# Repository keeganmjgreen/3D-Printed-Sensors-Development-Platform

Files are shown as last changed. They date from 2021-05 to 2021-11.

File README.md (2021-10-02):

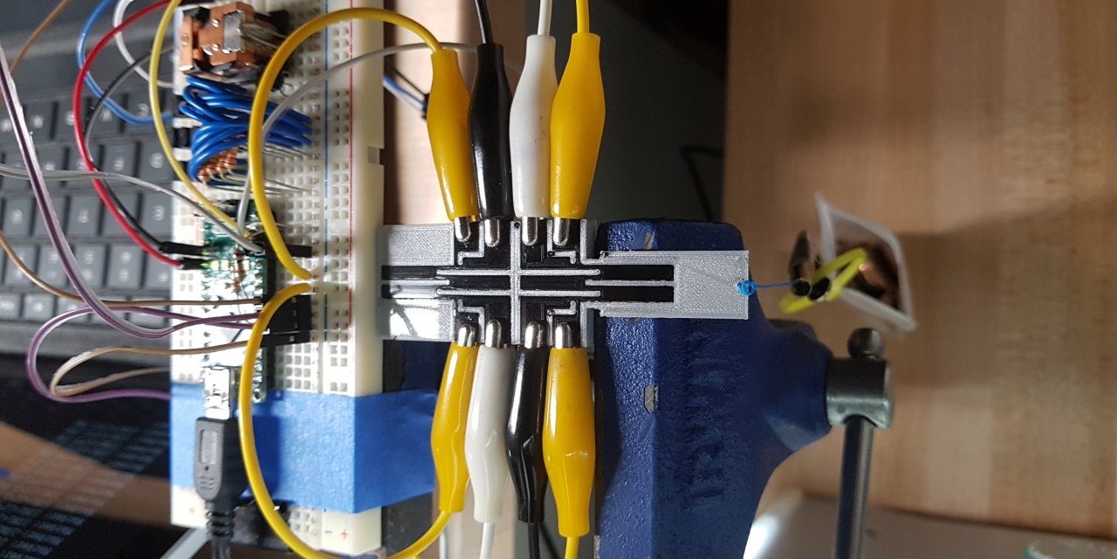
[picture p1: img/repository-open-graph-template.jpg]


----

# 3D Printed Sensors Development Platform

[Read the Docs project](https://3d-printed-sensors-development-platform.readthedocs.io/en/latest/index.html)



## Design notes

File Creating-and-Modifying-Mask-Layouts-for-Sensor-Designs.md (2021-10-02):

[Download as PDF](https://raw.githubusercontent.com/keeganmjgreen/3D-Printed-Sensors-Development-Platform/main/pdf/Creating-and-Modifying-Mask-Layouts-for-Sensor-Designs.pdf)

----

# Creating and Modifying 'Mask Layouts' for Sensor Designs

Please refer to the 'mask layouts' of our sensor designs as a starting point. They have been provided as image templates.

 1. Decide on the largest and/or most common/prevalent *resolution* $\lambda_{\,\textsf{macro}\,}$ expected for the mask layout. For example, 1 mm for most design features. \

 2. Estimate the bounding size of the mask layout. For example, layout height $H_{\,\textsf{layout}}$ = sensor width = 25 mm, layout width $W_{\,\textsf{layout}}$ = sensor length = 45 mm. \

 3. Using image editing software, create an image of height $H_{\,\textsf{layout}}\,/\,\lambda_{\,\textsf{macro}\,}$ pixels and width $W_{\,\textsf{layout}}\,/\,\lambda_{\,\textsf{macro}\,}$ pixels. Set its *image resolution* to $1\,/\,\lambda_{\,\textsf{macro}\,}$ pixels, for reference. Keep in mind the software units. For example:
    
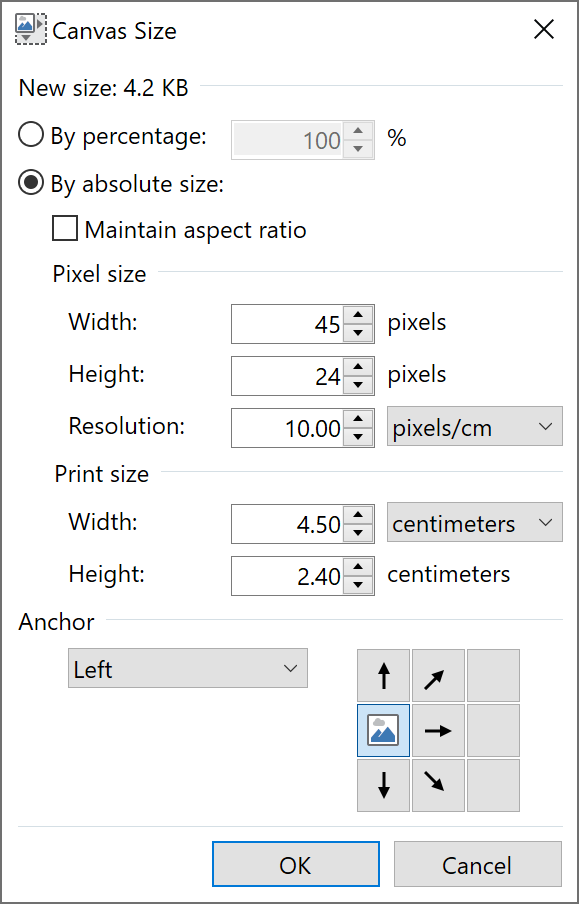
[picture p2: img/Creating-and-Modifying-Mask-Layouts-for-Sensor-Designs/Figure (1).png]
     \

 4. Enable the pixel grid and rulers, if available. Using the grid will make the mask layout easier to draw.
    
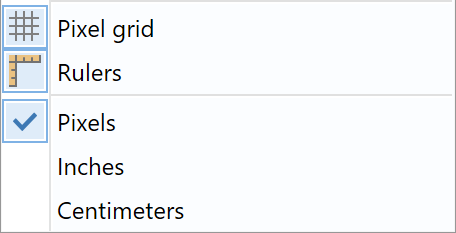
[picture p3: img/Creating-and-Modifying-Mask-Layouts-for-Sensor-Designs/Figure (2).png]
     \

 5. On a pixel scale, create the largest design features (of resolution $\lambda_{\,\textsf{macro}\,}$, that is) first. For example:
    
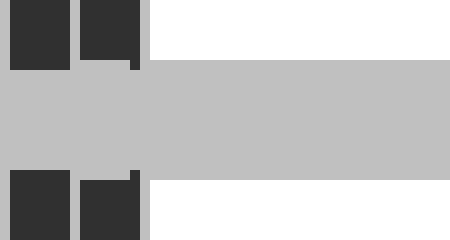
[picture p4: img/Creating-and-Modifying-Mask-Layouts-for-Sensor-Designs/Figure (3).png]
     \

 6. Resize the image to be of height $H_{\,\textsf{layout}}\,/\,\lambda_{\,\textsf{micro}\,}$ pixels and width $W_{\,\textsf{layout}}\,/\,\lambda_{\,\textsf{micro}\,}$ pixels, where $\lambda_{\,\textsf{micro}\,}$ is the smallest underlying resolution. Update its *image resolution* to $1\,/\,\lambda_{\,\textsf{micro}\,}$ pixels, for reference, again. Keep in mind the software units. Use the *nearest neighbor* resampling method and maintain the *aspect ratio*. For example:
    
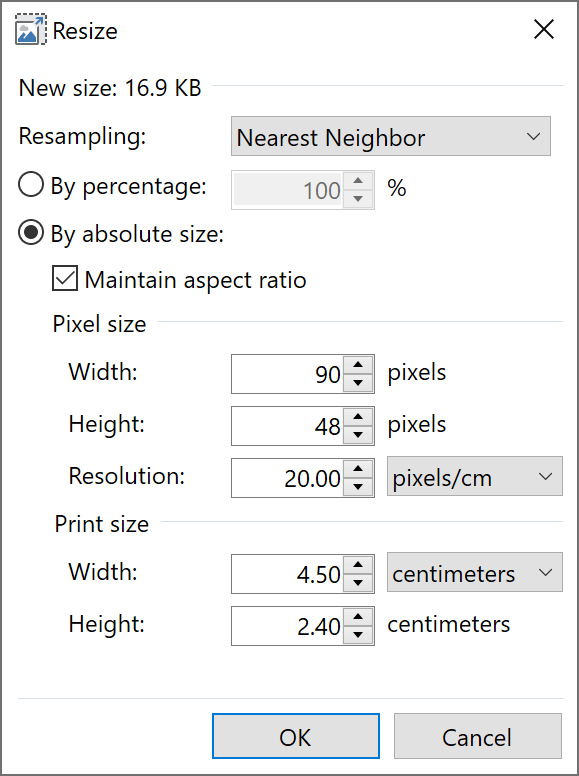
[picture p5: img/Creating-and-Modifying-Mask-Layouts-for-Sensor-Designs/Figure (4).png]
     \

 7. On the new pixel scale, create the smallest design features (of resolution $\lambda_{\,\textsf{micro}\,}$, that is). For example:
    
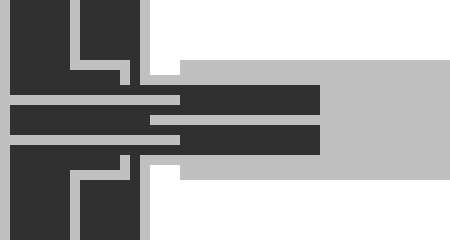
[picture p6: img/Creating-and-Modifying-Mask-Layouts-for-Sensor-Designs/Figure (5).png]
     \

Tip: Use named image layers (as analogous to *SolidWorks* features). For example:

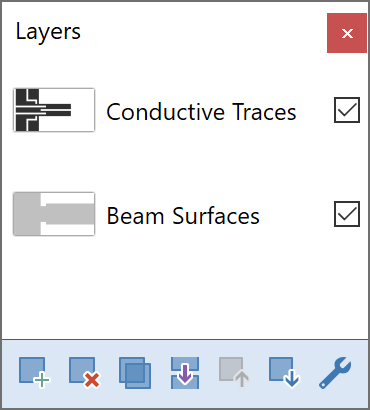
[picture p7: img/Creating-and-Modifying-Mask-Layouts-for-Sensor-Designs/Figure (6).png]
 \

----

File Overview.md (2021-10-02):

[Download as PDF](https://raw.githubusercontent.com/keeganmjgreen/3D-Printed-Sensors-Development-Platform/main/pdf/Overview.pdf)

----

# About This Manual #

This manual describes every aspect of the Pithon platform including how to customize, print, calibrate and use Pithon sensors. The manual starts with an overview of Pithon sensors. Next, the process of 3D printing sensors will be described, emphasizing strategies for improving reliability and consistency of printed sensors. Tools and resources for customizing sensors to your unique application will then be presented. Finally, calibration methods are provided to ensure that printed sensors are delivering reliable results. 

# Overview #

Pithon is a set of designs, tools, documentation, and software to allow anyone to customize and 3D print their own sensors. Monti 3D Printing Solutions currently offers support for temperature sensors, force sensors, and accelerometers. We are currently developing designs for a humidity sensor, environmental sensor which can measure temperature and humidity simultaneously, and a magnetic field sensor. These sensors should be released by the end of August 2021. Pithon is a fully modular embedded sensor platform wherein users can select which sensors and functionality they require, modify sensor designs to their unique application, and easily embed their sensors into any structure. The image below displays example Pithon sensors. 

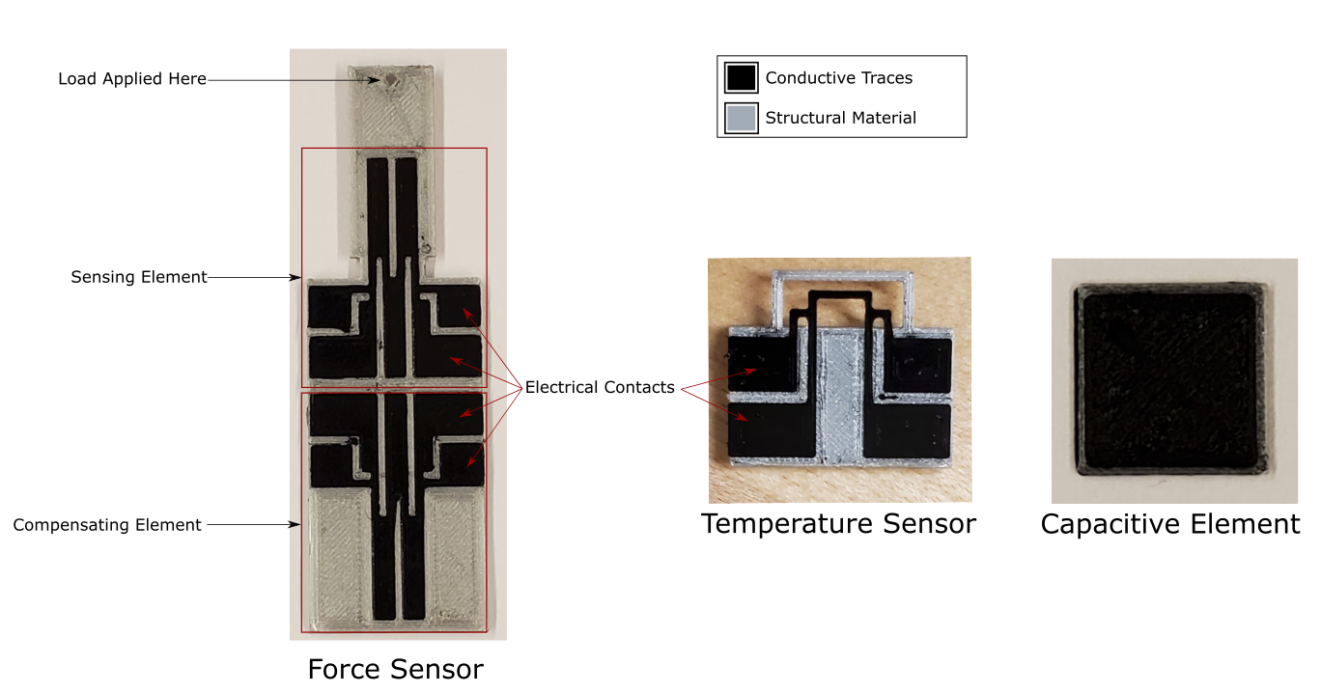
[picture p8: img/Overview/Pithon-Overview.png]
Pithon Overview


Using only 2 materials, a conductive and a structural 3D printing filament, Pithon sensors can be 3D printed in a single-step manufacturing process. After the sensors are produced, users can choose whether to perform additional steps to improve sensor performance, such as adding a metal proof mass to improve an accelerometer's sensitivity. Complete sensors can be printed for about $1 CAD in an hour. 

## Temperature Sensor ##

Pithon's temperature sensor features a small, but robust design. A protective covering, or shroud, protects the sensor in case an impact occurs. The sensor's small design allows for a rapid response to variations in temperature, making it ideal for applications that involve rapid heating and cooling cycles. This sensor is very sensitive to variations in temperature, its resistance increases ~1.5 times when the sensor is heated to 50 °C.

## Force Sensor ##

Our force sensor is a comprehensive design, automatically correcting force measurements for variations in environmental conditions, such as temperature. The force sensor consists of conductive traces along a cantilever beam. When a mass, or force, is applied to the free end of the beam, the beam will bend causing the conductive traces to either expand or compress, thereby changing their resistance. An optional Compensating Element is included that provides automatic compensation for variations in environmental conditions.

## Accelerometer ##

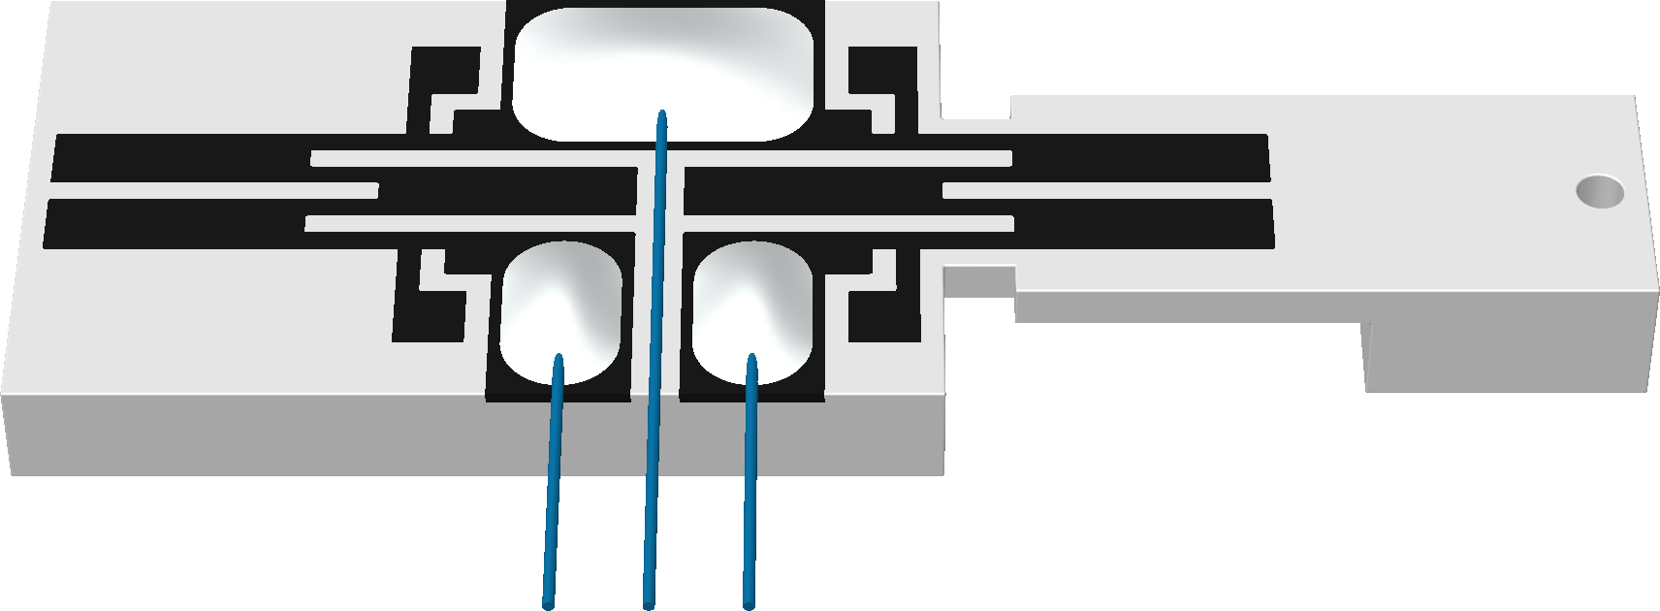
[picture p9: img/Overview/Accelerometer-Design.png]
Accelerometer Design


Pithon's accelerometer is similar in design to our force sensor. Users have the option of installing a metal ball in the accelerometer to improve its sensitivity. The ball is installed in a single-step process by pressing the ball into its corresponding hole. Monti 3D Printing Solutions is actively characterizing the performance of our accelerometers and will update this description with performance characteristics shortly.   

----

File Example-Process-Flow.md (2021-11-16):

[Download as PDF](https://raw.githubusercontent.com/keeganmjgreen/3D-Printed-Sensors-Development-Platform/main/pdf/Example-Process-Flow.pdf)

----

<iframe width="420" height="315" src="https://www.youtube.com/embed/nedxR-Wya6k" title="YouTube video player" frameborder="0" allow="accelerometer; autoplay; clipboard-write; encrypted-media; gyroscope; picture-in-picture" allowfullscreen></iframe>

# Example Process Flow

This section further explores the Pithon platform for 3D printed sensors. \
 \
How do implementations of the Pithon platform get made? How will you produce 3D printed sensors for yourself? What does the process look like? To answer these questions, we will walk through an example process flow. \

The process begins with continuous fabrication, building your design from the ground up using conductive and structural plastics. \

First, electrically conductive traces are deposited onto the 3D printing surface. These will make up the electrical terminals and sensing elements of your accelerometer and temperature sensor:

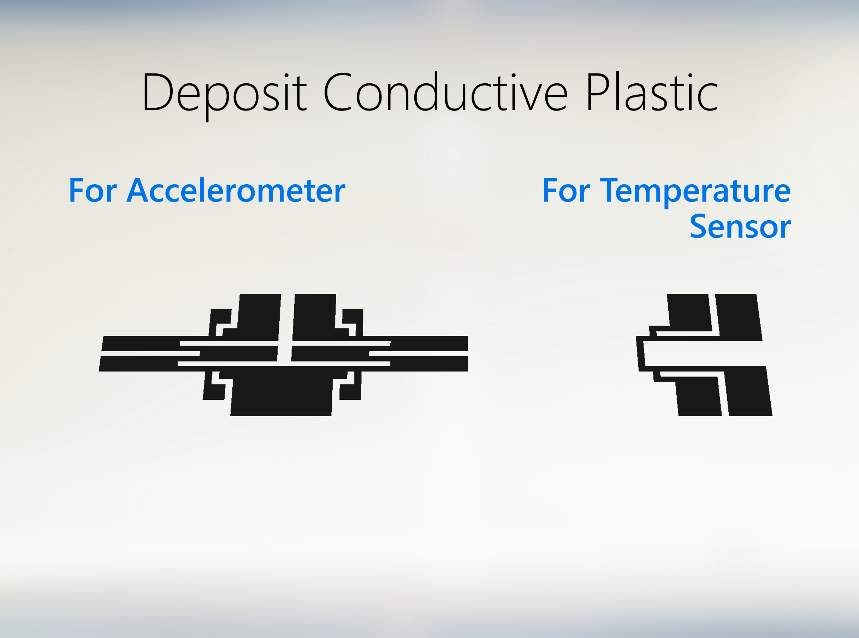
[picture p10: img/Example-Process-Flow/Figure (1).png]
Deposit Conductive Plastic
 \

The conductive traces are surrounded with with what will become your enclosing structure of arbitrary size and shape:

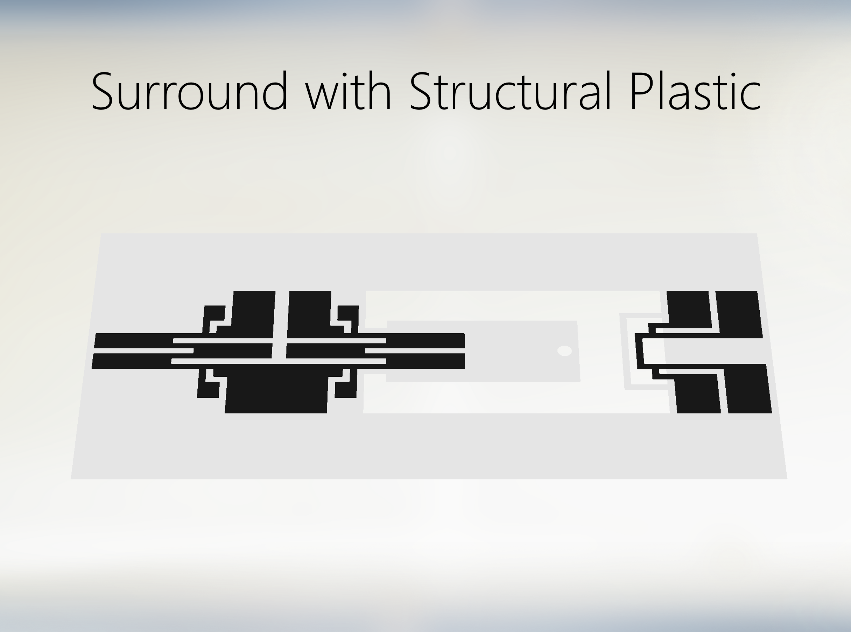
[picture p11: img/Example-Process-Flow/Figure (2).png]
Surround with Structural Plastic
 \

The conductive traces are covered as required with more of their enclosing structure:

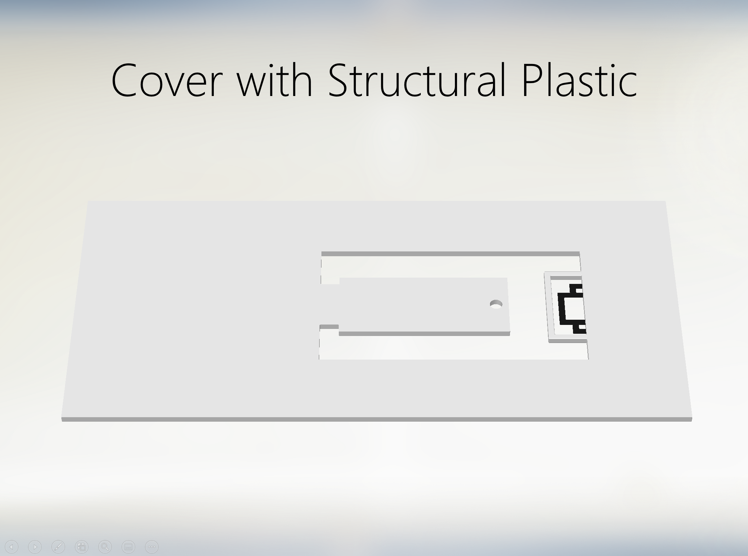
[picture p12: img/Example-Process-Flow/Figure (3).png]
Cover with Structural Plastic
 \

A cantilever beam for your accelerometer has been printed:

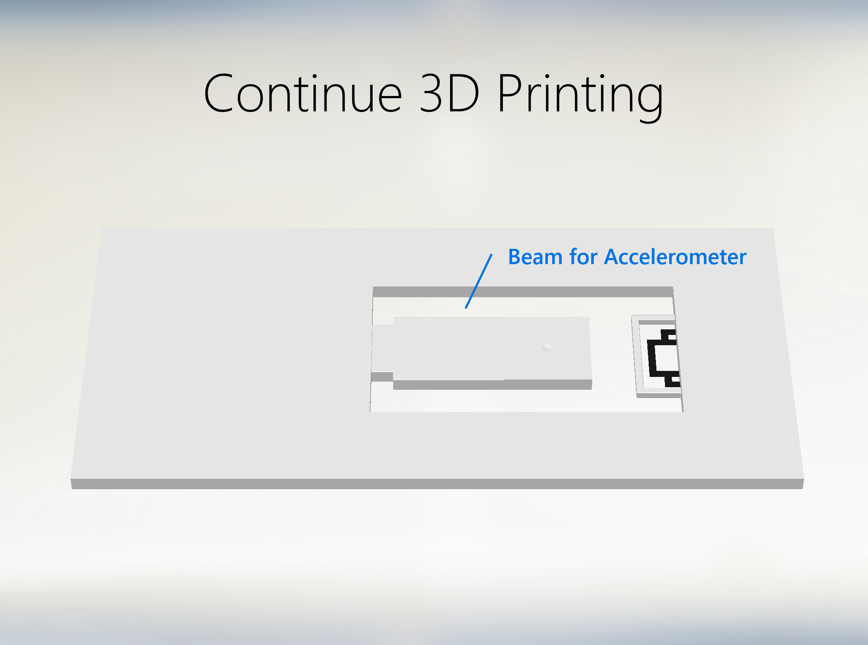
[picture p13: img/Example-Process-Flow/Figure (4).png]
Continue 3D Printing
 \

Now, the 3D printing process continues -- layer by layer -- leaving more space for a cavity:

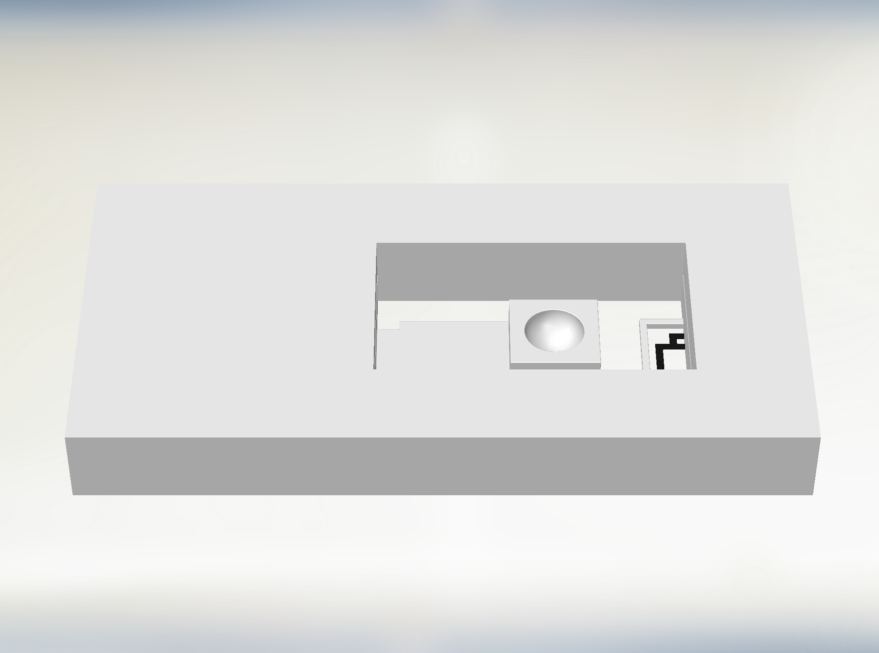
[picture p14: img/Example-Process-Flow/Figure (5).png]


By this point, the conductive 3D printing filament would have been swapped out for dissolvable filament for use as a temporary filler material to support upcoming layers. Alternatively, the cavity walls would slope both upward and *inward* to support subsequent layers, meaning that you wouldn't have to use a temporary support structure. \

You press-fit a steel ball into the space provided at the end of your accelerometer's cantilever beam:

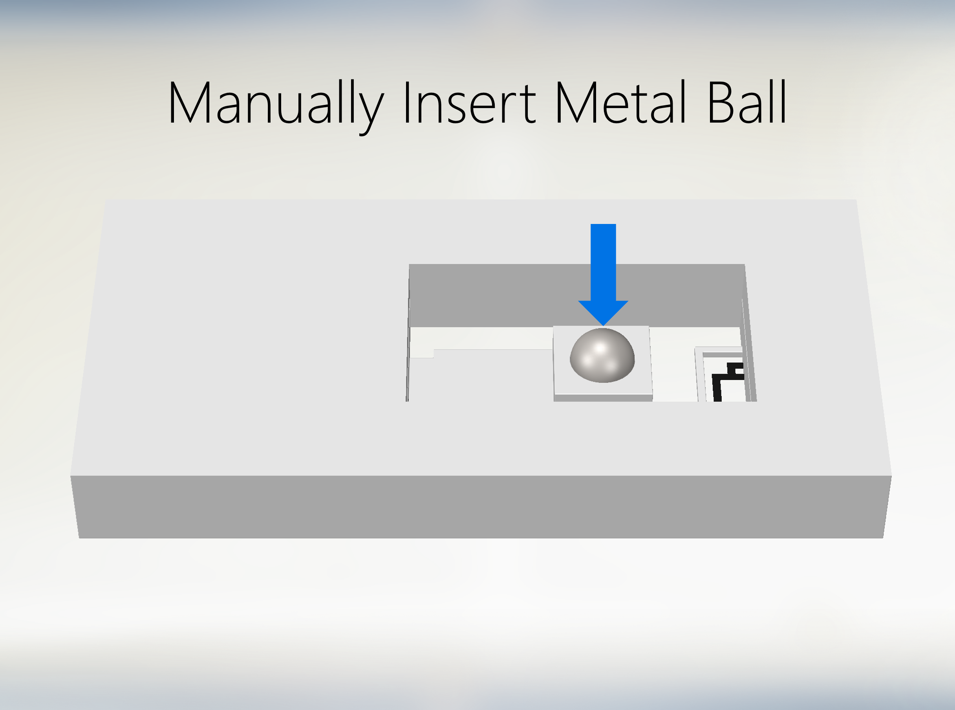
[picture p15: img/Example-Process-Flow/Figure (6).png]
Manually Insert Metal Ball


This will make it especially sensitive to acceleration. This weight is a *proof mass*. Because it is metallic, your accelerometer can also be used as a magnetic field sensor. \

The cavity is covered with the rest of your arbitrarily shaped enclosing structure:

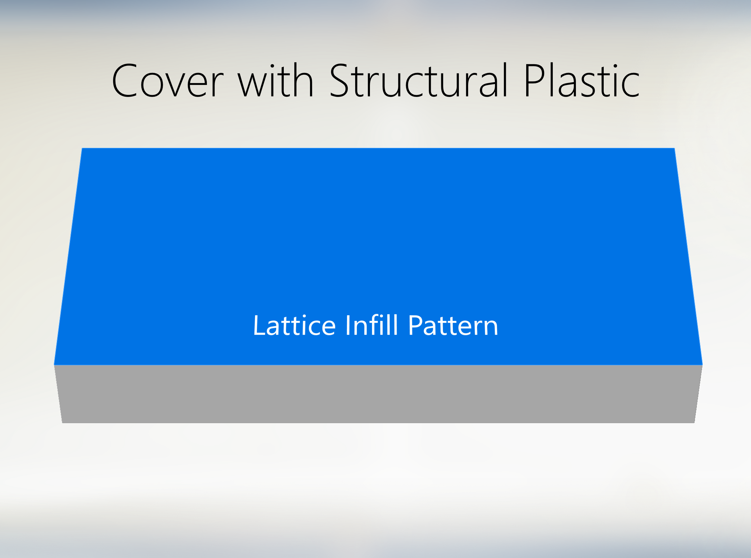
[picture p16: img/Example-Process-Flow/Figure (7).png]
Cover With Structural Plastic


Note that especially by this point, the 3D printed part would be partially made up of a lattice -- this is the *infill pattern*. \

The 3D printing process of our part is soon complete. \

You remove your part from the surface of your 3D printer. It was printed upside-down. This served four purposes:

 1. Made it so that any problems with the conductive printing filament were detected early.
 2. Made the conductive plastic adhere to the surface of your 3D printer better.
 3. Improved the surface finish of your embedded sensors.
 4. Allowed your sensing elements to be as thin as 60 microns, such as for your temperature sensor. \

A Pithon accelerometer and Pithon temperature sensor have been embedded into your arbitrary part. This design, for example, can be readily used for evaluation purposes as part of the Pithon platform:

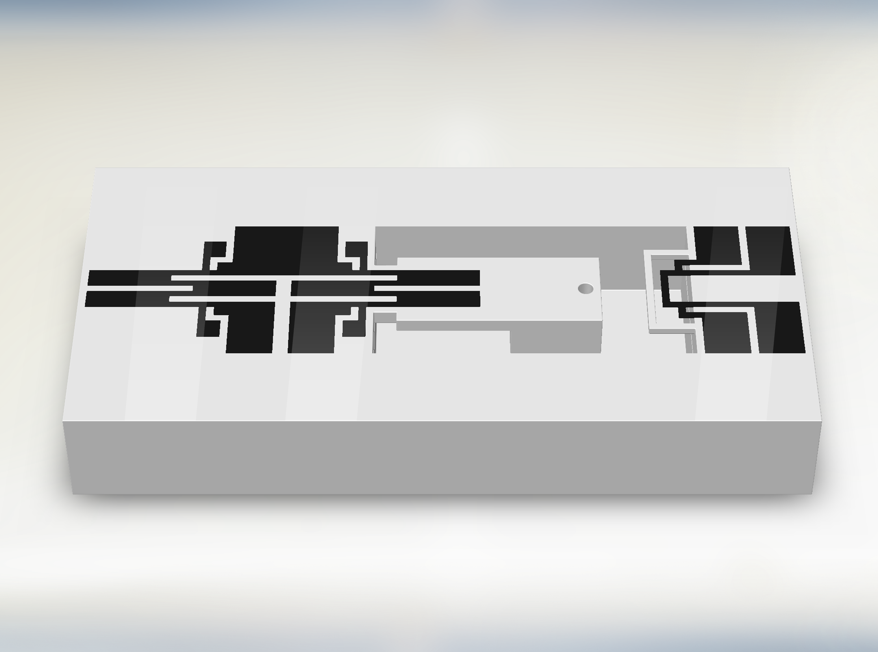
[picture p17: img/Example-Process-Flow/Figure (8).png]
 \

This is your embedded accelerometer:

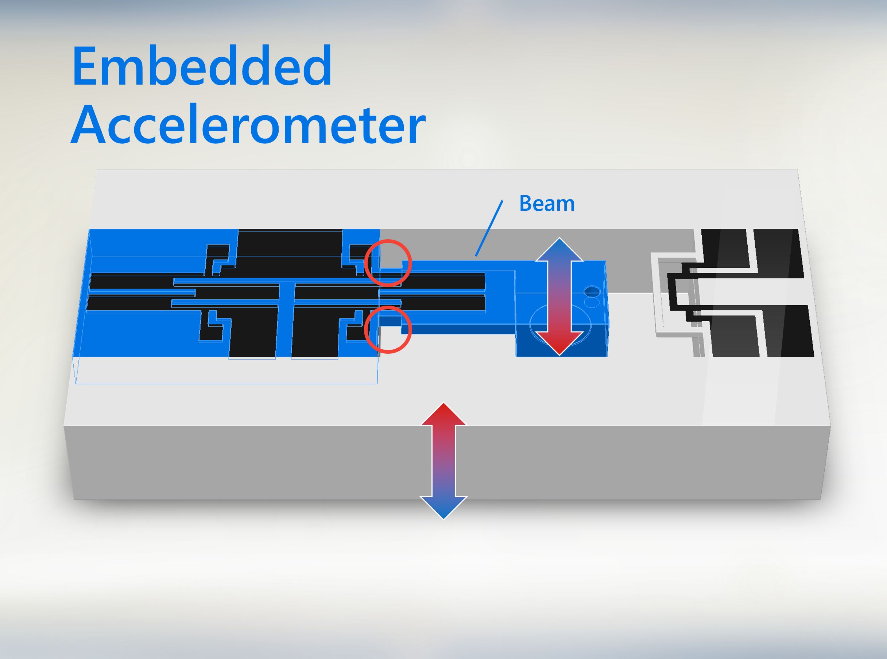
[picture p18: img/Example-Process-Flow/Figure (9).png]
Embedded Accelerometer


When the whole part speeds up or slows down, its cantilever beam bends up or down depending on the direction and amount of the acceleration it experiences. The material making up the top half of the beam gets compressed or stretched, especially at its base and on its surface. This is why two strategically sized notches are placed in the base as shown. They 'concentrate' its mechanical stress toward its sensing element, which is at the beam surface. This makes it more sensitive to acceleration.

The accelerometer may also be calibrated as a force sensor or magnetic field sensor under certain conditions (see end of section [**Pithon Accelerometer**](https://3d-printed-sensors-development-platform.readthedocs.io/en/latest/Pithon-Accelerometer.html)). \

This is your accelerometer's primary set of conductive traces:

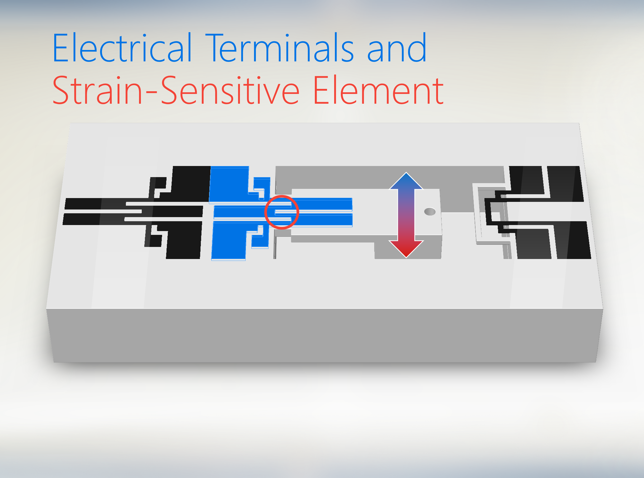
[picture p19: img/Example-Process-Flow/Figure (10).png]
Electrical Terminals and Strain-Sensitive Element


The zig-zag pattern in the middle is what forms its sensing element, a *strain gauge*, whose electrical resistance readily changes with mechanical strain. But the conductive traces' resistance also changes with temperature and humidity. \

This is where your accelerometer's secondary set of conductive traces comes into play:

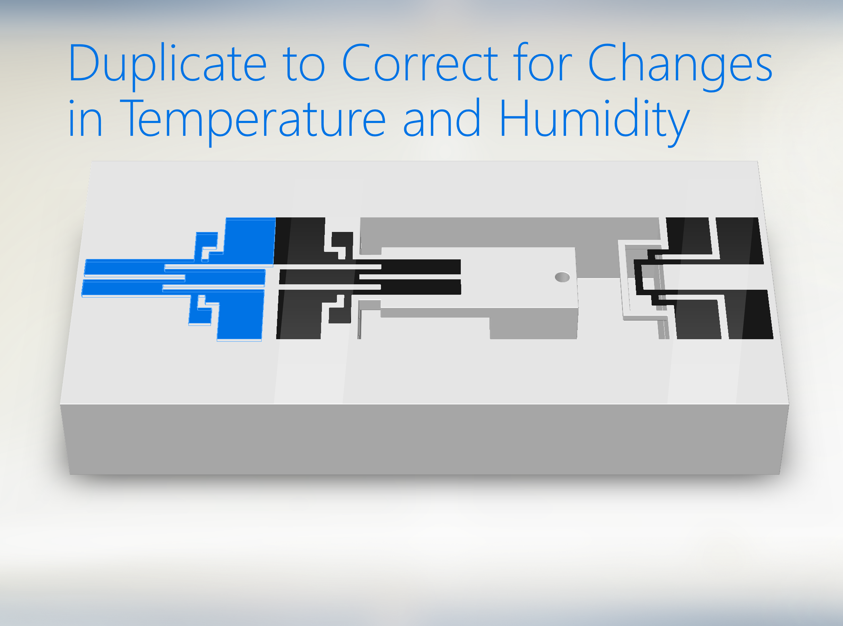
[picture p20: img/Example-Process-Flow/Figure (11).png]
Duplicate to Correct for Changes in Temperature and Humidity


The secondary set can share an electrical terminal with the primary set and is its mirror image. But unlike the primary set, it isn't on a flexible beam. Because of this, it isn't sensitive to absent mechanical strain -- just temperature and humidity. These two "environmental conditions" are shared by both sets of conductive traces. Since the primary set responds to acceleration and environmental conditions similarly, and this secondary set responds only to the same environmental conditions, the acceleration by itself becomes known. \

This is your embedded temperature sensor:

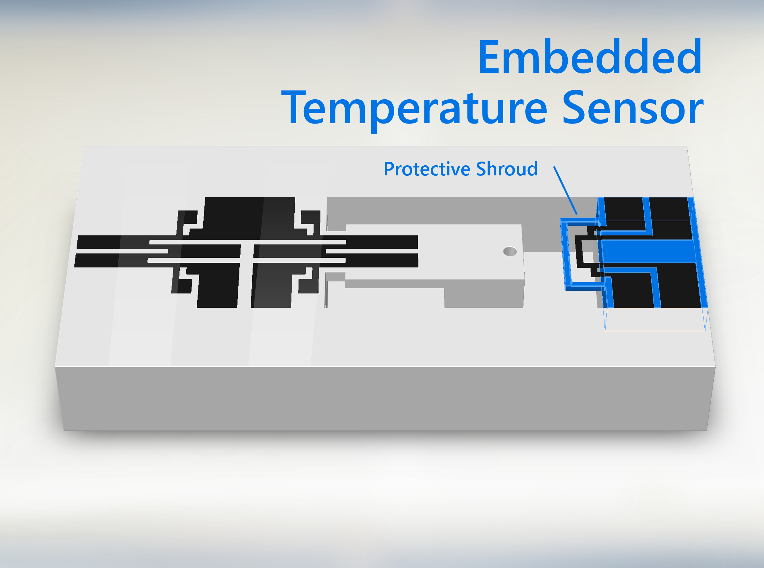
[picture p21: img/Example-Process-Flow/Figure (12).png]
Embedded Temperature Sensor


It measures the temperature of the surrounding air. Its sensing element is so small that it can point out of your arbitrarily-shaped structure too -- without getting in the way of anything. A kind of "guard rail" stops it from being damaged. Here, the sensing element is suspended midair in a cavity. Either case provides airflow. \

This is your temperature sensors' set of conductive traces:

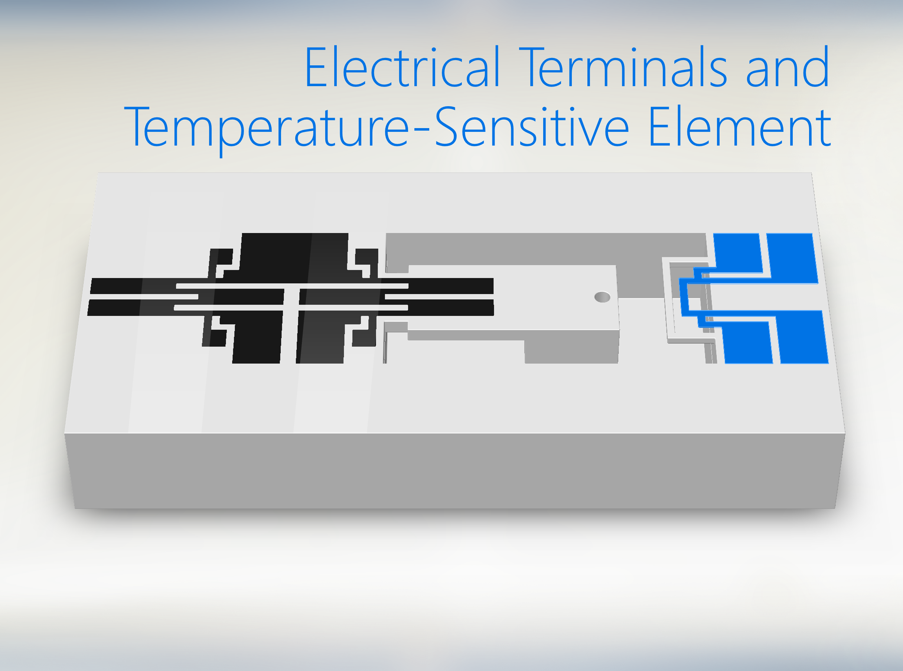
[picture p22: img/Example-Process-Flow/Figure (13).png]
Electrical Terminals and Temperature-Sensitive Element


The sensing element's electrical resistance changes with temperature. A method called *four-terminal sensing* or *Kelvin sensing* is used to factor out temperature-dependent *contact resistances*. \

Now, you put liquid conductive paint (or conductive epoxy) on the large contact pads formed by the conductive traces:

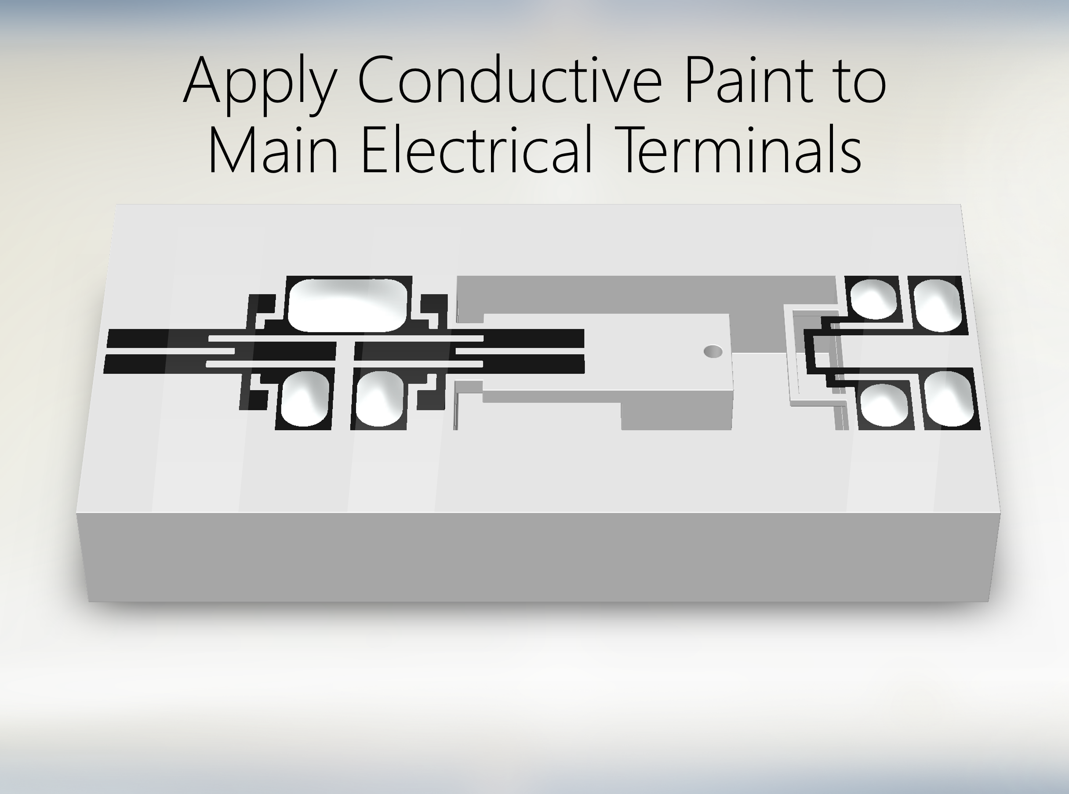
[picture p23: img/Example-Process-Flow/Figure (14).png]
Apply Conductive Paint to Main Electrical Terminals
 \

Before the conductive paint hardens, you bond wires to these contact pads:

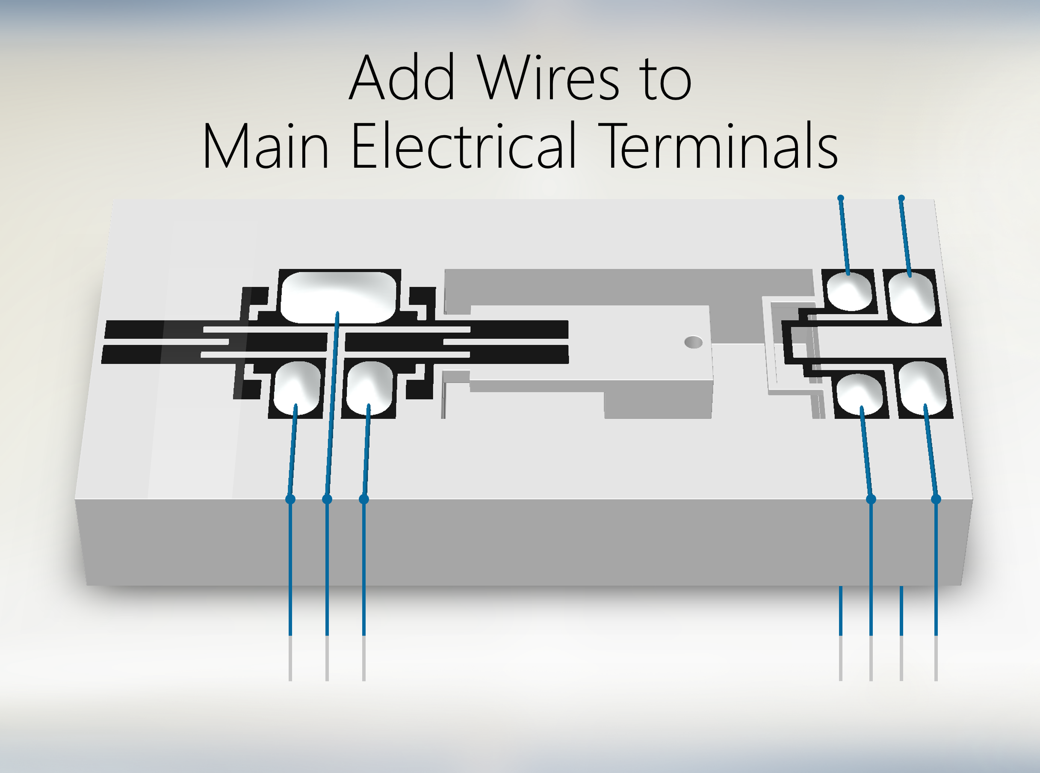
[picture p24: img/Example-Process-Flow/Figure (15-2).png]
Add Wires to Main Electrical Terminals
 \

Finally, you connect your physical implementation of the Pithon platform to your microcontroller as illustrated and, optionally, a different power source, such as a coin cell embedded in your 3D printed part.

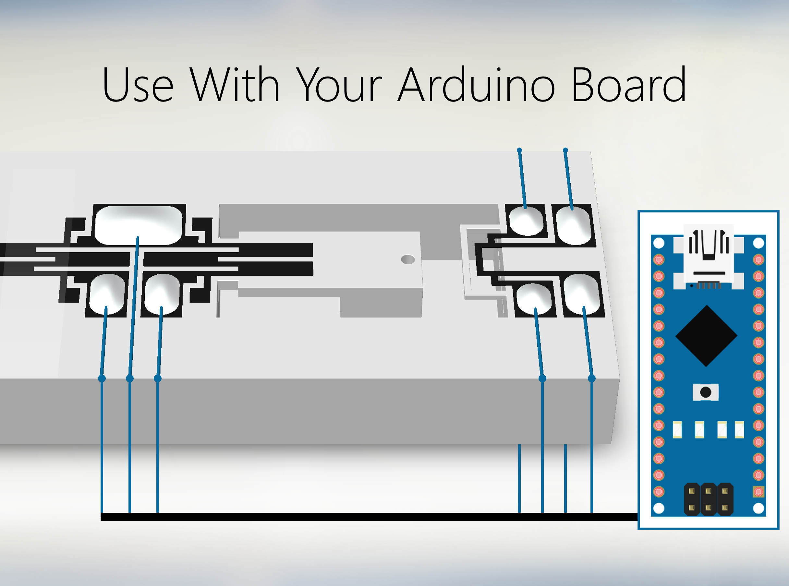
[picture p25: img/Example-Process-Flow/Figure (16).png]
Use With Your Microcontroller
 \
Not shown: Minimal interface electronics.

The microcontroller takes care of signal processing and digitally transmits the calibrated acceleration and temperature to where the data is needed. \

## Using Filler Material

The following is a modified version of the Pithon implementation in the example process flow. It uses 3D printed filler material -- dissolvable PVA filament -- as a support structure (highlighted blue) for what becomes the base of the cavity.



## Using Tapered Cavity Walls

The following is a modified version of the Pithon implementation in the example process flow. Its cavity has tapered walls to support subsequent layers, leaving potential for printing without a support structure. The top face of the enclosing structure is hidden to better show the cavity walls.



----

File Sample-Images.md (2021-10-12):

# Sample Images

A 1 cm² capacitance-based sensing component, printed right-side-up (unlike most other Pithon devices) as a parallel plate capacitor:

 \

A resistance test structure: <!--TODO-->

 \

A Pithon strain gauge / force sensor with large electrical contact pads for four-terminal sensing:



 \

Another Pithon strain gauge / force sensor, here with a secondary/reference set of conductive traces to account for different environmental conditions:

 \

An earlier iteration with smaller electrical contact pads and just two lengths of conductive traces as its sensing element:

 \

A variation of the device being resistance-tested under a probe station:

 \

The Pithon strain gauge / force sensor with wires bonded to its contact pads using conductive paint:



----

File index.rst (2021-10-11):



----

3D Printed Sensors Development Platform
=======================================

`GitHub repository <https://github.com/keeganmjgreen/3D-Printed-Sensors-Development-Platform>`_

----

.. toctree::
   :caption: Contents

   Glossary-of-Terms.md
   Introduction.md
   Overview.md
   Sample-Images.md
   Equipment-and-Materials.md
   Example-Process-Flow.md
   Development-Kit.md
   Creating-and-Modifying-Mask-Layouts-for-Sensor-Designs.md
   Tips-for-Optionally-Using-SolidWorks-to-Build-Upon-Sensor-Designs.md
   Using-SolidWorks-to-Customize-Your-Force-Sensor.md
   Pithon-Accelerometer.md
   Using-Conductive-Paint.md
   Preparing-Electrical-Contacts.md
   2-Terminal-Sensing-for-Real-Time-Data-Logging-Using-a-Microcontroller.md
   4-Terminal-Sensing-for-Real-Time-Data-Logging-Using-a-Microcontroller.md
   Calibrating-Your-Force-Sensor.md
   Pithon-Software.md
   Microcontroller-Based-Analog-Data-Logger-Interface.md
   calibrating_accelerometer.md
   printing_tumble_test.md
   Preparing-Thermal-Sensor-In-Cura.md
   Test-and-Calibrate-Thermal-Sensor.md
   Preparing-Capacitor-In-Cura.md
   Test-and-Calibrate-Capacitor.md
   Troubleshooting-Guide.md
   Frequently-Asked-Questions.md

----

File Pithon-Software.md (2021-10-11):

# Pithon Software

The software that has been developed as part of the Pithon platform as well as how you may use it will both be discussed. This is important because providing a breakdown of Pithon software by functionality is integral to realizing all of the testing, calibration, evaluation, and end use of Pithon sensors. All of the following C++/Arduino language and Python software were in the development of the Pithon platform for 3D printed sensors.

## C++/Arduino Language

A set of C++/Arduino programming language codes has been assembled. They span the tasks of isolating sensor resistance from its basic interface circuit, to relaying this data to your computer (over serial communication) for real-time monitoring, real-time plotting, and sensor calibration. After the interactive calibration process, automatically generated calibration code -- which defines a model of your sensor behavior -- converts the sensor response to the measurand. Signal processing and/or filtering is further implemented. The Arduino codes may also be used to:

 1. Implement an AC voltage source through onboard pulse-width modulation to run a Pithon environmental sensor,
    
    and

 2. Isolate its responses to environmental conditions while reading from a commercial environmental sensor in order to calibrate your own one.

Some of our microcontroller codes can be found [here](https://3d-printed-sensors-development-platform.readthedocs.io/en/latest/4-Terminal-Sensing-for-Real-Time-Data-Logging-Using-a-Microcontroller.html).

## Python

An open-source collection of simple-yet-effective and customizable software tools have been custom-made in the easy-to-use Python programming language. Choosing Python was a conscious decision for speed, accessibility, straightforward data manipulation and aggregation, and to suit the sensible needs of the open-source community.

**Microcontroller-Based Analog Data Logger Interface**

A Windows 10 interface for a microcontroller-based analog data logger with a wired conection to a computer has been developed to help you get up and running with your microcontroller and save/visualize its transmitted data. This timeseries data may be a sensor resistance measured by their microcontroller, or a calibrated measurement determined therefrom. The interface prompts you to connect your microcontroller (via USB) if it has not already been connected, notifies that the device was connected, reads from the device in real time over serial communication, and finally notifies that the device was disconnected. It then prepares the collected analog data. Most importantly, however, it makes the results accessible through a CSV file generated in the working directory as well as an interactive, in-browser plot with export options. This can help you calibrate, test, and troubleshoot your sensor setup.



The technical documentation of the microcontroller-based analog data logger interface is available [here](https://3d-printed-sensors-development-platform.readthedocs.io/en/latest/Microcontroller-Based-Analog-Data-Logger-Interface.html). \

Furthermore, Windows interfaces for collecting, preparing, and processing your force sensor calibration data has been developed to assist you in the calibration process. An older version of the calibration process before it was automated can be found [here](https://3d-printed-sensors-development-platform.readthedocs.io/en/latest/Calibrating-Your-Force-Sensor.html).

[**Pithon Data Collection Software**](https://github.com/keeganmjgreen/3D-Printed-Sensors-Development-Platform/tree/main/Force-Sensor-Calibration-Software/Force-Sensor-Calibration-Data-Collection)

Like the above interface, Pithon data collection software also establishes a communication link between your computer and microcontroller. Its main purpose is to assist you thereafter during the hands-on calibration step of collecting your raw sensor data, while recording how it was done for future reference.

 \
$\uparrow$ The command-line interface of Pithon force sensor calibration data collection software.

What this interface does is tedious to do using the Arduino Serial Monitor or similar. Moreover, a technical limitation observed of serial communication with the Arduino limits the stable data transfer speed in this context to a fraction of what it otherwise would be, meaning that so would be the sample rate of the sensor response. The highest possible/stable sample rate is desired to compensate for measurement noise.

[**Pithon Data Preparation Software**](https://github.com/keeganmjgreen/3D-Printed-Sensors-Development-Platform/tree/main/Force-Sensor-Calibration-Software/Force-Sensor-Calibration-Data-Preparation)

Pithon data preparation software organizes your collected data, summarizes the calibration process with statistics, and allows you to assess and verify the behavior of your sensors visually. This software tool does what would take hours to do in Excel as a painstaking manual data preparation process.

 \
$\uparrow$ The command-line interface of Pithon force sensor calibration data preparation software.

The sensor response samples are aggregated to eliminate the effect of measurement noise. To this end, the number of samples, the mean, and the statistical variance are all reported for each calibration segment. In the most recent version, a measure of sensor drift over time and the variance after accounting for sensor drift are also reported. In addition, a 'partitioned' timeseries plot of the sensor response over the course of the calibration process is generated, which you can conveniently save for future reference.

[**Pithon Data Processing Software**](https://github.com/keeganmjgreen/3D-Printed-Sensors-Development-Platform/tree/main/Force-Sensor-Calibration-Software/Force-Sensor-Calibration-Data-Processing)

Pithon data processing software generates a calibration curve to model the behavior of your sensors, along with its microcontroller code.

 \
$\uparrow$ The command-line interface of Pithon force sensor calibration data processing software.

A curve fit is performed on the aggregated data points that are generated by the previous interface. The curve delineates the maximum and minimum sensitivity values across the measurement range for which the sensor is calibrated, which are also reported in our most recent version as important sensor specifications. For the Pithon environmental sensor, the curve fit becomes a surface fit for each of temperature and humidity outputs. The software tool is set up to use polynomial-based curves, arbitrary mathematical functions, or even machine learning regressors (such as linear, nonlinear, decision tree, etc.) for its calibration models. The simplest model that effectively describes the data is to be used and its C++ code is automatically generated to be implemented on your microcontroller -- which is also used for signal processing. \

This completes the completes the Pithon calibration software process:



----

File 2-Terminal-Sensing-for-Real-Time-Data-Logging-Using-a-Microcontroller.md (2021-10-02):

[Download as PDF](https://raw.githubusercontent.com/keeganmjgreen/3D-Printed-Sensors-Development-Platform/main/pdf/2-Terminal-Sensing-for-Real-Time-Data-Logging-Using-a-Microcontrolle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)

----

# 2-Terminal Sensing for Real-Time Data Logging Using a Microcontroller

Due to input resistance, 2-terminal sensing is less consistent between sensors and less repeatable for a given sensor than 4-terminal sensing. However, it is simpler to set up, and more compact in implementation.

 

$\uparrow$ The wiring diagram showing the interface between a sensor with conductive traces for 2-terminal sensing and a microcontroller, of which `A0` -- `A1` are analog input pins. The microcontroller is programmed by and sends data -- namely, the resistance of the conductive traces between the 2 terminals -- to a computer, via USB over *serial communication*.

## Materials and Preparation

 -  A computer with the [Arduino IDE](https://www.arduino.cc/en/Guide/Environment) (recommended) installed
 -  A microcontroller with at least 1 analog input pin, such as an [Arduino](https://www.arduino.cc/en/Main/Products) (recommended) [Uno](https://www.arduino.cc/en/Main/arduinoBoardUno&gt) or [Nano](https://www.arduino.cc/en/pmwiki.php?n=Main/ArduinoBoardNano), and its USB cable
 -  A sensor with conductive traces for 2-terminal sensing
 -  A 10-kΩ or similar through-hole resistor of known value

**For Testing** and Evaluation Purposes...

 -  3 lengths of solid core hook-up wire with stripped ends
 -  3 insulated crocodile clip jumpers (double-ended)

**For Production** without a Circuit Board...

 -  3 lengths of solid core hook-up wire with stripped ends
 -  Soldering setup
     -  Soldering iron with stand
     -  Lead-free solder
     -  Soldering sponge or similar
 -  3 pieces of thin heat shrink tubing
 -  2 lengths of thin (e.g., 30 AWG) wire with stripped ends
 -  Conductive paint syringe
 -  Masking tape

## Instructions -- Assembly

Warning 

**WARNING:** Exercise extreme care when handling or using a soldering iron. Always assume that it may be plugged in and hot. Only those who are familiar with the safe use of a soldering iron should attempt to use it. Failure to follow proper practices may cause up to third degree burns.	

Caution 

**Caution:** Do not connect the voltage input pin (`Vin`) or voltage output pin (`5V`) pins of your microcontroller to its electrical ground (`GND`) pin. Failure to follow this instruction will potentially result in permanent damage to the microcontroller and any connected devices.

**For Testing** and Evaluation Purposes...

 1. Connect your hook-up wires to the `GND`, `A1`, and `5V` pins of your microcontroller.
    
 2. Connect your crocodile clip jumpers to the hook-up wires.
    
 3. Connect your resistor midway through the `A1` wire assembly.
    
 4. Connect the end of the `GND` wire assembly to the resistor.
    
 5. Connect the ends of the remaining wire assemblies, in order, to terminals `T1` -- `T2` of your 2-terminal sensor.

**For Production** without a Circuit Board...

 1. Connect your hook-up wires to the `GND`, `A1`, and `5V` pins of your microcontroller. \
    Slip on your heat shrink tubing if necessary at this point.
    
 2. Solder your thin wire to the latter 2 hook-up wires.
    
 3. Solder your resistor midway through the `A1` wire assembly.
    
 4. Solder the `GND` hook-up wire to the resistor.
    
    Apply the heat shrink tubing around all connections by evenly heating it using your soldering iron.
    
 5. Connect the ends of the remaining wire assemblies, in order, to terminals `T1` -- `T2` of your 2-terminal sensor.
    
     1. Coil the stripped ends of your thin wires into loops.
     2. Carefully rest the loops on the center of the matching terminals' contact pads, holding the wires and sensor down using masking tape.
     3. Carefully cover the wire loops with conductive paint within the borders of the contact pads.
     4. Wait for your conductive paint to fully dry/harden.
    
    See also **Using Conductive Paint** and **Preparing Electrical Contacts**.

If you are using an Arduino microcontroller, open its IDE on your computer and plug in your board using its USB cable.

## Instructions -- Programming

If you are using an Arduino microcontroller, upload the following code to it using the its IDE, after which it will begin running onboard.

``` c++
float R_series = 10e3;  // Known value of resistor in series with 2-terminal sensor.

float V_1;

float I;
float V_sens;
float R_sens;

void setup()
{
    Serial.begin(9600);   // Open communication with a computer via USB or with another device via UART.
}
void loop()
{
    V_1 = analogRead(1);  // Measured voltage across series resistor.
    
    I = V_1 / R_series;   // Calculated current through both series resistor and 2-terminal sensor.
    V_sens = 5 - V_1;     // Calculated voltage across 2-terminal sensor.
    R_sens = V_sens / I;  // Calculated resistance of 2-terminal sensor.
        
```

If you are using the Arduino *Serial Plotter*, append the following code.

``` c++
    Serial.print("R_sens:");
    Serial.print(R_sens);
    Serial.print("\t");
    
    Serial.print("lower:");
    Serial.print(0);
    Serial.print("\t");
    
    Serial.print("upper:");
    Serial.print(10e3);
    Serial.print("\r\n");
}
```

 -  Or download the complete sample code: [*2_Terminal_Sensing_for_Real_Time_Data_Logging_Using_Arduino_Serial_Plotter.ino*](https://raw.githubusercontent.com/keeganmjgreen/3D-Printed-Sensors-Development-Platform/main/2_Terminal_Sensing_for_Real_Time_Data_Logging_Using_Arduino_Serial_Plott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)

If you are using the Arduino *Serial Monitor*, append the following code.

``` c++
    Serial.println(R_sens);
}
```

 -  Or download the complete sample code: [*2_Terminal_Sensing_for_Real_Time_Data_Logging_Using_Arduino_Serial_Monitor.ino*](https://raw.githubusercontent.com/keeganmjgreen/3D-Printed-Sensors-Development-Platform/main/2_Terminal_Sensing_for_Real_Time_Data_Logging_Using_Arduino_Serial_Monit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)

### Additional Resources

[Arduino Language Reference](https://www.arduino.cc/reference/)

 -  Communication -- [Serial](https://www.arduino.cc/reference/en/language/functions/communication/serial/)
 -  Analog input/output -- [analogRead()](https://www.arduino.cc/reference/en/language/functions/analog-io/analogread/)

## Real-Time Data Logging

 -  Use the Arduino IDE Serial Plotter ([online reference](https://arduinogetstarted.com/tutorials/arduino-serial-plotter)) to visualize live data over a recent period of time.
 -  Use the Arduino IDE Serial Monitor ([online reference](https://arduinogetstarted.com/tutorials/arduino-serial-monitor)) to write live timeseries data that can be copied and saved. Disable its *Show timestap* option beforehand.

In either case, set the *baud rate* to "9600 baud" to match the Arduino code and the *line ending* to "Both NL & CR" beforehand.

The Arduino serial plotter and monitor cannot be used simultaneously.

----

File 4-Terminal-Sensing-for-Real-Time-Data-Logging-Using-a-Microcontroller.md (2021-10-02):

[Download as PDF](https://raw.githubusercontent.com/keeganmjgreen/3D-Printed-Sensors-Development-Platform/main/pdf/4-Terminal-Sensing-for-Real-Time-Data-Logging-Using-a-Microcontrolle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)

----

# 4-Terminal Sensing for Real-Time Data Logging Using a Microcontroller

4-terminal sensing is slightly more complicated to set up than 2-terminal sensing and less compact in implementation. However, it is more consistent between sensors and more repeatable for a given sensor. It virtually eliminates the effect of contact resistance and other input resistances on the measurement of a resistive sensing element.

 

$\uparrow$ The wiring diagram showing the interface between a sensor with conductive traces for 4-terminal sensing and a microcontroller, of which `A0` -- `A3` are analog input pins. The microcontroller is programmed by and sends data -- namely, the resistance of the sensing element within the conductive traces -- to a computer, via USB over *serial communication*.

## Materials and Preparation

 -  A computer with the [Arduino IDE](https://www.arduino.cc/en/Guide/Environment) (recommended) installed
 -  A microcontroller with at least 3 analog input pins, such as an [Arduino](https://www.arduino.cc/en/Main/Products) (recommended) [Uno](https://www.arduino.cc/en/Main/arduinoBoardUno&gt) or [Nano](https://www.arduino.cc/en/pmwiki.php?n=Main/ArduinoBoardNano), and its USB cable
 -  A sensor with conductive traces for 4-terminal sensing
 -  A 10-kΩ or similar through-hole resistor of known value

**For Testing** and Evaluation Purposes...

 -  5 lengths of solid core hook-up wire with stripped ends
 -  5 insulated crocodile clip jumpers (double-ended)

**For Production** without a Circuit Board...

 -  5 lengths of solid core hook-up wire with stripped ends
 -  Soldering setup
     -  Soldering iron with stand
     -  Lead-free solder
     -  Soldering sponge or similar
 -  5 pieces of thin heat shrink tubing
 -  4 lengths of thin (e.g., 30 AWG) wire with stripped ends
 -  Conductive paint syringe
 -  Masking tape

## Instructions -- Assembly

Warning 

**WARNING:** Exercise extreme care when handling or using a soldering iron. Always assume that it may be plugged in and hot. Only those who are familiar with the safe use of a soldering iron should attempt to use it. Failure to follow proper practices may cause up to third degree burns.	

Caution 

**Caution:** Do not connect the voltage input pin (`Vin`) or voltage output pin (`5V`) pins of your microcontroller to its electrical ground (`GND`) pin. Failure to follow this instruction will potentially result in permanent damage to the microcontroller and any connected devices.



$\uparrow$ Pinout of a 4-terminal sensor.

**For Testing** and Evaluation Purposes...

 1. Connect your hook-up wires to the `GND`, `A1`, `A2`, `A3`, and `5V` pins of your microcontroller.
    
 2. Connect your crocodile clip jumpers to the hook-up wires.
    
 3. Connect your resistor midway through the `A1` wire assembly.
    
 4. Connect the end of the `GND` wire assembly to the resistor.
    
 5. Connect the ends of the remaining wire assemblies, in order, to terminals `T1` -- `T4` of your 4-terminal sensor.

**For Production** without a Circuit Board...

 1. Connect your hook-up wires to the `GND`, `A1`, `A2`, `A3`, and `5V` pins of your microcontroller.
    Slip on your heat shrink tubing if necessary at this point.
    
 2. Solder your thin wire to the latter 4 hook-up wires.
    
 3. Solder your resistor midway through the `A1` wire assembly.
    
 4. Solder the `GND` hook-up wire to the resistor.
    
    Apply the heat shrink tubing around all connections by evenly heating it using your soldering iron.
    
 5. Connect the ends of the remaining wire assemblies, in order, to terminals `T1` -- `T4` of your 4-terminal sensor.
    
     1. Coil the stripped ends of your thin wires into loops.
     2. Carefully rest the loops on the center of the matching terminals' contact pads, holding the wires and sensor down using masking tape.
     3. Carefully cover the wire loops with conductive paint within the borders of the contact pads.
     4. Wait for your conductive paint to fully dry/harden.
    
    See also **Using Conductive Paint** and **Preparing Electrical Contacts**.

If you are using an Arduino microcontroller, open its IDE on your computer and plug in your board using its USB cable.

## Instructions -- Programming

If you are using an Arduino microcontroller, upload the following code to it using the its IDE, after which it will begin running onboard.

``` c++
float R_series = 10e3;  // Known value of resistor in series with 4-terminal sensor.

float V_1;
float V_2;
float V_3;

float I;
float V_elem;
float R_elem;

void setup()
{
    Serial.begin(9600);   // Open communication with a computer via USB or with another device via UART.
}
void loop()
{
    V_1 = analogRead(1);  // Measured voltage across series resistor.
    V_2 = analogRead(2);  // Measured voltage looking into the 4-terminal sensor at terminal `T2`.
    V_3 = analogRead(3);  // Measured voltage looking into the 4-terminal sensor at terminal `T3`.
    
    I = V_1 / R_series;   // Calculated current through both series resistor and 4-terminal sensor.
    V_elem = V_3 - V_2;   // Calculated voltage across sensing element.
    R_elem = V_elem / I;  // Calculated resistance of sensing element.
    
```

If you are using the Arduino *Serial Plotter*, append the following code.

``` c++
    Serial.print("R_sens:");
    Serial.print(R_sens);
    Serial.print("\t");
    
    Serial.print("lower:");
    Serial.print(0);
    Serial.print("\t");
    
    Serial.print("upper:");
    Serial.print(10e3);
    Serial.print("\r\n");
}
```

 -  Or download the complete sample code: [*4_Terminal_Sensing_for_Real_Time_Data_Logging_Using_Arduino_Serial_Plotter.ino*](https://raw.githubusercontent.com/keeganmjgreen/3D-Printed-Sensors-Development-Platform/main/4_Terminal_Sensing_for_Real_Time_Data_Logging_Using_Arduino_Serial_Plott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)

If you are using the Arduino *Serial Monitor*, append the following code.

``` c++
    Serial.println(R_sens);
}
```

 -  Or download the complete sample code: [*4_Terminal_Sensing_for_Real_Time_Data_Logging_Using_Arduino_Serial_Monitor.ino*](https://raw.githubusercontent.com/keeganmjgreen/3D-Printed-Sensors-Development-Platform/main/4_Terminal_Sensing_for_Real_Time_Data_Logging_Using_Arduino_Serial_Monit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)

### Additional Resources

[Arduino Language Reference](https://www.arduino.cc/reference/)

 -  Communication -- [Serial](https://www.arduino.cc/reference/en/language/functions/communication/serial/)
 -  Analog input/output -- [analogRead()](https://www.arduino.cc/reference/en/language/functions/analog-io/analogread/)

## Real-Time Data Logging

 -  Use the Arduino IDE Serial Plotter ([online reference](https://arduinogetstarted.com/tutorials/arduino-serial-plotter)) to visualize live data over a recent period of time.
 -  Use the Arduino IDE Serial Monitor ([online reference](https://arduinogetstarted.com/tutorials/arduino-serial-monitor)) to write live timeseries data that can be copied and saved. Disable its *Show timestap* option beforehand.

In either case, set the *baud rate* to "9600 baud" to match the Arduino code and the *line ending* to "Both NL & CR" beforehand.

The Arduino serial plotter and monitor cannot be used simultaneously.

----

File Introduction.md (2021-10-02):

[Download as PDF](https://raw.githubusercontent.com/keeganmjgreen/3D-Printed-Sensors-Development-Platform/main/pdf/Introduction.pdf)

----

# Copyright #

&copy; Monti 3D Printing Solutions. All rights reserved. This manual may not be reproduced in whole or in part, by any means, without written permission from Monti 3D Printing Solutions.

# Disclaimer #

Please read and understand all information presented in this manual prior to attempting to print a Pithon sensor. Failure to adhere to the procedures outlined in this documentation may lead to personal injury, poor quality, or non-functional sensors, or damage to the 3D printer or other equipment. All operators using a 3D printer to manufacture any aspect of Pithon must be well trained in the use of their 3D printer and follow the manufacturer's specifications and guidelines. Pithon sensors, structures, and parts must not be left unattended while printing. Monti does not assume responsibility for any loss, injury, or damage arising from the production or use of any Pithon sensor. Pithon is not intended for use in safety critical applications; use at your own risk.

All information provided within this manual has been gathered from reliable sources and internal development, however Monti provides no warranty of the correctness of any information provided in this manual.

# Warranty Information #

Monti 3D Printing Solutions offers no warranty to any sensor produced or calibrated through Pithon manufacturing methods. Additionally, Monti provides no warranty for any aspect of all Pithon manufacturing and calibration processes. Subscription and availability of Pithon services -- including but not limited to documentation -- may be cancelled at any time, for any reason.

# Customer Support #

Additional documentation and resources about Pithon on our online support pages:
*https://3d-printed-sensors-development-platform.readthedocs.io/en/latest/index.html*.

Please address any questions to Monti's Design Team at kmgreen@sfu.ca.

# Safety #

## Safety Messages ##

This manual displays warnings and safety related notices in the following format.

Notice 

The above symbol indicates that damage to property may occur if the provided precautions are not taken.

Caution 

The above symbol indicates that minor injuries may occur if the provided precautions are not taken. \

Danger 

The above symbol indicates a high probability that major injury or death may occur if the provided precautions are not adhered to.

Warning \
 \
The above warning provides general safety related information or measures.

As applicable, these safety messages will be listed in order of highest risks first.

## Hazards ##

### Manufacturing Hazards ###

Manufacturing hazards are as follows.

Electricity hazard \
 \
Improperly installed 3D printers may present a risk of electrocution. Ensure the 3D printer is installed and operated as per the Manufacturer's specification as described in the 3D printer's User Manual.

Hot surface \
 \
3D printers have nozzles that reach temperatures above 200°C, and some models have heated print beds. Refer to your 3D printer's User Manual on how to operate the device safely.

Crushing of hands \
 \
3D printers have multiple moving parts, that may damage objects or body parts caught in their motion. Always operate 3D printer as specified in their User Manual.

Toxic material  \
 \
3D printing filaments may release volatile organic compounds (VOCs) during the printing process. VOCs can cause symptoms including headache, fatigue, and confusion. Follow all safety precautions outlined in the material safety data sheet (MSDS) and your 3D printer's User Manual.

### Operating Hazards ###

Operating hazards are as follows.

Electricity hazard \
 \
Laboratory-grade power sources can generate power sufficient to cause electrocution. Always operate power sources and measurement equipment as per manufacturer's specifications.

Hot surface \
 \
When applying a larger power, above Pithon's rated voltage and current limits, the sensor may self-heat to high temperatures. Do not handle or touch any part of the Pithon sensor when applying a high voltage or current. \

----

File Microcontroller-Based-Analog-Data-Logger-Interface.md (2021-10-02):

[Download as PDF](https://raw.githubusercontent.com/keeganmjgreen/3D-Printed-Sensors-Development-Platform/main/pdf/Microcontroller-Based-Analog-Data-Logger-Interface.pdf)

----

# Microcontroller-Based Analog Data Logger Interface

We developed a Windows 10 interface in Python for a microcontroller-based analog data logger with a wired connection to a computer. The program may be run directly by launching [`Microcontroller_Based_Analog_Data_Logger_Interface.pyw`](https://raw.githubusercontent.com/keeganmjgreen/3D-Printed-Sensors-Development-Platform/main/Microcontroller_Based_Analog_Data_Logger_Interface.pyw) or, naturally, by executing the following command.

```bash
$ python Microcontroller_Based_Analog_Data_Logger_Interface.pyw
```

Our interface is not real-time (beyond the sense that serial communication is not real-time). The logged data is plotted only after it is collected, not *as* it is collected. We are attempting to add this capability. Alternatively, or as a temporary workaround, we are adapting/using the Arduino IDE serial plotter and others.

The interface prompts you to connect the microcontroller (via USB) such as an Arduino if it has not already been connected, notifies that the device *was* connected, reads from the device over serial communication, and finally notifies that the device was disconnected (all Subsection 2). It then prepares the collected analog data (Subsection 3). Lastly, it makes the results accessible through a `.CSV` file generated in your working directory as well as an interactive, in-browser plot with export options (Subsection 4).

These features can be broken down by going through its library imports as follows.

## 1. Library Imports in Order of Appearance

The user is to at least be notified that the data logger was connected and disconnected (via USB). `win10toast` by Jithu Jacob is a Python library ([PyPI](https://pypi.org/project/win10toast/), [GitHub](https://github.com/jithurjacob/Windows-10-Toast-Notifications)) for displaying Windows 10 toast notifications.

```python
from win10toast import ToastNotifier
```

On the other hand, `plyer.notification` shows new notification senders for every notification sent.

For reasons that will become apparent, timer functionality is to be used. `time` is a standard Python library ([Python documentation](https://docs.python.org/3/library/time.html)) for time access (and conversions, for that matter).

```python
from time import time
```

To read from the data logger, [serial communication](https://en.wikipedia.org/wiki/Serial_communication) is to be used. `pySerial` by Chris Liechti is a Python library ([PyPI](https://pypi.org/project/pyserial/), [GitHub](https://github.com/pyserial/pyserial), [documentation](https://pyserial.readthedocs.io/en/latest/pyserial.html)) that encapsulates access to computer [serial ports](https://en.wikipedia.org/wiki/Serial_port), including emulated ones such as those created by USB.

```python
from serial import Serial
```

The received analog data is to be prepared before being made accessible.

```python
import numpy  as np
import pandas as pd
```

`pandas`, for instance, can be used to calculate a moving average to smooth the data.

The prepared data is to be made accessible through an interactive, in-browser plot. `plotly` by the [technical computing company](https://plotly.com/) of the same name is a Python library ([PyPI](https://pypi.org/project/plotly/), [documentation](https://plotly.com/graphing-libraries/)) used to style interactive graphs.

```python
import plotly.graph_objects as go
```

## 2. Minimal User Interface | Reading from the Data Logger

To start with, initialize an instance of the *toast notifier* class using a memorable name:

```python
toaster = ToastNotifier()
```

This class has a `show_toast` method which is to be used. Among other arguments, it accepts a notification `title`, a notification `msg`, and an optional boolean specifying whether or not the showing of the notification (in its entire duration) is to be `threaded` ([reference](https://en.wikipedia.org/wiki/Thread_(computing))) with further Python instructions in this module (which calls `show_toast`). We found that the notification message itself (not its title) is actually optional, being truly omitted by specifying `msg` to be a non-empty 'empty' string such as `' '`. Method `show_toast` returns a boolean representing whether a notification is sent successfully or not (i.e., if one is already being shown, at least from Python). We also found that initializing multiple instances of the `ToastNotifier` class does not allow multiple corresponding notifications to appear simultaneously in the same way.

Now, specify the chosen 9600 / [8-N-1](https://en.wikipedia.org/wiki/8-N-1) serial communication ([COM](https://en.wikipedia.org/wiki/COM_(hardware_interface))) port:

```python
port = 'COM4'
```

Try to open this serial port with the assumption that the data logger has been connected to the computer via USB:

```python
try:
│   ser = Serial(port)
```

If `Serial` cannot open the specified port (i.e., if the above assumption was incorrect), it raises a `SerialException` error, which is caught (handled) by the following to-be-completed block of code.

```python
except:
```

Now, we assume the general case that a system notification may already be present.  
As such, keep trying to...

-   show the user a prompt to connect to the microcontroller-based data logger, *or*
-   open the serial port assuming that the device has since been connected,

whichever happens first (that is, whichever the program encounters first):

```python
│   while True:
│   │
│   │   if toaster.show_toast('Connect to the microcontroller via USB', ' ', 
│   │   │                     threaded = True):
│   │   │   break
│   │
│   │   try:
│   │   │   ser = Serial(port)
│   │   │   break¹
│   │   except:
│   │   │   pass
```

¹ This `break` will not be reached unless the previous line, `ser = Serial(port)`, succeeds.  
At least in this context, `break` and `pass` specifically mean 'stop trying' and 'skip error handling', respectively.

 

$\uparrow$ The first possible notification.

The device may have been connected by this point, in which case the connection prompt would be withheld.  
Now, check if the `ser` object is defined (i.e., if the serial port was opened):

```python
│   try:
│   │   ser
```

If not, keep trying to open the port assuming that the device will be connected:

```python
│   except:
│   │
│   │   while True:
│   │   │
│   │   │   try:
│   │   │   │   ser = Serial(port)
│   │   │   │   break
│   │   │   except:
│   │   │   │   pass
```

The data logger has been connected by this point, with or without a prompt to the user.

A notification that the device was connected is to be sent. We assume that an arbitrary notification may already be present, including but by no means limited to the connection prompt from before. If this is the case, it would delay the notification that the device was connected until 'timing out' (for lack of a better term). With this kind of notification, the user should know the time since its corresponding event actually occurred.

As such, start a 'timer' (i.e., log the current time `connected_tick`):

```python
connected_tick = time()
```

Subsequently,

-   keep updating the suspected end time `connected_tock` and the elapsed time calculated from it,
-   keep trying to show a notification that the microcontroller-based data logger was connected and of how long ago this event actually occurred,  
    *and*
-   keep checking if the serial port can be read from (i.e., if the device was not since disconnected),

all until the notification is sent:

```python
while True:
│
│   connected_tock = time()
│   connected_time = connected_tock - connected_tick
│
│   if toaster.show_toast('Microcontroller connected %.1f seconds ago'
│   │                     % connected_time,
│   │                     'Starting now, you may disconnect',
│   │                     threaded = True):
│   │   break
│
│   try:
│   │   ser.readline()
│   except:
│   │   try:
│   │       disconnected_tick
│   │   except:
│   │       disconnected_tick = time()
```

 

$\uparrow$ The second possible notification.

The user would be 'permitted' to disconnect the device as soon as it is connected if the previous [busy waiting](https://en.wikipedia.org/wiki/Busy_waiting) `while` loop is manually (albeit awkwardly) threaded with the upcoming data logging one, or if done using the `threading` standard Python module ([documentation](https://docs.python.org/3/library/threading.html)) instead. However, the user should know not when the device is simply plugged in (as they do and need not be notified), but when the serial communication link is established soon thereafter.

Now, initialize an empty list of `lines` to be read from the serial port, assuming that it is still open:

```python
lines = []
```

Keep trying to read [ASCII](https://en.wikipedia.org/wiki/ASCII) characters from the serial port, and add them to the list of `lines` thereof, until the port is no longer open (i.e., until the device is disconnected):

```python
while True:
│
│   try:
│   │   lines.append(ser.readline())
│   except:
│   │   break
```

Now, check if a variable `disconnected_tick` is already defined (i.e., if the device was disconnected while waiting to send the previous notification):

```python
try:
│   disconnected_tick
```

If not, start another 'timer' (i.e., log the current time `disconnected_tick`):

```python
except:
│   disconnected_tick = time()
```

Keep trying to show a notification that the microcontroller-based data logger was disconnected, and of how long ago this event actually occurred:

```python
while True:
│
│   disconnected_tock = time()
│   disconnected_time = disconnected_tock - disconnected_tick
│
│   if toaster.show_toast('Microcontroller disconnected %.1f seconds ago' % disconnected_time, ' ', threaded = True):
│   │   break
```

 

$\uparrow$ The third possible notification.

## 3. Preparing the Collected Analog Data

*See the following numbered, broken-down block of code.*

Now,

1.   Trim the last two line-ending ASCII characters: line feed \<LF\> `b'\n'` and carriage return \<CR\> `b'\r'`.
2.   Typecast (convert) the remaining ASCII characters from a *byte literal* to a float.
3.   Do the above for all lines but the first one, which may have been cut off.  
     This is a [list comprehension](https://docs.python.org/3/tutorial/datastructures.html#list-comprehensions).
4.   From the list, construct a NumPy `ndarray`, $y$, which is a [time series](https://en.wikipedia.org/wiki/Time_series) of logged data.

     *   Reference: [numpy.ndarray](https://numpy.org/doc/stable/reference/generated/numpy.ndarray.html).
     *   Reference: [The N-dimensional array (ndarray)](https://numpy.org/doc/stable/reference/arrays.ndarray.html).

```python
1.  #                   line[:-2]
2.  #             float(│       │)
3.  #            [│              │ for line in lines[1:-1]]
4.  y = np.array([float(line[:-2]) for line in lines[1:-1]])
```

Specify the scalar time interval between data points and generate a time array, $t$, corresponding to them:

```python
Dt = 10e-3

t = np.arange(len(y)) * Dt
```

Specify a moving average window and use it to smooth the data:

```python
window = 5

y_smooth = pd.Series(y).rolling(window, center = True).mean().to_numpy()
```

## 4. Making the Results Accessible

Firstly, export the prepared data to a CSV file for reference:

```python
np.savetxt('data.csv', y, fmt = '%.2f')
```

Secondly, plot the data points using the Plotly graphing library:

```python
data = go.Scatter(x = t, y = y_smooth)

fig = go.Figure(data)

fig.update_layout(xaxis_title = 'Time in Seconds', yaxis_title = 'Logged Data')
fig.update_layout(title = 'Logged Data')

fig.show()
```



This marks the end of the program.

## Appendix

**Optional refactor 0:**

*   Use `try`-`except`-*`else`* and/or `try`-`except`-*`finally`* blocks.

**Optional refactor 1:**

```python
1  try:
2  │   ser = Serial(port)
3  except:
4  │   ...
```

to

```python
1  from serial.tools.list_ports import comports
2  
3  if port in [comport.device for comport in comports()]:
4  │   ser = Serial(port)
5  elif:
6  │   ...
```

However, between lines 3 and 4 above, the serial port might become unavailable, in which case `Serial` would throw an uncaught `SerialException` error.

**Optional refactor 2:**

```python
1  try:
2  │   ser.readline()
3  except:
4  │   ...
```

to

```python
1  from serial.tools.list_ports import comports
2  
3  if port not in [comport.device for comport in comports()]:
4  │   ...
```

----

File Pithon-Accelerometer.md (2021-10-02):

# Pithon Accelerometer

The uniaxial Pithon accelerometer operates on a piezoresistive sensing mechanism. The device comes in multiple combinations of design features. As printed, one such configuration for standalone testing and evaluation purposes is illustrated below, where numbering corresponds to the design features detailed thereafter.



 1. A relatively large cantilever base, which may be easily clamped in a vice for calibration.
 2. Cantilever beam.
 3. Notches in the base of the cantilever beam.
 4. A hole in the free end of the cantilever beam from which to suspend known weights for the purpose of calibration.
 5. A mount in a cutaway view to show the proof mass it holds.
 6. The proof mass -- a steel ball -- half embedded in its mount.
 7. Primary set of thin, contiguous conductive traces (black) embedded in the surface of the cantile-ver beam surfaces.
 8. Secondary/reference set of conductive traces (black).
 9. The sensing element (black) for the force sensor / accelerometer -- a strain gauge.
10.	The current-forcing and voltage-sensing terminals for four-terminal sensing, either type of which may also be used for ordinary two-terminal sensing. They have large electrical contact pads (black) for probe tips or crocodile clips.
11.	Slots for crocodile clips.

**Download this model:**

 -  [SolidWorks part (SLDPRT) file](https://raw.githubusercontent.com/keeganmjgreen/3D-Printed-Sensors-Development-Platform/main/Development-Kit/Pithon%20Force%20Sensor,%20Accelerometer/mid_str_4T_sensing_and_elem.SLDPRT)
 -  [Stereolithography (STL) file -- accelerometer body](https://raw.githubusercontent.com/keeganmjgreen/3D-Printed-Sensors-Development-Platform/main/Development-Kit/Pithon%20Force%20Sensor,%20Accelerometer/mid_str_4T_sensing.SLDPRT) \
    [Stereolithography (STL) file -- conductive traces](https://raw.githubusercontent.com/keeganmjgreen/3D-Printed-Sensors-Development-Platform/main/Development-Kit/Pithon%20Force%20Sensor,%20Accelerometer/mid_str_4T_sensing_elem.SLDPRT)
 -  [Cura project file / 3D Manufacturing Format (3MF)](https://raw.githubusercontent.com/keeganmjgreen/3D-Printed-Sensors-Development-Platform/main/Development-Kit/Pithon%20Force%20Sensor,%20Accelerometer/mid_str_4T_sensing_and_elem.3mf)

A Pithon accelerometer configuration for calibrated use is illustrated below, where continued numbering corresponds to the design features thereafter that stand out from above.



12.	A more compact cantilever base for a shorter print time, reduced material consumption, and more convenient implementation within designs.
13.	Voltage-sensing terminals for four-terminal sensing, which may also be used for two-terminal sensing. They have compact contact pads (black) made for probe tips.
14.	Terminals for two-terminal sensing, which may also be used as current-forcing terminals for four-terminal sensing. They have large contact pads (black) for probe tips or applied conductive paint/epoxy (silver).
15.	A shared terminal for two-terminal sensing, which may also be used as a shared current-forcing terminal for four-terminal sensing. It has a large contact pad (black) for probe tips or applied conductive paint/epoxy (silver).
16.	Wire leads embedded in conductive paint/epoxy.

**Download this model:**

 -  [SolidWorks part (SLDPRT) file](https://raw.githubusercontent.com/keeganmjgreen/3D-Printed-Sensors-Development-Platform/main/Development-Kit/Pithon%20Force%20Sensor,%20Accelerometer/mid_str_4T_sensing_1_and_elem.SLDPRT)
 -  [Stereolithography (STL) file -- accelerometer body](https://raw.githubusercontent.com/keeganmjgreen/3D-Printed-Sensors-Development-Platform/main/Development-Kit/Pithon%20Force%20Sensor,%20Accelerometer/mid_str_4T_sensing_1.SLDPRT) \
    [Stereolithography (STL) file -- conductive traces](https://raw.githubusercontent.com/keeganmjgreen/3D-Printed-Sensors-Development-Platform/main/Development-Kit/Pithon%20Force%20Sensor,%20Accelerometer/mid_str_4T_sensing_1_elem.SLDPRT)
 -  [Cura project file / 3D Manufacturing Format (3MF)](https://raw.githubusercontent.com/keeganmjgreen/3D-Printed-Sensors-Development-Platform/main/Development-Kit/Pithon%20Force%20Sensor,%20Accelerometer/mid_str_4T_sensing_1_and_elem.3mf)

The accelerometer may also be calibrated as a force sensor without its proof mass or when stationary along its vertical axis (and not in the presence of a magnetic field on the metallic mass), or as a single-axis magnetic field sensor when moving freely and stationary along its vertical axis.

----

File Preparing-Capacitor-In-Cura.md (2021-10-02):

# How To Prepare and Print a Capacitor with Cura
With Pithon's customizability, there are two options on how to print:
1. Print original Monti provided capacitor
2. Customize the original capacitor to your liking before printing

These options will be outlined below.
## Print original Monti provided capacitor
**Step 1**
Since the parallel plate capacitor requires high resolution and precision, it is recommended to freshly reload filaments before printing. This can be done by:
1. Navigate to *SYSTEM* on the Ultimaker 3, then to the extruder of your choice, and *Unload*
2. Once the unload process is finished, lift the material clasp to release the filament. There may be a part of the filament which is tapered and not uniform as the rest. Use common scissors to remove this part before reloading.
3. Reload the filament by going to *SYSTEM* on the Ultimaker 3, then to the extruder of your choice, and *Load*.
4. When prompted to select filament, choose the filament which best describes the material used. In Monti's designs, both materials are PLA based.
5. Allow for the filament to be loaded and wait for a constistent strand of filament to be extruded. Do not stop the process until the filament has reached at least 15 cm below the print head.

> Perform these steps on both materials

**Step 2**
Navigate to files to find `UM3E_Parallel Plate Cap C3-2 (1cmx1cm).gcode` and `UM3E_Parallel Plate Cap C3-2 (1cmx1cm).mf`.
**Step 3**
Communicate files to the printer. Ultimaker allows for communication over LAN or USB.
*For LAN communication*
1. Connect Ultimaker 3 to your network via WiFi or ethernet connection.
- For WiFi, navigate to *SYSTEM* menu and select. Then choose *NETWORK*, followed by *Run WiFi* and follow on-screen instructions.
- For Ethernet, connect an ethernet cable into the LAN port located on the rear of the printer.
2. Select the method of the above chosen methods in *NEWORK* on the printer.
3. On Ultimaker Cura, in the menu bar along the top, select *Settings*, *Printers*, then *Manage Printers*.
4. Select *Connect via network* in Cura.
5. Select the printer you hope to use and select *Connect*.
6. Load `UM3E_Parallel Plate Cap C3-2 (1cmx1cm).mf` as an Ultimaker project.
7. Slice print by selecting *Slice* in a blue bar in the bottom right of the screen. \


8. Select *Print over network* to print.

*For USB communication*
1. Find USB intended for use and insert into USB port on the user's computer
2. Copy `UM3E_Parallel Plate Cap C3-2 (1cmx1cm).gcode` to the USB
3. Navigate to USB, right-click on its name, and select eject. 

NOTICE: Do not remove USB before selecting eject as this may cause corruption of files.
4. Once it is indicated that the USB is safe to remove, remove it from the computer.
5. Insert USB into USB port on the front of the Ultimaker 3. Turn on the printer of you haven't done so already.
6. Navigate to *PRINT* using the dial located on the right hand side of the printer. Press the dial in until it clicks to select the option.
7. Natigate to `UM3E_Parallel Plate Cap C3-2 (1cmx1cm).gcode` on the Ultimaker screen and select.

**Step 4**
Remove print from print bed. Your sensing element has now been printed and is ready to be prepared for calibration.
## Customize the original capacitor
**Step 1**
Navigate files to find `UM3E_Parallel Plate Cap C3-2 (1cmx1cm).mf`.

**Step 2**
Open Ultimaker Cura and open the file from Step 1. This can be accomplished by going to *File* in the top menu, then *Open File(s)* and find the file. \


**Step 3**
Now that the file is open, there should be three components. These components are the bottom plate, dielectric, and top plate from top to bottom. Select one of these three components to customize by choosing it from the *Object list* tab in the bottom left of the screen, or by clicking on the component shape in Cura.

**Step 4**
Change the size of the plate. This can be done by going to the *Scale (S)* option on the left hand menu. Deselect *Uniform Scale* to change plate surface area and plate thickness individually. \


**Step 5**
Change the positioning of the plate. This can be done by going to the *Move (T)* option on the left hand menu. Center all plates at x = 0mm and y = 0mm. For z, keep the bottom plate slightly above the build plate (z = 0.1mm or so). For every plate above the bottom plate, add the thicknesses of plates below it and the 0.1mm gap initially defined. \


>Repeat steps 4 and 5 until the desired structure is acheived.

**Step 6**
Slice the design and save under a name of your choice as a `.gcode` file.

**Step 7**
Follow steps 1 through 4 from the previous section (Print original Monti provided sensor) to complete the print, changing the file names there for the ones chosen by you. 

----

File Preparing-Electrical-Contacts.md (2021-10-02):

# Preparing Electrical Contacts #

## Materials ##

- A Printed sensor
- A spatula or other similar dull and flat blade
- Electrical wire (Recommended: AWG 30 wire)
- Conductive adhesive (Conductive tape, conductive paint or epoxy. conductive paint recommended for price to performance ratio)
- Painter's tape

## Procedure ##

1. Using a spatula or other dull blade, pry the sensor of the print bed at the corners of the sensor base (highlighted in the image below).
   
    \

2. Place the sensor on a flat table with an easily cleanable surface. Tape the sensor to the table using standard painter's tape, as shown in the image below.  
   
    \

3. Using a flat blade, gently scratch the surface of the electrical contacts. The roughened surface will allow for better adhesion to conductive paint or other adhesive.
   
    \

4. Cut four approximately equal lengths of solid core electrical wire. Strip an equal length off each side of every wire. Curl one end of each wire into a U or loop shape. Place the curled end of each wire on the middle of each contact pad. Tape the wire to to the table, as shown in the image below, to secure the wire position.
   
   Notice
   
   *Note:* ensure that each wire is in direct contact with the electrical contacts, as failure to do so could result in poor electrical contact or open circuits. \

    \

5. Apply a small amount of conductive paint to each wire as per section **Using Conductive Paint**.
   
   Notice
   
   *Note:* Ensure that you are familiar and comfortable with the use of conductive paints. Applying too much can cause the paint to spread out and connect to another another electrical contact. This will short circuit the sensor, causing it to become non-functional. \

    \

6. Let the conductive paint dry at room temperature for 12 hours or as per instructions provided by the conductive paint manufacturer.

----

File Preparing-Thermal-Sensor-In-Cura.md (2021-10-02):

# How To Prepare and Print a Thermal Sensor with Cura
With Pithon's customizability, there are two options on how to print:
1. Print original Monti provided thermal sensor
2. Customize the original thermal sensor to your liking before printing

These options will be outlined below.
## Print original Monti provided thermal sensor
**Step 1**
Since the thermal sensor requires high resolution and precision, it is recommended to freshly reload filaments before printing. This can be done by:
1. Navigate to *SYSTEM* on the Ultimaker 3, then to the extruder of your choice, and *Unload*
2. Once the unload process is finished, lift the material clasp to release the filament. There may be a part of the filament which is tapered and not uniform as the rest. Use common scissors to remove this part before reloading.
3. Reload the filament by going to *SYSTEM* on the Ultimaker 3, then to the extruder of your choice, and *Load*.
4. When prompted to select filament, choose the filament which best describes the material used. In Monti's designs, both materials are PLA based.
5. Allow for the filament to be loaded and wait for a constistent strand of filament to be extruded. Do not stop the process until the filament has reached at least 15 cm below the print head.

> Perform these steps on both materials

**Step 2**
Navigate to files to find `temp_4T_sensing_and_elem.gcode` and `temp_4T_sensing_and_elem.3mf`.
**Step 3**
Communicate files to the printer. Ultimaker allows for communication over LAN or USB.
*For LAN communication*
1. Connect Ultimaker 3 to your network via WiFi or ethernet connection.
- For WiFi, navigate to *SYSTEM* menu and select. Then choose *NETWORK*, followed by *Run WiFi* and follow on-screen instructions.
- For Ethernet, connect an ethernet cable into the LAN port located on the rear of the printer.
2. Select the method of the above chosen methods in *NEWORK* on the printer.
3. On Ultimaker Cura, in the menu bar along the top, select *Settings*, *Printers*, then *Manage Printers*.
4. Select *Connect via network* in Cura.
5. Select the printer you hope to use and select *Connect*.
6. Load `temp_4T_sensing_and_elem.3mf` as an Ultimaker project.
7. Slice print by selecting *Slice* in a blue bar in the bottom right of the screen. \


8. Select *Print over network* to print.

*For USB communication*
1. Find USB intended for use and insert into USB port on the user's computer
2. Copy `temp_4T_sensing_and_elem.gcode` to the USB
3. Navigate to USB, right-click on its name, and select eject. 

NOTICE: Do not remove USB before selecting eject as this may cause corruption of files.
4. Once it is indicated that the USB is safe to remove, remove it from the computer.
5. Insert USB into USB port on the front of the Ultimaker 3. Turn on the printer of you haven't done so already.
6. Navigate to *PRINT* using the dial located on the right hand side of the printer. Press the dial in until it clicks to select the option.
7. Natigate to `temp_4T_sensing_and_elem.gcode` on the Ultimaker screen and select.

**Step 4**
Remove print from print bed. Your sensing element has now been printed and is ready to be prepared for calibration.
## Customize the original thermal sensor
Users are free to create their own thermal sensor design, which is recommended to be created through Solidworks. This process is outlined in the manual at [Tips for Optionally Using SolidWorks to Build Upon Sensor Designs](https://github.com/keeganmjgreen/3D-Printed-Sensors-Development-Platform/blob/main/Tips-for-Optionally-Using-SolidWorks-to-Build-Upon-Sensor-Designs.md). For changing the size of the Monti provided sensor, the following steps will outline this.

**Step 1**
Navigate files to find `temp_4T_sensing_and_elem.3mf`.

**Step 2**
Open Ultimaker Cura and open the file from Step 1. This can be accomplished by going to *File* in the top menu, then *Open File(s)* and find the file. \


**Step 3**
Now that the file is open, there should be two components. These components are the conductive sensing element and the non-conductive base. Select both components by holding *Ctrl* and selecting the components either from the *Object list* in the bottom left or by clicking on their models in the software.

**Step 4**
In order to increase the size of the thermal sensor as a whole in one step, these objects must be grouped. To group, once they're selected right click. Navigate to *Group Models* and select to create a group. \


**Step 5**
Change the size of the thermal sensor. This can be done by going to the *Scale (S)* option on the left hand menu. Deselect *Uniform Scale* if you want to change the height, width, or thickness seperately. \


**Step 6**
Slice the design and save under a name of your choice as a `.gcode` file.

**Step 7**
Follow steps 1 through 4 from the previous section (Print original Monti provided thermal sensor) to complete the print, changing the file names there for the ones chosen by you.

----

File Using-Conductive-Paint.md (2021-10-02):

[Download as PDF](https://raw.githubusercontent.com/keeganmjgreen/3D-Printed-Sensors-Development-Platform/main/pdf/Using-Conductive-Paint.pdf)

----

# Using Conductive Paint

[Conductive paint](https://www.digikey.com/en/products/filter/coating-grease-repair/642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) comes in 5--10-gram syringes.

You might also want to look into [conductive epoxy](https://www.digikey.com/en/products/filter/glue-adhesives-applicators/909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) (preferably single-syringe one-part epoxy) and/or [conductive tape](https://www.digikey.com/en/products/filter/tape/908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).

## Additional Supplies

 -  Safety glasses
 -  Gloves
 -  Lab sink
 -  Paper towels
 -  Cotton swabs
 -  Surface cleaner

## Preparation and Cleanup

Potentially toxic material
Wear eye protection
Wear protective gloves
Wash your hands

 \
Caution

**Caution:** Wear safety glasses and gloves whenever working with wet conductive paint and wash your hands throughroughly afterward. Failure to do so may result in conductive paint or water contaminated with it in your eyes or on your skin.

Do all of the following over a lab sink. Do not wait long between steps to prevent the conductive paint from drying/hardening in the nozzle tip of the syringe.

### Preparation

 1. Unscrew the cap from the nozzle of the syringe while holding it upside-down, without putting pressure on its plunger.
 2. Screw the widest possible nozzle tip into the nozzle. Its greater contents take longer to dry/harden and it may be cleaned out using a cotton swab.
 3. As slowly and steadily as possible, press the plunger until conductive paint fills toward the end of the translucent tip.
 4. Clean excess conductive paint from the tip using a paper towel.

### Cleanup

 1. Unscrew the nozzle tip while holding the syringe upside-down, without putting pressure on its plunger.
 2. Screw the cap back onto the nozzle of the syringe.
 3. Rinse the tip, clean it out using a cotton swab, and dry it using a paper towel.
    
    Caution
    
    **Caution:** Be extremely careful not to spray up water contaminated with conductive paint, especially toward yourself. Failure to do so may result in conductive paint in your eyes or on your skin.

----

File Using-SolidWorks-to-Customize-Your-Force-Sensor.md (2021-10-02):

[Download as PDF](https://raw.githubusercontent.com/keeganmjgreen/3D-Printed-Sensors-Development-Platform/main/pdf/Using-SolidWorks-to-Customize-Your-Force-Sensor.pdf)

----

# Using SolidWorks to Customize Your Force Sensor

SolidWorks is a common CAD (computer-aided design) program with which Pithon sensors were developed. If you have SolidWorks 2019 or later, you can use it to customize them if necessary to meet the needs of your precise application.

Open [`mid_str_4T_sensing_and_elem.SLDPRT`](https://raw.githubusercontent.com/keeganmjgreen/3D-Printed-Sensors-Development-Platform/main/Development-Kit/Pithon%20Force%20Sensor,%20Accelerometer/mid_str_4T_sensing_and_elem.SLDPRT). This SolidWorks part file contains the base and cantilever beam of the force sensor as one component, and the conductive traces of the force sensor (including its sensing element and electrical terminals / contact pads) as another.

## Customize

**01. To adjust the distance from the back of the cantilever base to the start of the cantilever beam...**

 1. [In the left pane (the *FeatureManager Design Tree*), open the context menu for the Beam Surfaces *Extruded Boss/Base* feature.](https://raw.githubusercontent.com/keeganmjgreen/3D-Printed-Sensors-Development-Platform/main/img/Using-SolidWorks-to-Customize-Your-Force-Sensor/01/1.png)
    
     \

 2. [Select *Edit Sketch*.](https://raw.githubusercontent.com/keeganmjgreen/3D-Printed-Sensors-Development-Platform/main/img/Using-SolidWorks-to-Customize-Your-Force-Sensor/01/2.png)
    
     \

 3. [Drag the leftmost line representing the back of the cantilever base, which will snap to the nearest half millimeter, or directly adjust its *X* position under *Additional Parameters* in the left pane to achieve finer resolution.](https://raw.githubusercontent.com/keeganmjgreen/3D-Printed-Sensors-Development-Platform/main/img/Using-SolidWorks-to-Customize-Your-Force-Sensor/01/3.png) We recommend *X* = 0 mm (lining it up with the origin of the coordinate system / $y$$z$-plane) for the sake of covering the primary set of conductive traces forming 4 terminals and one *sensing element*. Our default is *X* = --33 to also cover the secondary set. \

 4. Select *Exit Sketch*.
    
     \

Do this to vary the space for conductive traces or the mounting area. Do not design the exposed space for conductive traces to be a mounting area. The conductive traces are sensitive to material expansion/compression (as designed), including that applied by a mount.

Remember that this modification will change the bounding volume of the sensor.

**02. To adjust the length of the cantilever beam...**

 1. [In the left pane (the *FeatureManager Design Tree*), open the context menu for the Beam Surfaces *Extruded Boss/Base* feature.](https://raw.githubusercontent.com/keeganmjgreen/3D-Printed-Sensors-Development-Platform/main/img/Using-SolidWorks-to-Customize-Your-Force-Sensor/02/1.png)
    
     \

 2. [Select *Edit Sketch*.](https://raw.githubusercontent.com/keeganmjgreen/3D-Printed-Sensors-Development-Platform/main/img/Using-SolidWorks-to-Customize-Your-Force-Sensor/02/2.png)
    
     \

 3. [Drag the rightmost line representing the free edge of the cantilever beam, which will snap to the nearest half millimeter, or directly adjust its *X* position under *Additional Parameters* in the left pane to achieve finer resolution.](https://raw.githubusercontent.com/keeganmjgreen/3D-Printed-Sensors-Development-Platform/main/img/Using-SolidWorks-to-Customize-Your-Force-Sensor/02/3.png) Our default is *X* = 45 mm. Alternately, adjust the *Length* parameter of either side edge of the cantilever beam. \

 4. Select *Exit Sketch*.
    
     \

Do this do vary the maximum deflection of the cantilever beam under a given load/force, particularly being applied to its free end, where the maximum deflection happens. Approximate the deflection of a beam without a notch using this formula:

$$ \small \sf \textsf{maximum deflection} = \dfrac{4 \left( \textsf{approximately vertical force} \right) \left( \textsf{beam length} \right)^3}{\left( \textsf{Young's modulus of the material} \right) \left( \textsf{beam width} \right) \left( \textsf{beam thickness} \right)^3} $$

Here, the *beam length* is really the distance from the start of the cantilever beam to wherever the force is applied along its length. The *Young’s modulus* is a mechanical property that is representative of elasticity and unique to the 3D printed material and its print settings. It has units of Newtons per square meter (N/m²) . Measure the maximum deflection and use the formula in reverse to approximate it. Only use the formula for small values of maximum deflection relative to the length of the cantilever beam.

The length *and* thickness of the cantilever beam greatly affect its maximum deflection. Making it twice as thick, for example, will have it deflect one eighth as much for the same force.

Remember that this modification will change the bounding volume of the sensor.

**03. To adjust the width of the cantilever beam...**

 1. [In the left pane (the *FeatureManager Design Tree*), open the context menu for the Beam Surfaces *Extruded Boss/Base* feature.](https://raw.githubusercontent.com/keeganmjgreen/3D-Printed-Sensors-Development-Platform/main/img/Using-SolidWorks-to-Customize-Your-Force-Sensor/03/1.png)
    
     \

 2. [Select *Edit Sketch*.](https://raw.githubusercontent.com/keeganmjgreen/3D-Printed-Sensors-Development-Platform/main/img/Using-SolidWorks-to-Customize-Your-Force-Sensor/03/2.png)
    
     \

 3. [Drag the lines representing the sides of the cantilever beam, which will snap to the nearest half millimeter, or directly adjust their *Y* positions to ±(width)/2 under *Additional Parameters* in the left pane to achieve finer resolution.](https://raw.githubusercontent.com/keeganmjgreen/3D-Printed-Sensors-Development-Platform/main/img/Using-SolidWorks-to-Customize-Your-Force-Sensor/02/3.png) \

 4. Select *Exit Sketch*.
    
     \

Do this to vary the width of the force-sensitive area toward the free end.

**04. To adjust the thickness of the cantilever beam (and consequently shift the cantilever base by the same amount)...**

 1. [In the left pane, open the context menu for the Beam Surfaces *Extruded Boss/Base* feature.](https://raw.githubusercontent.com/keeganmjgreen/3D-Printed-Sensors-Development-Platform/main/img/Using-SolidWorks-to-Customize-Your-Force-Sensor/04/1.png)
    
     \

 2. [Select *Edit Feature*.](https://raw.githubusercontent.com/keeganmjgreen/3D-Printed-Sensors-Development-Platform/main/img/Using-SolidWorks-to-Customize-Your-Force-Sensor/04/2.png)
    
     \

 3. Drag the arrow showing the extrusion depth from the beam surfaces, which will snap to the nearest millimeter, or [directly adjust the *Depth* parameter in the left pane to achieve finer resolution](https://raw.githubusercontent.com/keeganmjgreen/3D-Printed-Sensors-Development-Platform/main/img/Using-SolidWorks-to-Customize-Your-Force-Sensor/04/3.png). Our default is 2 mm. We often use 1 mm. \

 4. Select *OK*.

Do this to vary the maximum deflection of the cantilever beam under a given load/force, as in **02** above.

Remember that this modification will change the bounding volume of the sensor. Making the cantilever beam thicker, for example, will not take space from the cantilever base as you may expect.

**05. To change whether or not there is a hole at the free end of the cantilever beam...**

 1. [In the left pane, open the context menu for the Free End Hole *Extruded Cut* feature.](https://raw.githubusercontent.com/keeganmjgreen/3D-Printed-Sensors-Development-Platform/main/img/Using-SolidWorks-to-Customize-Your-Force-Sensor/05/1.png)
    
     \

 2. Select *Suppress* or *Unsuppress*. The Free End Hole Fillets, as a derived feature, will be automatically suppressed too, but should be manually unsuppressed along with the Free End Hole.
    
     or  \

Keep the free end hole if you are going to calibrate the force sensor by, for example, hanging known weights off the end of its cantilever beam, or if you are going to, say, tap a screw through it.

You likely do not need to change the position or diameter of the hole. If you do, you can follow similar instructions found in this section.

**06. To adjust the thickness of the cantilever base...**

 1. [In the left pane, open the context menu for the Cantilever Base *Extruded Boss/Base* feature.](https://raw.githubusercontent.com/keeganmjgreen/3D-Printed-Sensors-Development-Platform/main/img/Using-SolidWorks-to-Customize-Your-Force-Sensor/06/1.png)
    
     \

 2. [Select *Edit Feature*.](https://raw.githubusercontent.com/keeganmjgreen/3D-Printed-Sensors-Development-Platform/main/img/Using-SolidWorks-to-Customize-Your-Force-Sensor/06/2.png)
    
     \

 3. Drag the arrow showing the extrusion depth from the bottom of the Beam Surfaces *Extruded Boss/Base* feature, which will snap to the nearest millimeter, or [directly adjust the *Depth* parameter in the left pane to achieve finer resolution](https://raw.githubusercontent.com/keeganmjgreen/3D-Printed-Sensors-Development-Platform/main/img/Using-SolidWorks-to-Customize-Your-Force-Sensor/06/3.png). Our default is 4 mm beneath the cantilever beam, simply for a total thickness of 5 mm with the default 1-mm beam surfaces. \

 4. Select *OK*.

Remember that this modification will change the bounding volume of the sensor.

**07. To adjust the depth of the conductive traces...**

 1. [In the left pane, open the context menu for the Space for Conductive Traces *Extruded Cut* feature.](https://raw.githubusercontent.com/keeganmjgreen/3D-Printed-Sensors-Development-Platform/main/img/Using-SolidWorks-to-Customize-Your-Force-Sensor/07/1.png)
    
     \

 2. [Select *Edit Feature*.](https://raw.githubusercontent.com/keeganmjgreen/3D-Printed-Sensors-Development-Platform/main/img/Using-SolidWorks-to-Customize-Your-Force-Sensor/06/2.png)
    
     \

 3. [Adjust the *Depth* parameter in the left pane.](https://raw.githubusercontent.com/keeganmjgreen/3D-Printed-Sensors-Development-Platform/main/img/Using-SolidWorks-to-Customize-Your-Force-Sensor/07/3.png) Our default is 0.5 mm. \

 4. Select *OK*. \

 5. [In the left pane, open the context menu for the Conductive Traces *Extruded Boss/Base* feature](https://raw.githubusercontent.com/keeganmjgreen/3D-Printed-Sensors-Development-Platform/main/img/Using-SolidWorks-to-Customize-Your-Force-Sensor/07/5.png), which uses the space made available by its matching *Extruded Cut* feature above.
    
     \

 6. Select *Edit Feature*.
    
     \

 7. [Set the *Depth* parameter to be the same as in Step 3.](https://raw.githubusercontent.com/keeganmjgreen/3D-Printed-Sensors-Development-Platform/main/img/Using-SolidWorks-to-Customize-Your-Force-Sensor/07/7.png) \

 8. Select *OK*.

Do this to vary the resistance of the conductive traces, including the *sensing element*. Measure what will be the old resistance and approximate a new resistance using this formula:

$$ \small \sf \textsf{new resistance} = \textsf{old resistance} \ \! \cdot \dfrac{\: \, \textsf{old depth}}{\textsf{new depth}} $$

Only use the formula for wire-like conductive traces. Do not use It for electrical terminals / contact pads.

**08. To change whether or not there is a reference set of conductive traces...**

 1. [In the left pane, open the context menu for the mid_str_4T_Sensing_Elem Reference *Mirror* feature.](https://raw.githubusercontent.com/keeganmjgreen/3D-Printed-Sensors-Development-Platform/main/img/Using-SolidWorks-to-Customize-Your-Force-Sensor/08/1.png)
    
     \

 2. Select *Suppress* or *Unsuppress*.
    
     or  \

 3. [Repeat steps 1–2 for the Space for mid_str_4T_Sensing_Elem Reference *Mirror* feature.](https://raw.githubusercontent.com/keeganmjgreen/3D-Printed-Sensors-Development-Platform/main/img/Using-SolidWorks-to-Customize-Your-Force-Sensor/08/3.png)
    
     \

 4. [Repeat steps 1–2 optionally for Mirror0](https://raw.githubusercontent.com/keeganmjgreen/3D-Printed-Sensors-Development-Platform/main/img/Using-SolidWorks-to-Customize-Your-Force-Sensor/08/4.png), noted to be: \
    Space for lower jaws of crocodile clips for Electrical Contacts of mid_str_4T_Sensing_Elem Reference

**09. To change whether or not there are recesses/slots for crocodile clips...**

 1. [In the left pane, open the context menu for Cut-Extrude0](https://raw.githubusercontent.com/keeganmjgreen/3D-Printed-Sensors-Development-Platform/main/img/Using-SolidWorks-to-Customize-Your-Force-Sensor/09/1.png), noted to be:
    Space for lower jaws of crocodile clips for Electrical Contacts of mid_str_4T_Sensing_Elem \

 2. Select *Suppress* or *Unsuppress*. Fillet0 and optionally Mirror0, as derived features, will be automatically suppressed too, but should be manually unsuppressed along with Cut-Extrude0.
    
     or  \

Keep the recesses/slots for crocodile clips if you are not yet going to use a conductive adhesive.

**10. To use your force sensor as an accelerometer...**

 1. [In the left pane, open the context menu for all of the Proof Mass and Mount features.](Using-SolidWorks-to-Customize-Your-Force-Sensor/10/1.png)
    
     \

 2. Select *Unsuppress*.
    
     \

The fillets are to better depict the 3D printing process for rendering purposes. You may opt to remove them entirely.

## Export

Before you can load the components of your 3D model into your 3D printing software, such as Ultimaker Cura, you need to export them from SolidWorks in more universal formats:

 1. To start, [change the left pane to show the *ConfigurationManager* tab.](Using-SolidWorks-to-Customize-Your-Force-Sensor/)
    
 2. Open our Export configuration.
    
     \

 3. Ensure that any and all of the above customizations are carried across.
    
 4. Ensure that all *Fillet* features have been suppressed.

### Export the Cantilever

 1. [Ensure that the Export Cantilever *Display State* is opened.](Using-SolidWorks-to-Customize-Your-Force-Sensor/)
    This hides everything except the light gray mid_str_4T_sensing *Body*, with its base and cantilever beam.
    
     \

 2. Select *File* > *Save **As**…*
    
     -  Name the export file “mid_str_4T_sensing” minus the file extension.
        
     -  Select *STL* (stereolithography mesh) for the file type.
        
        You can use other file types with similar purposes (e.g., STEP/STP) to your liking, given that they can also be imported into your 3D printing software.
    
 3. Confirm the generated triangular stereolithography mesh as previewed to save the export file.

### Export the Conductive Traces

 1. [Ensure that the Export Conductive Traces *Display State* is opened.](Using-SolidWorks-to-Customize-Your-Force-Sensor/)
    This hides everything except the black mid_str_4T_sensing_elem *Body*, with its *sensing element* and electrical terminals / contact pads. You can use this component for the reference set of conductive traces as well.
    
     \

 2. Select *File* > *Save **As***…
    
     -  Name the export file “mid_str_4T_sensing_elem” minus the file extension.
        
     -  Select *STL* (stereolithography mesh) for the file type.
        
        You can use other file types with similar purposes (e.g., STEP/STP) to your liking, given that they can also be imported into your 3D printing software.
    
 3. Confirm the generated triangular stereolithography mesh as previewed to save the export file.

----

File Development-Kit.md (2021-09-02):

# Development Kit

## [Pithon Force Sensor, Accelerometer](https://github.com/keeganmjgreen/3D-Printed-Sensors-Development-Platform/tree/main/Development-Kit/Pithon%20Force%20Sensor%2C%20Accelerometer)

See section [**Pithon Accelerometer**](https://3d-printed-sensors-development-platform.readthedocs.io/en/latest/Pithon-Accelerometer.html).

## [Pithon Temperature Sensor](https://github.com/keeganmjgreen/3D-Printed-Sensors-Development-Platform/tree/main/Development-Kit/Pithon%20Temperature%20Sensor)

## [Pithon Platform Implementation Example](https://github.com/keeganmjgreen/3D-Printed-Sensors-Development-Platform/tree/main/Development-Kit/Pithon%20Platform%20Implementation%20Example)

## [Pithon Protoboard](https://github.com/keeganmjgreen/3D-Printed-Sensors-Development-Platform/tree/main/Development-Kit/Pithon%20Protoboard)

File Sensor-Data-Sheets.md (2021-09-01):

This page is no longer pertinent but remains searchable.

----

# Example Data Sheets #

This document will serve as a compendium of sensor and evaluation boards Data Sheets and User Manuals. 
Documentation will be gathered from multiple vendors, configurations (module or evaluation board) and sensor type (strain, accelerometer or environmental).
The document will conclude with an analysis of common content, structure and conventions between user manuals as well as their core differences.

## Strain Gauges ##

### Evaluation Boards ###

[HX711 Load Cell - Data Sheet](https://cdn.sparkfun.com/assets/b/f/5/a/e/hx711F_EN.pdf)

[LTC2483 Demonstration Boad (Strain & temperature) - User Manual](https://www.analog.com/media/en/technical-documentation/user-guides/dc955af.pdf)

### Sensor Modules ###

[OMEGA Transducer Quality Strain Gauge - Data Sheet](https://assets.omega.com/pdf/test-and-measurement-equipment/strain-gauges/SGT_UNIAXIAL.pdf)

## Accelerometers ##

### Evaluation Boards ###

[ADXL377 Evaluation Board - User Manual](https://cdn-learn.adafruit.com/downloads/pdf/adafruit-analog-accelerometer-breakouts.pdf)

### Sensor Modules ###

[ADXL335 (3-axis) - Data Sheet](https://www.analog.com/media/en/technical-documentation/data-sheets/ADXL335.pdf)

[ADXL312 (3-axis) - Data Sheet](https://www.analog.com/media/en/technical-documentation/data-sheets/ADXL312.pdf)

## Environmental Sensors ###

### Evaluation Boards ###

[DFR0067 - User Manual](https://www.digikey.ca/htmldatasheets/production/2071184/0/0/1/dht11-humidity-temp-sensor.html)

### Sensor Modules ###

[DFR0067 - Data Sheet](http://image.dfrobot.com/image/data/DFR0067/DFR0067_DS_10_en.pdf)

### Data Logging Devices ###
[RHTEMP101A - User Manual](https://www.madgetech.com/wp-content/uploads/2020/05/rhtemp101a-pug.pdf)

## Notes & Conclusions ##

There is a large degree of variation between sensor Data Sheets/User Manuals. Different manufacturers and suppliers have markedly different scope and organization of data included. Evaluation boards tend to have much more information, specifically with regard in how to calibrate and use the sensor compared to individual sensor modules. This difference is even reflected within the document name - Evaluation Boards are more likely to have User Manuals and modules are more likely to have Data Sheets. Pithon is more akin to an evaluation board than a module. 

Common Headings and information contained in sensor User Manuals that are relevant to Pithon are:

- Product Description
  - 1/3 to 1/2 page description of the product
  - Summary of key features/selling points
  - Link to manufacturer's website for additional info and demosntrations
- System Diagram
  - Non-technical (usually) system level diagram, sometimes with a scale reference. Either physical system or computer model.
- Quick Start Guide
  - Essentially just a description on how to use the product as fast as safely possible.
- Installation/Hardware Setup
  - How to properly setup the device into normal operating conditions. Always follows the Quick Start Guide
- Calibration
  - Sometimes called 'Experiments'
  - Detailed description on how to calibrate the device.
  - Seperated into multiple subheadings for testing each individual part of the calibration process 
- Source Code (In some manuals)
  - Snippets of source code that can be used to utilize the sensor to its fullest extent.
- Specifications
  - All the technical information for the sensor such as bandwidth, sensitivity, max input voltage/current, etc. 
- Circuit Diagram (Schematic Diagram)
  - Always only one system level circuit diagram including all wiring.
- Legal Notice
  - All relevant legal information/waivers, essentially to explain to not take a bath with your accelerometer.

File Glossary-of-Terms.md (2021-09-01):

[Download as PDF](https://raw.githubusercontent.com/keeganmjgreen/3D-Printed-Sensors-Development-Platform/main/pdf/Glossary-of-Terms.pdf)

----

# Glossary of Terms #

An **Analog Signal** is a continuously-valued signal. In other words, an analog signal is any signal that can take any value between the signal's minimum and maximum value.

An **Analog-to-Digital Converter (ADC)** converts an analog signal to a digital signal. The output of the sensors described in this manual are analog, and therefore must be converted to a digital signal by an ADC, such as that within many microcontrollers, prior to being used by its onboard software.

**Calibration** includes a set of methods and tools to compare the results of a sensor to a calibration standard of known accuracy. For the purposes of this manual, the term is used to describe the process of converting a change in a measured electrical property (resistance or capacitance) to a mechanical or environmental property (force, acceleration, temperature, etc.) depending on the sensor.

A **Cantilever Beam** is any beam (or rod) that is fixed to a wall or surface on one end and is 'free' (unsupported) at its other end.

The **Conductive Traces** are long continuous lengths of conductive filament which allow current to pass through. They act as *sensing elements* (see below) and to connect electrical contacts to complete an electrical circuit.

A **Digital Signal** is a signal that can only take specific (discrete) values. All computers -- including the microprocessor onboard a microcontroller -- can only read from (or create) a digital signal and not an analog signal.

**Electrical Contacts**, also called contact pads, are large rectangular areas of conductive material allowing easy access for measuring electrical properties.

**Fused Deposition Modelling (FDM)** is a 3D printing process wherein plastic filaments are heated and extruded through a dispensing nozzle. 3D objects are printed onto a *print bed* or *build plate* in a layer-by-layer process. 3D printers using FDM are by far the most common and least expensive.

The **Infill Pattern** defines the shape and structure of the inside of a 3D printed part. Infill pattern affects the amount of material used as well as a printed part's strength and weight.

**Polylactic Acid (PLA)** is a plastic commonly used in 3D printing. PLA-based plastics are used for the structural and conductive components of all sensors described in this manual.

**Polyvinyl Acetate (PVA)** is a water-soluble plastic commonly used in 3D printing to produce temporary support structures. This material is often used to improve the print quality of difficult-to-print objects.

A **Proof Mass** is a weight of known mass used in measurement equipment. Accelerometers typically use a relatively heavy proof mass to obtain a better measurement of applied acceleration.

A **Sensing Element** is any electrically conductive element that can be used to measure a specific mechanical or environmental property, such as force or temperature.

**Sensitivity**, when used to describe a sensor, is the ratio of an output signal of a sensor and the measured property. In other words, a more sensitive force sensor has a larger change in resistance for a given applied force. More sensitive sensors can readily detect smaller changes in the measured property (for example, force) than a less sensitive one. 

----

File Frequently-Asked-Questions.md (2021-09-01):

[Download as PDF](https://raw.githubusercontent.com/keeganmjgreen/3D-Printed-Sensors-Development-Platform/main/pdf/Frequently-Asked-Questions.pdf)

----

# Frequently Asked Questions #

1. **What 3D printer do you recommend using?**

    Monti 3D Printing Solutions has extensively used an [Ultimaker 3](https://www.printyourmind3d.ca/products/ultimaker-s3-studio-3d-printer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) for the development of the Pithon platform. As such, using an Ultimaker is highly recommended because it is inherently compatible with all Pithon products. However, any higher-end consumer grade 3D printer should be capable of producing Pithon sensors. A [Prusa I3](https://shop.prusa3d.com/en/3d-printers/180-original-prusa-i3-mk3s-kit.html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), equivalent, or any higher-end model is recommended also. Furthermore, Monti recommends using a printer with *dual extrusion* capabilities as this will simplify the manufacturing process. The print resolution and consistency of lower-grade printers cannot be guaranteed.

2. **What 3D printing filament do you recommend using?**

    The majority of Monti's development has used [Proto-pasta Electrically Conductive Composite PLA](https://www.proto-pasta.com/products/conductive-pla) for conductive filament and [Ultimaker Silver Metallic PLA](https://www.voxelfactory.com/products/ultimaker-silver-metallic-pla-2-85mm-750g) as structural filament. Despite Monti's best efforts to make our manufacturing processes as cross-compatible as possible, other combinations of structural and conductive filament may not be compatible. Incompatible filaments may not adhere to each other sufficiently and may separate once cooled. It is recommended that you use PLA-based conductive filaments with PLA-based structural filaments. Furthermore, it is recommended that you use filaments from the same manufacturer as this will likely increase the chance that they are compatible with each other. Do not mix a PLA-based filament with an ABS -- or other material-based -- filament as this increases the chance of incompatibility.

3. **Are conductive filaments difficult to print with?**

    Conductive filaments are typically quite brittle and require a higher heat to extrude. Using an Ultimaker 3, we have not experienced difficulties getting consistently high-quality extrusion of conductive filaments. Refer to the manufacturer's specifications for the conductive filaments; some require a minimum 3D printer nozzle diameter. Due to the brittleness of conductive filaments, particular care must be taken to regularly clean your 3D printer's filament-feeding mechanism and nozzle. Debris and conductive dust tend accumulate in the printer's feeder as produced during the printing process. Regularly clean the feeders as per the manufacturer's User Manual to prevent debris building up causing clogs. Additionally, if the 3D printer's feeder tension is too high, breaks or splits may develop in the filament which prevent the printer from feeding the material into the extruder.

4. **How Do I measure capacitance?**

    After printing a capacitor, or capacitive sensor, it is recommended to verify the capacitor using a standard multimeter. Monti recommends using a multimeter accurate to within 0.1 picofarads (pF). Start by measuring the resistance across the capacitor; the returned value should be either 'OL' for overload, or in the megaohm (MΩ) range. If you receive smaller resistance values, the capacitor is likely shorted. In this case, you should attempt to reprint the sensor and/or improve print quality by calibrating the printer, cleaning the print nozzle, cleaning the printer's feeding mechanism, or manually refeeding the conductive filament. Perform all of these operations as per your 3D printer's User Manual.
    
    After confirming that the capacitor is not shorted, measure the capacitance using a multimeter and confirm that the value is close to the expected value as described in section XXX. Note that during sensor operation (while being measured by the microcontroller), the capacitance is never directly measured. <!-- It is indirectly measured using a process known as *AC decoupling* as described in section XXX. --> When performing measurements using the microcontroller as per Monti specification, it will measure capacitance 'properly'.

5. **What are typical resistance values of Pithon sensors?**

    The properties of resistors produced using conductive filament are dependent on the conductive filament used. Using [Proto-pasta Electrically Conductive Composite PLA](https://www.proto-pasta.com/products/conductive-pla), we typically produce resistors (or resistive sensors) with 3- to 15-kΩ resistance depending on the design. Conductive filaments with higher specified *resistivity* will produce resistors with a larger overall resistance.

6. **What are typical capacitance values of Pithon sensors?**
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

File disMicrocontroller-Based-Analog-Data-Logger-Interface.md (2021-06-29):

| Notice |
|:-------|
| Our interface is not real-time (beyond the sense that serial communication is not real-time). The logged data is plotted only after it is collected, not *as* it is collected. We are attempting to add this capability. Alternatively, or as a temporary workaround, we (and possibly our end users) are adapting/using the Arduino IDE serial plotter and others. |

----
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

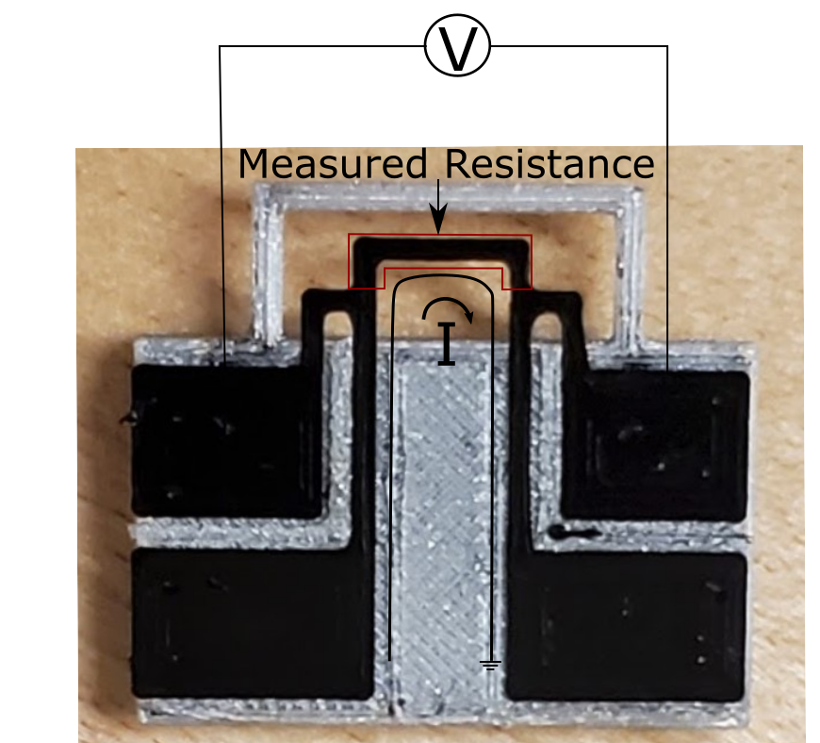
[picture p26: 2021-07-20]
img/4-Terminal-Schematic.png

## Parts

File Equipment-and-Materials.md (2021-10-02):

[Download as PDF](https://raw.githubusercontent.com/keeganmjgreen/3D-Printed-Sensors-Development-Platform/main/pdf/Equipment-and-Materials.pdf)

----

# Equipment and Materials
    
 -  A [3D printer](https://www.digikey.com/en/products/filter/3d-printers/943?s=N4IgTCBcDaIMwBMAEAHATgSwHYBcQF0BfIA).
    
    Minimum requirements:
    
     -  A 3D printer with two extruders ("dual extrusion" capability), to print both regular and conductive material.
    
    Recommended: 
    
     -  A *cartesian* 3D printer (as opposed to a *delta* 3D printer), to make printing more consistent throughout the *print volume* and easier to predict in general.
    
    Nice-to-have's:
    
     -  A 3D printer with even more than two extruders <!--(?)-->, to also print "breakaway" or dissolvable material for 'scaffolding' prints above the *build plate*.
        
     -  An [Ultimaker-brand 3D printer](https://ultimaker.com/3d-printers).* All Ultimaker-brand 3D printers are cartesian 3D printers.
        
         -  An [*Ultimaker 3* (or *Ultimaker 3 Extended*)](https://ultimaker.com/3d-printers/ultimaker-3), as used in our project development.
         -  An [*Ultimaker S3*](https://ultimaker.com/3d-printers/ultimaker-s3), the successor to the *Ultimaker 3*.
        
     -  More than one 3D printer:
        
         -  More than one of the same make & model, to more quickly test print settings, test designs, and create complete devices -- get up and running faster.
         -  More than one of different models, to try them out and similarly get up and running faster at the cost of less consistency and predictability.
    
 -  A spool of regular [3D printing filament](https://www.digikey.com/en/products/filter/3d-printing-filaments/944), preferably just [250 grams](https://www.digikey.com/en/products/filter/3d-printing-filaments/944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) for sensor structures, or to start with for large albeit partially-hollow prints.
    
     -  [Easy-to-Print 3D Printer Filaments ](https://www.mcmaster.com/3d-printer-filaments/easy-to-print-3d-printer-filaments-5/)
     -  [Flexible 3D Printer Filaments ](https://www.mcmaster.com/3d-printer-filaments/flexible-3d-printer-filaments-5/)
    
 -  A spool of conductive 3D printing filament (e.g., [500 grams of *LulzBot*-brand black 2.85-mm PLA](https://www.digikey.com/en/products/detail/lulzbot/RM-PL0100/8605417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)), preferably just 250 grams, which is more than enough.
    
     -  [Conductive Easy-to-Print 3D Printer Filaments ](https://www.mcmaster.com/3d-printer-filaments/conductive-easy-to-print-3d-printer-filaments/)
     -  [Conductive Flexible 3D Printer Filaments](https://www.mcmaster.com/3d-printer-filaments/conductive-flexible-3d-printer-filaments/)
    
 -  Nice-to-have: A spool of "breakaway" or [dissolvable 3D printing filament](https://www.digikey.com/en/products/detail/polymaker/PM70810/13146566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), preferably just 250 grams, which is more than enough.
    
     -  [Structural Support 3D Printer Filaments](https://www.mcmaster.com/3d-printer-filaments/structural-support-3d-printer-filaments/)
     -  [Ultimaker PVA material: Water-soluble support for complex prints](https://ultimaker.com/materials/pva)
     -  [Ultimaker Breakaway material: Easy-to-remove support material for dual extrusion](https://ultimaker.com/materials/breakaway)
    
 -  Recommended: One or more good-quality crafting/hobby knives with a forward-facing cutting edge (e.g., that of an [*X-Acto*](https://www.xacto.com/knives-blades.html) *#18* blade) to help remove prints from the *print bed*.
    
 -  Recommended: One or more good-quality crafting/hobby knives with a slanted cutting edge (e.g., that of an [*X-Acto*](https://www.xacto.com/knives-blades.html) *#2*, *#11*, *#19*, or *#24* blade) to help remove prints from the *print bed*, and help touch them up afterward.
    
 -  Recommended: One or more pairs of tweezers, to help clean the *extruder nozzles* of the 3D printer.
    
 -  Recommended: A set of hex keys, to disassemble and reassemble the filament *feeders* before and after cleaning/clearing them.
    
 -  Optional: One or more compressed air canisters used for dusting, to clean most of the 3D printer (and workspace) of filament dust and stray pieces, during and after printing.
    
 -  Nice-to-have: A shop supply of compressed air, to clean most of the 3D printer (and workspace) of filament dust and stray pieces, during and after printing.
    
    Caution
    
    **Caution:** Compressed air lines are at very high pressures. Always wear safety goggles when working with a compressed air line. Never point its nozzle at yourself or others. Failure to do so may result in bodily harm.
    
    Notice
    
    *Note:* Compressed air lines are at very high pressures, much higher than that of a compressed air canister. Test their force a meter from the 3D printer first. Failure to do so may damage the more delicate parts of the printer.
    
 -  Optional: [*ScotchBlue*](https://www.scotchblue.com/3M/en_US/scotchblue/) or similar tape, to form a layer on the *print bed* for making prints stick to it better during fabrication, while making it easier to remove afterward.

\* We do not endorse or represent Ultimaker or any of the other brands named in this documentation.

----

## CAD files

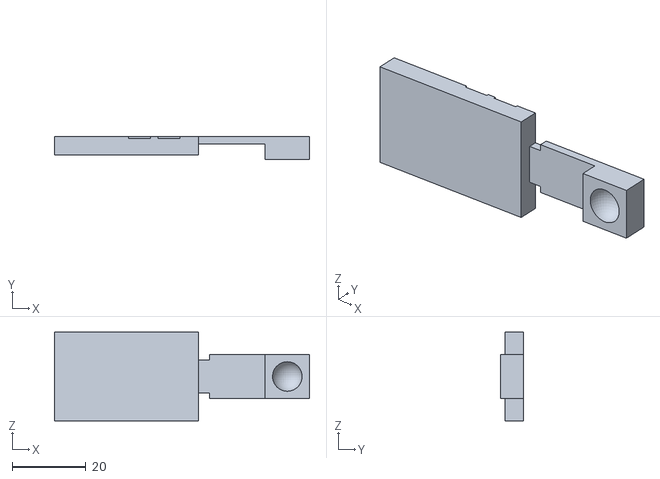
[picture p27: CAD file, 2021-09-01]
Development-Kit/Pithon Force Sensor, Accelerometer/mid_str_4T_sensing_1.STL
69.0 x 6.20 x 24.0

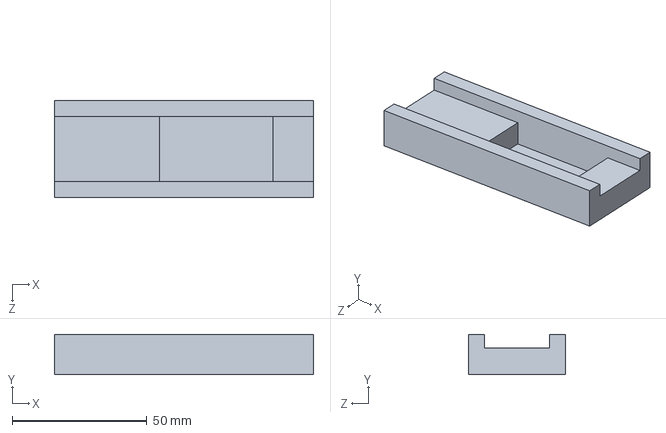
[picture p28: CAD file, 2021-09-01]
Development-Kit/Pithon Platform Implementation Example/platform_body_2.SLDPRT
96.0 x 15.0 x 36.0 mm

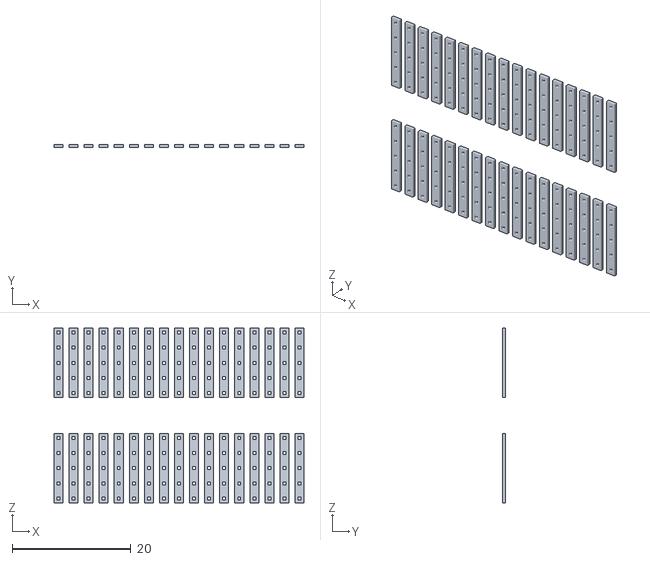
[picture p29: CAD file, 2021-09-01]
Development-Kit/Pithon Protoboard/protoboard Conductive Traces.STL
42.2 x 0.5 x 29.5

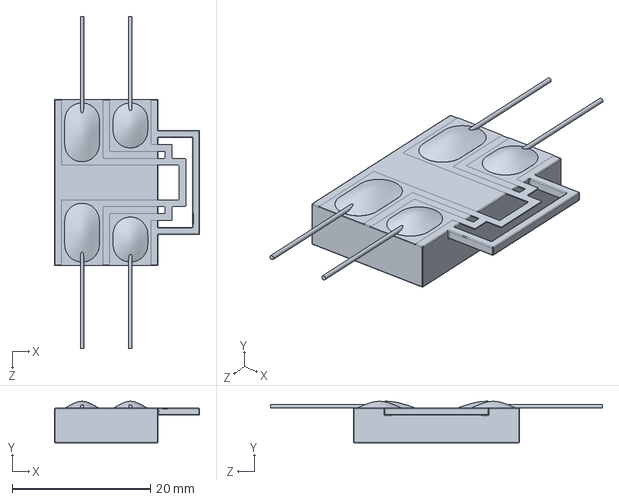
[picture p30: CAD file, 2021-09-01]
Development-Kit/Pithon Temperature Sensor/temp_4T_sensing_1_and_elem-Render.SLDPRT
21.0 x 6.01 x 48.0 mm

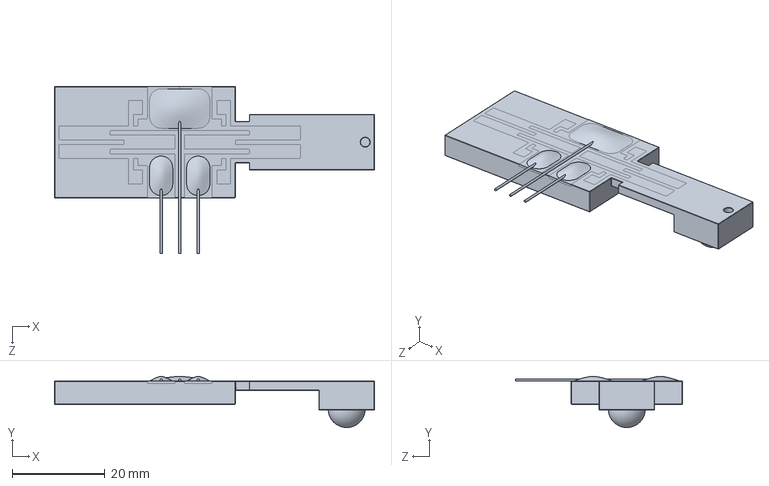
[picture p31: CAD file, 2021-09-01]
Development-Kit/Pithon Force Sensor, Accelerometer/mid_str_4T_sensing_1_and_elem-Render.SLDPRT
69.0 x 11.0 x 36.0 mm

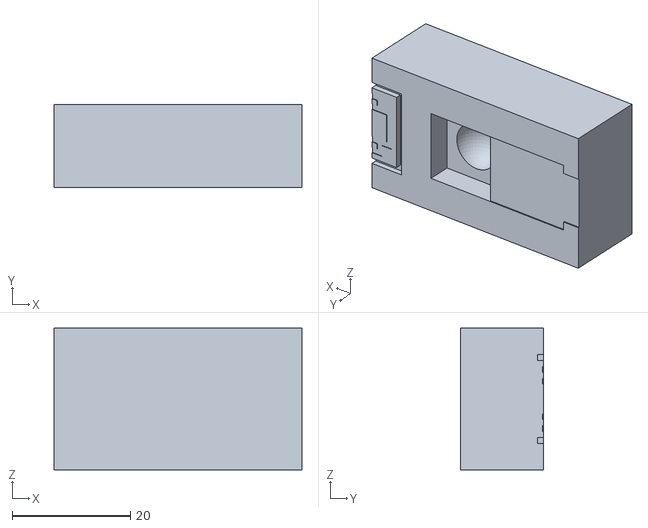
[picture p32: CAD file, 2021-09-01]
Development-Kit/Pithon Platform Implementation Example/platform_2 Filler Material.STL
42.0 x 14.0 x 24.0

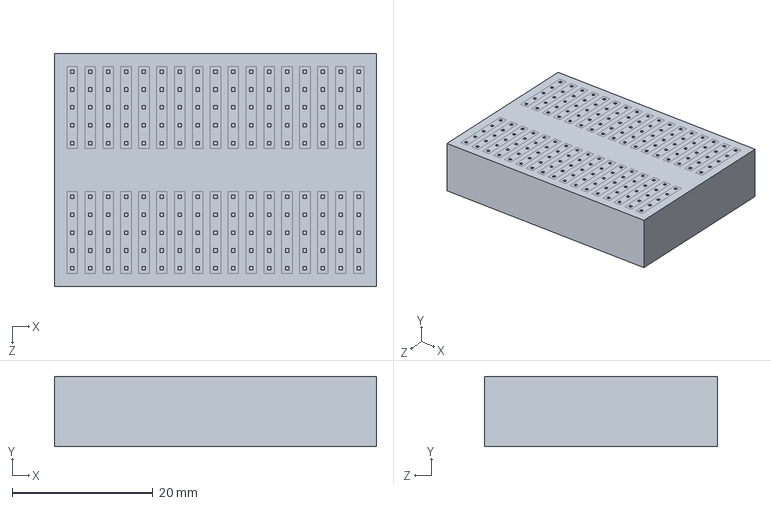
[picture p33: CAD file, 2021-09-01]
Development-Kit/Pithon Protoboard/protoboard.SLDPRT
45.7 x 10.0 x 33.0 mm

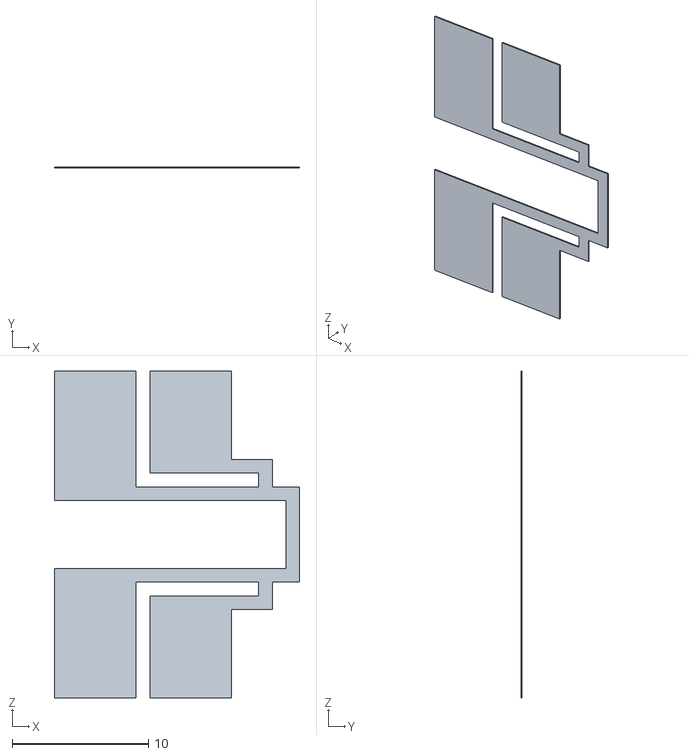
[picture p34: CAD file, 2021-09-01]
Development-Kit/Pithon Temperature Sensor/temp_4T_sensing_1_elem.STL
18.0 x 0.1 x 24.0

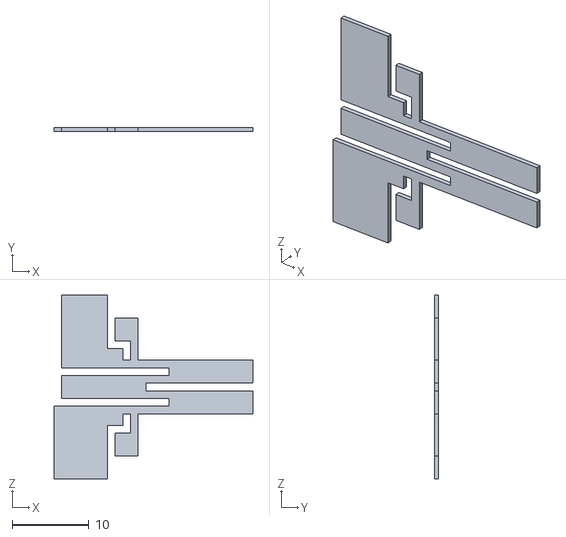
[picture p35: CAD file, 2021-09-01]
Development-Kit/Pithon Force Sensor, Accelerometer/mid_str_4T_sensing_1_elem.STL
26.0 x 0.5 x 24.0

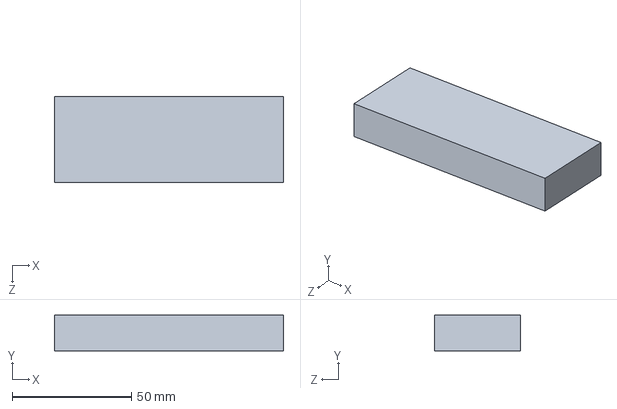
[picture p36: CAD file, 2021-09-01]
Development-Kit/Pithon Platform Implementation Example/platform_body_2 Parent Structure.SLDPRT
96.0 x 15.0 x 36.0 mm

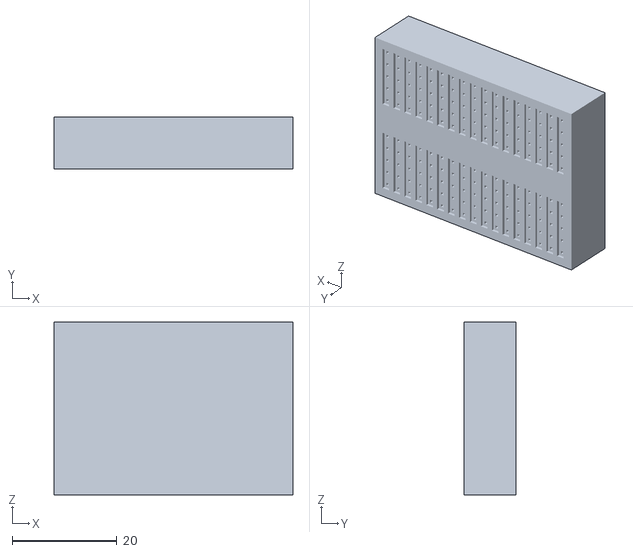
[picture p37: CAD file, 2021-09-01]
Development-Kit/Pithon Protoboard/protoboard Body.STL
45.7 x 10.0 x 33.0

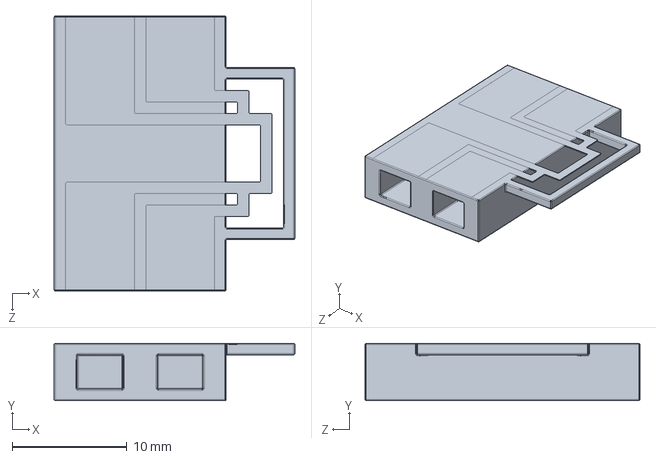
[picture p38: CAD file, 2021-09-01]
Development-Kit/Pithon Temperature Sensor/temp_4T_sensing_and_elem.SLDPRT
21.0 x 5.00 x 24.0 mm

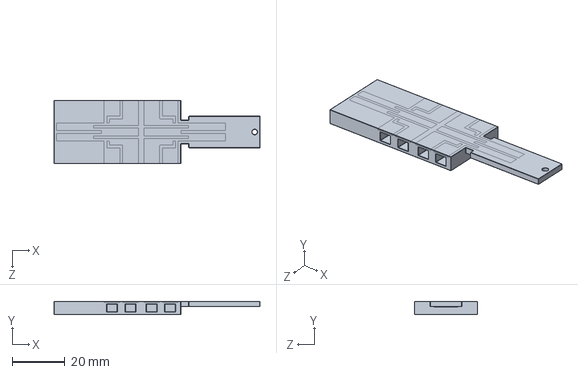
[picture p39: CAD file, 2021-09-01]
Development-Kit/Pithon Force Sensor, Accelerometer/mid_str_4T_sensing_and_elem.SLDPRT
78.0 x 5.00 x 24.0 mm

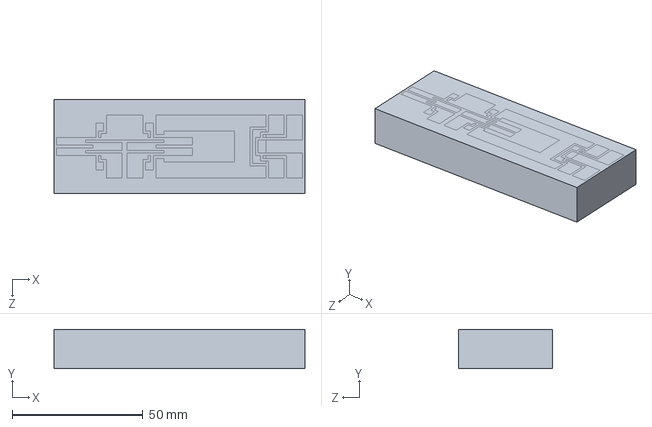
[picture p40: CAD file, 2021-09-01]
Development-Kit/Pithon Platform Implementation Example/platform_2.SLDPRT
96.0 x 15.0 x 36.0 mm

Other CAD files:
Development-Kit/Pithon Temperature Sensor/temp_4T_sensing_1.STL
Development-Kit/Pithon Platform Implementation Example/platform_2.3mf
Development-Kit/Pithon Protoboard/protoboard.3mf

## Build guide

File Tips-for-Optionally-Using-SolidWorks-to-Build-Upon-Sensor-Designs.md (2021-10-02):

[Download as PDF](https://raw.githubusercontent.com/keeganmjgreen/3D-Printed-Sensors-Development-Platform/main/pdf/Tips-for-Optionally-Using-SolidWorks-to-Build-Upon-Sensor-Designs.pd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)

----

# Tips for Optionally Using *SolidWorks* to Build Upon Sensor Designs

Use our sensor designs in SolidWorks at least as a starting point.

 -  Use one SolidWorks part file (`.SLDPRT` filename extension) for the body of the sensor(s) and one for each sensing element -- except, of course, for sensing elements that are the same. For example:
    
    | Part of a Strain Sensor | Filename of SolidWorks Part      |
    |:------------------------|:---------------------------------|
    | Sensor body             | `mid_str_4T_sensing.SLDPRT`      |
    | Sensing element         | `mid_str_4T_sensing_elem.SLDPRT` |
    
    Multibody parts or assemblies do not need to be created.
    
 -  Under *Tools* > *Options* > *Document Properties* > *Units* > *Unit system*, select *MMGS (millimeter, gram, second)*. We used millimeters in our project development. Furthermore, 3D printer *slicing* software such as *Ultimaker Cura* uses grams.
    
     -  [Units and Dimension Standard --- SolidWorks Help](http://help.solidworks.com/2021/English/SolidWorks/sldworks/HIDD_UNITS_DIM_STD.htm)
    
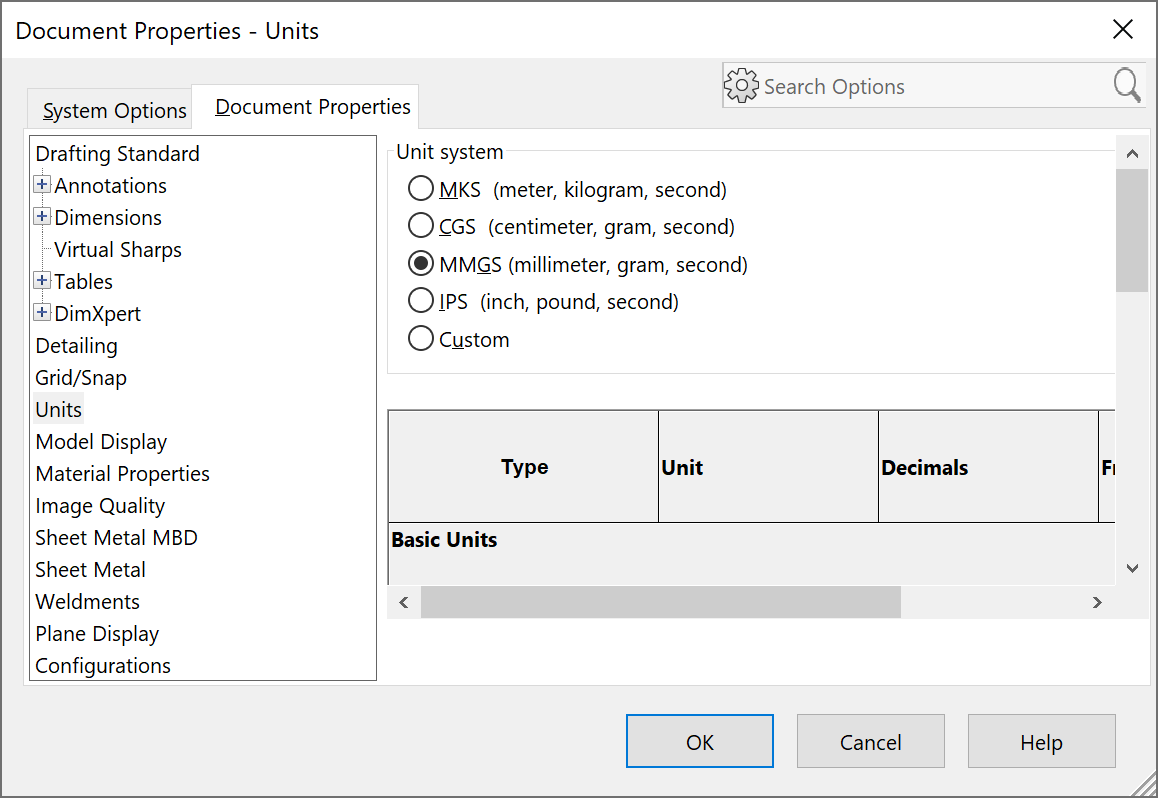
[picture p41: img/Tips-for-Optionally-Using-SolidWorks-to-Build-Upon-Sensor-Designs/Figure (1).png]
     \

 -  Under *Tools* > *Options* > *Document Properties* > *Grid/Snap* > *Grid*, enable the *Display grid* and *Dash* options. Set the *Major grid spacing* to 1 mm, *Minor-lines per major* to 2 if deemed necessary (1 otherwise), and *Snap points per minor* to 1. Creating and modifying SolidWorks sketches will be easier and faster.
    
     -  [Document Properties - Grid/Snap --- SolidWorks Help](https://help.solidworks.com/2021/English/SolidWorks/sldworks/HIDD_OPTIONS_GRID.htm)
     -  [Grid and Snap --- SolidWorks Help](http://help.solidworks.com/2021/English/SolidWorks/acadhelp/c_Grid_and_Snap.htm)
    
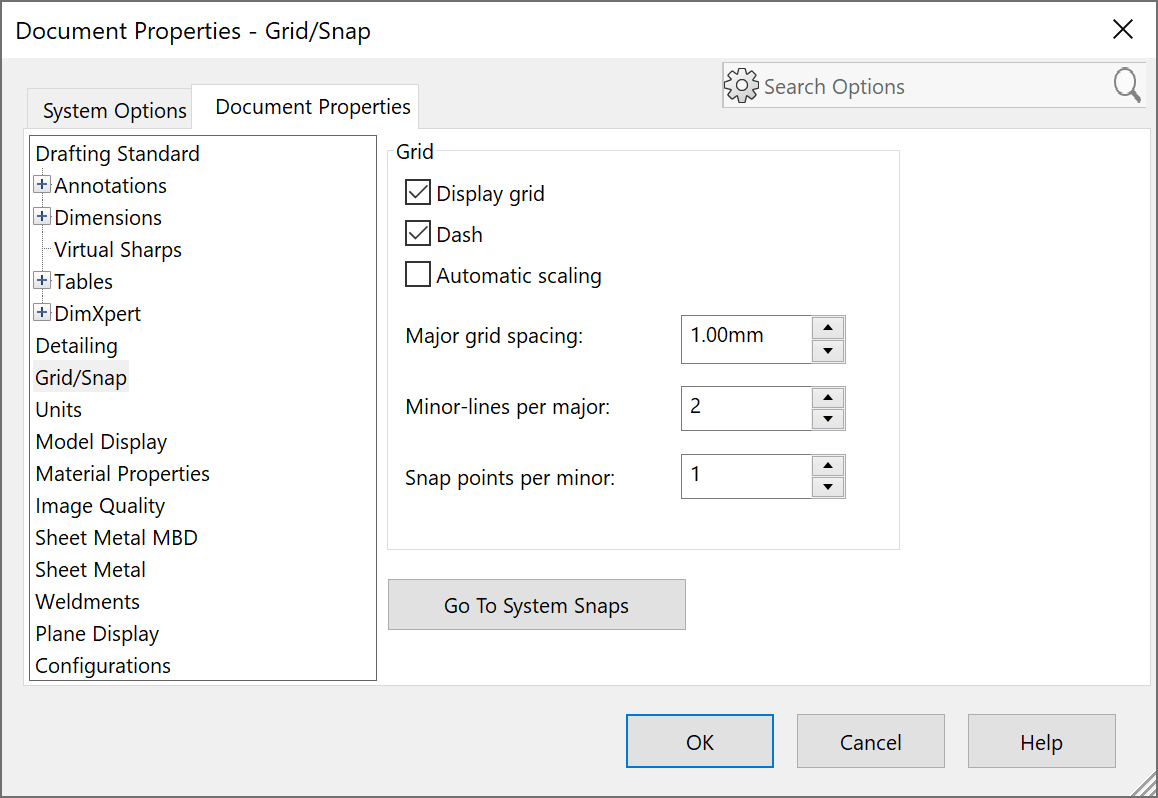
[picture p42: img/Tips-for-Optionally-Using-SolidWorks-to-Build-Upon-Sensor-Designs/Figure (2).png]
     \

 -  Optionally, insert a 'mask layout' raster image to trace in a SolidWorks sketch using *Tools* > *Sketch Tools* > [*Sketch Picture*](http://help.solidworks.com/2021/English/SolidWorks/sldworks/c_Sketch_Picture.htm). Ensure that the pixel grid lines up with the sketch grid.
    
     -  [Inserting Sketch Picture in Drawings --- SolidWorks Help](https://help.solidworks.com/2021/english/SolidWorks/sldworks/t_insert_sketch_picture_in_drawings.htm)
    
 -  As odd as it sounds, do not dimension or constrain sketches where snapping to the grid will suffice. Creating and modifying them will be easier and faster, and they will be simpler and less 'busy'. There are many other ways to set and measure lengths. To delete all constraints in a sketch, whether they are automatically-created or not, select *Sketch* > *Display/Delete Relations* > *Relations* > *Delete All*.
    
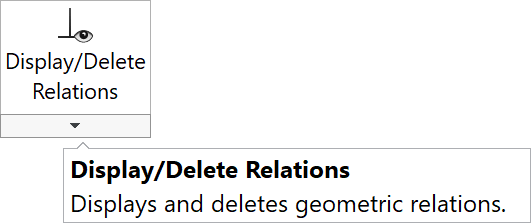
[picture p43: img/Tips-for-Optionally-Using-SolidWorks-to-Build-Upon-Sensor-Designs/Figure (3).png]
     \

 -  Use *linear sketch patterns*, as under *Sketch*.
    
    
    
     -  [Creating Linear Sketch Patterns --- SolidWorks Help](http://help.solidworks.com/2021/English/SolidWorks/sldworks/t_Creating_Linear_Sketch_Patterns.htm)
    
 -  Properly name each SolidWorks sketch and feature (e.g., each [extruded boss/base or extruded cut](https://help.solidworks.com/2021/english/solidworks/sldworks/t_creating_an_extrude_feature.htm), [fillet](https://help.solidworks.com/2021/english/SolidWorks/sldworks/t_create_fillets.htm), [chamfer](https://help.solidworks.com/2021/English/SolidWorks/sldworks/t_creating_chamfer_feature.htm), [pattern](http://help.solidworks.com/2021/English/SolidWorks/sldworks/c_Types_of_Patterns_Folder.htm), etc.). For example:
    
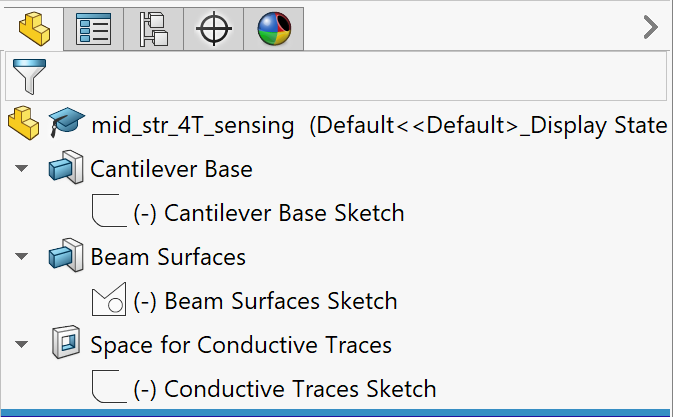
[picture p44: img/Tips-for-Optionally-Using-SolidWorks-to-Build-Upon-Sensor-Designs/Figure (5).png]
     \

 -  Create parts right-side-up even if they are designed to be printed upside-down against the *build plate*. \

 -  Create design features from the 'perspective' of a 3D printer. For example: [Create SolidWorks sketches](http://help.solidworks.com/2021/English/SolidWorks/sldworks/c_Sketch.htm) on the *Top Plane* and extrude them away from it. Note that SolidWorks uses an engineering coordinate system in which the $y$-axis points up and the $z$-axis is normal to the vertical $xy$-plane. Whereas, 3D printing software such as *Ultimaker Cura* uses a more conventional coordinate system, in which the $z$-axis points up, normal to the *build plate*, whose surface is the horizontal $xy$-plane.

*Note:* SolidWorks is not forward compatible. Files cannot be opened or edited using a version of SolidWorks that is older than that with which they were originally created. The reverse works, albeit by converting them to the newer version.

## Resources

 -  [SolidWorks Help](https://help.solidworks.com/2021/English/SolidWorks/sldworks/r_welcome_sw_online_help.htm)

----

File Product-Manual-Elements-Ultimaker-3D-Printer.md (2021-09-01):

This page is no longer pertinent but remains searchable.

----

# Product Manual Elements: [Ultimaker](https://ultimaker.com/) 3D Printer

[*Ultimaker 3* PDF manual](https://support.ultimaker.com/hc/en-us/article_attachments/360010836740/Ultimaker_3_manual__En_.pdf)

**Note:** Title case italics indicate the names of chapters ("X."), sections ("X.Y"), and headings (unnumbered). Ellipses just indicate that one or more of these have been omitted in-place for brevity and/or keeping relevance to product manuals in general and that which we expect to be our own. Arrows indicate changes for the sake of relevance to product manuals in general, and so on and so forth.

 -  Title page
     -  "Ultimaker 3: Installation and User Manual"
     -  Version number
     -  Year
 -  No header and footer except page numbers from unnumbered title page
 -  *Disclaimer*
     -  Intended use
 -  Compliance note
 -  Copyright notice
 -  *Table of Contents* (including previous *Disclaimer*) with both links and page numbers but without chapter or section numbers
 -  New-section pages with intros
 -  *Preface*
 -  *Certifications*
     -  Certification logos
     -  For the latest version of the [CE](https://ec.europa.eu/growth/single-market/ce-marking/) document go to \[web address\]"
 -  *1. Safety and Compliance*
     -  *1.1 Safety Messages*
         -  Admonitions: information, warnings, etc.?
         -  *General Safety Information*
         -  ...
     -  *1.2 Hazards*
         -  ISO 7010 safety signs (resources: [Wikipedia](https://en.wikipedia.org/wiki/ISO_7010), [Wikimedia Commons](https://commons.wikimedia.org/wiki/Category:ISO_7010_safety_signs_(vector_drawings)))
         -  ...
         -  *Electrical Safety*
         -  ...
         -  *Health and Safety*
 -  *2. Introduction*
     -  *2.1 Main Components*
         -  Labeled diagram
     -  *2.2 Specifications*
         -  Specs tabulated under respective headings
         -  ...
         -  *Physical Dimensions*
         -  *Power Requirements*
         -  *Ambient Conditions*
         -  *Software*
 -  *3. Unpack and Install the Hardware*
     -  ...
     -  *3.2 Installing the Hardware Accessories*
         -  ...
         -  *Connecting the Power Supply*
 -  *4. Set Up for First Use*
     -  *Print Core Installation* $\to$ Installation
     -  ...
 -  *5. Operation*
     -  *Control and Display* $\to$ Control
         -  *Control*
         -  ...
     -  *Materials*
         -  Inline with text: Material compatibility **tables** with legends
     -  *Preparing a Print with Ultimaker Cura* $\to$ Preparation?
     -  ...
     -  *Calibration*
 -  *6. Maintenance*
     -  *Updating the Firmware* $\to$ Updating the Software
     -  ...
 -  *7. Troubleshooting*
     -  *Error messages*?
         -  Links to [online reference](https://support.ultimaker.com/hc/en-us/sections/360003523739-Error-Messages)
     -  ...
 -  Inline with text: GUI **screenshots**
 -  Inline with text: Numerous **photo graphics**
 -  Plenty of whitespace
 -  Subtle aesthetics
 -  Back cover page

| [*Ultimaker 3* -- Ultimaker Support](https://support.ultimaker.com/hc/en-us/sections/360003548399-Ultimaker-3) |
|:--|
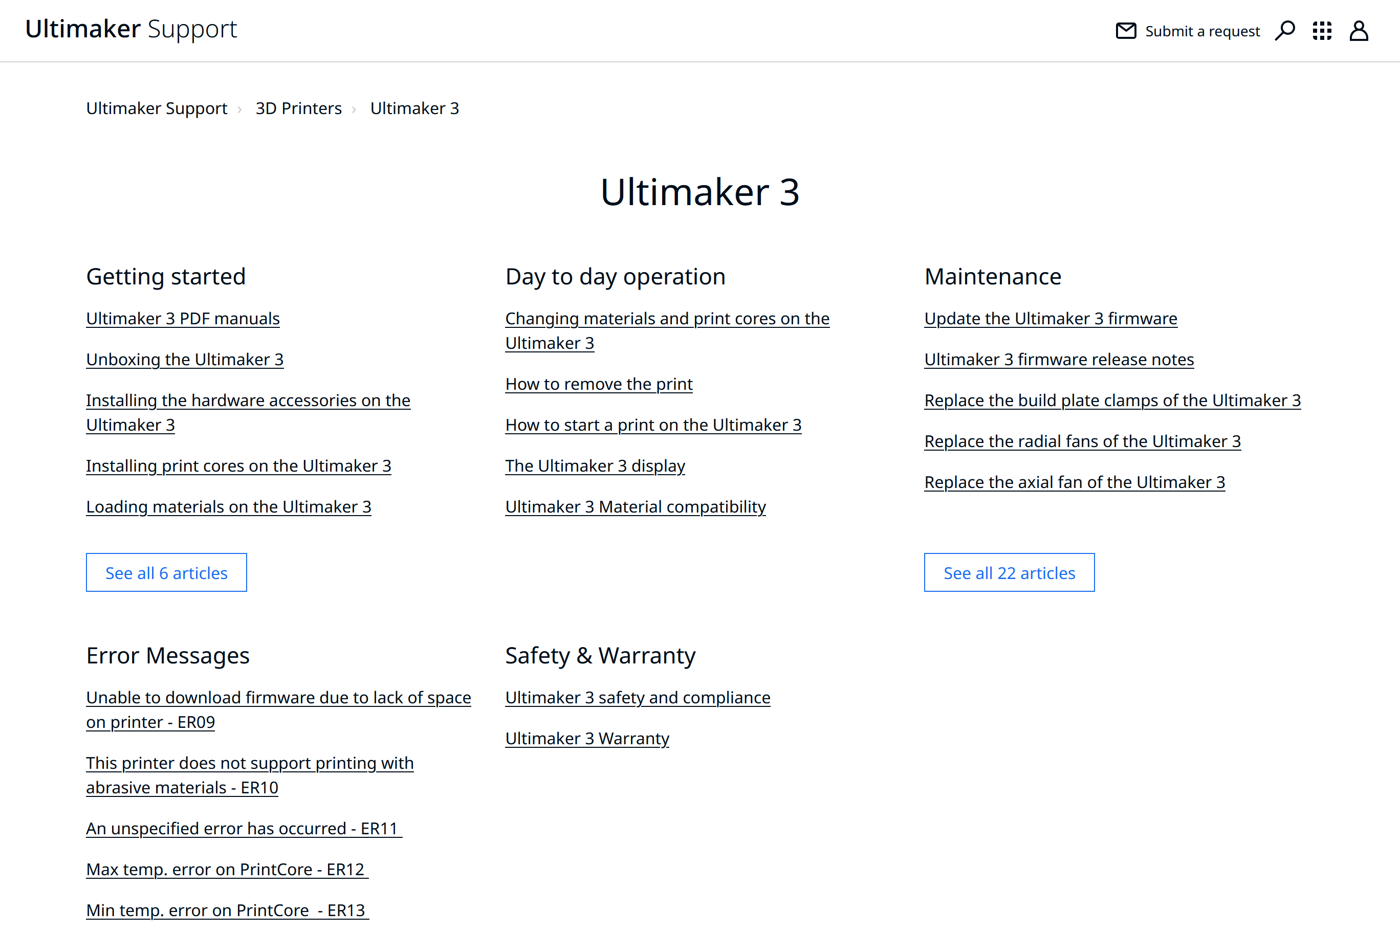
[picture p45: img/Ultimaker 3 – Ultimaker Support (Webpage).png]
|  |

| [Loading Materials on the *Ultimaker 3* -- Ultimaker Support](https://support.ultimaker.com/hc/en-us/articles/360011424760-Loading-materials-on-the-Ultimaker-3) |
|:--|
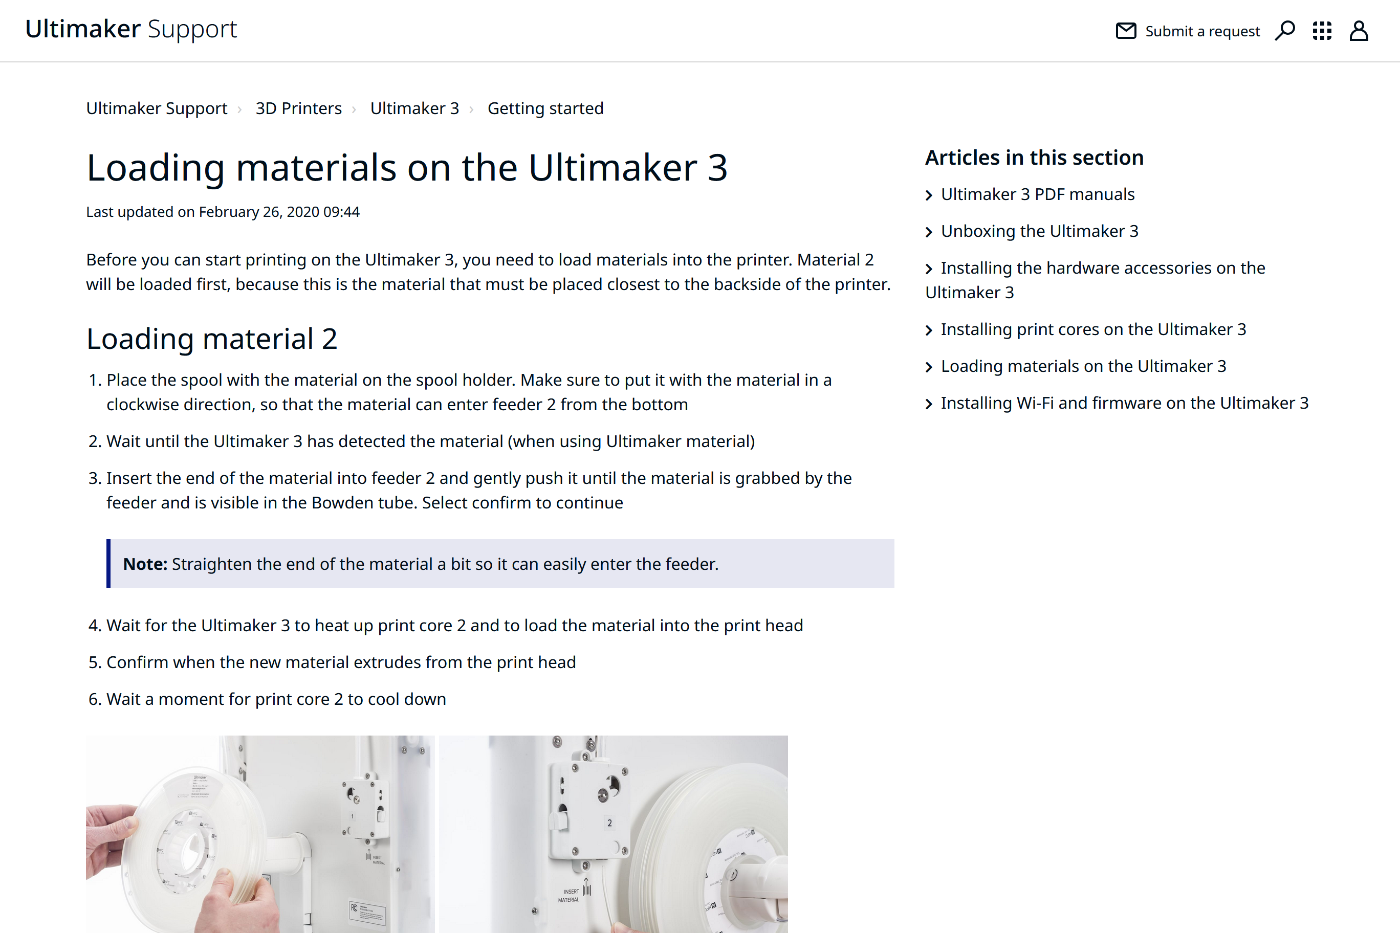
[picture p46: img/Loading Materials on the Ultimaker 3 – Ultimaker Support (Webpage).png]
|  |

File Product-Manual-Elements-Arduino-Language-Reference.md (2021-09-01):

This page is no longer pertinent but remains searchable.

----

# Product Manual Elements: [Arduino Language Reference](https://www.arduino.cc/reference/en/)

**Note:** Title case italics indicate the names of chapters, sections, pages, and headings (all unnumbered).

 -  Website navigation
 -  Language selection
 -  Left-hand column
    
     -  Small chapter-level table of contents (TOC)
     -  Links to other documentation
     -  [Licensing](https://creativecommons.org/licenses/)
     -  Contributions, e.g.,
        
         >  Find anything that can be improved? [Suggest corrections and new documentation via GitHub.](https://github.com/arduino/reference-en)
         >  
         >  Doubts on how to use Github? Learn everything you need to know in [this tutorial](https://create.arduino.cc/projecthub/Arduino_Genuino/contribute-to-the-arduino-reference-af7c37). 
    
 -  TOC page with inline header descriptions, e.g.,
    
     >  [*Language Reference*](https://www.arduino.cc/reference/en/) \
     >  Arduino programming language can be divided in three main parts: functions, values (variables and constants), and structure...
    
     >  [*Functions*](https://www.arduino.cc/reference/en/#functions) \
     >  For controlling the Arduino board and performing computations.
    
     >  [*Variables*](https://www.arduino.cc/reference/en/#variables) \
     >  Arduino data types and constants.
    
     >  [*Structure*](https://www.arduino.cc/reference/en/#structure) \
     >  The elements of Arduino (C++) code.
    
    Etc.
    
 -  *Functions*, e.g.,
    
    *Analog I/O*, e.g., *analogRead()* -- of particular relevance to us

     -  *Description*
        
         -  Inline with text: **table** with footnotes
        
     -  *Syntax*
     -  *Parameters*
     -  *Returns*
     -  *Example Code*
        
         -  Inline with text: **code block**, e.g.,
            
            ``` C++
            int analogPin = A3; // potentiometer wiper (middle terminal) connected to analog pin 3
                                // outside leads to ground and +5V
            int val = 0;  // variable to store the value read

            void setup() {
              Serial.begin(9600);           //  setup serial
            }

            void loop() {
              val = analogRead(analogPin);  // read the input pin
              Serial.println(val);          // debug value
            }
            ```
            
     -  *Notes and Warnings*
     -  *See Also*, e.g.,
        
        Language: [*analogReadResolution()*](https://www.arduino.cc/reference/en/language/functions/zero-due-mkr-family/analogreadresolution/)

        Example: [*Description of the analog input pins*](https://www.arduino.cc/en/Tutorial/Foundations/AnalogInputPins)
        
     -  Last page revision
     -  Last page build
     -  Link to "[edit this page](https://github.com/arduino/reference-en/edit/master/Language/Functions/Analog%20IO/analogRead.adoc)"
    
    *Communication*, e.g., *Serial* -- of particular relevance to us
    
 -  Footers, incl. copyright notice

| [Arduino Language Reference](https://www.arduino.cc/reference/en/) |
|:--|
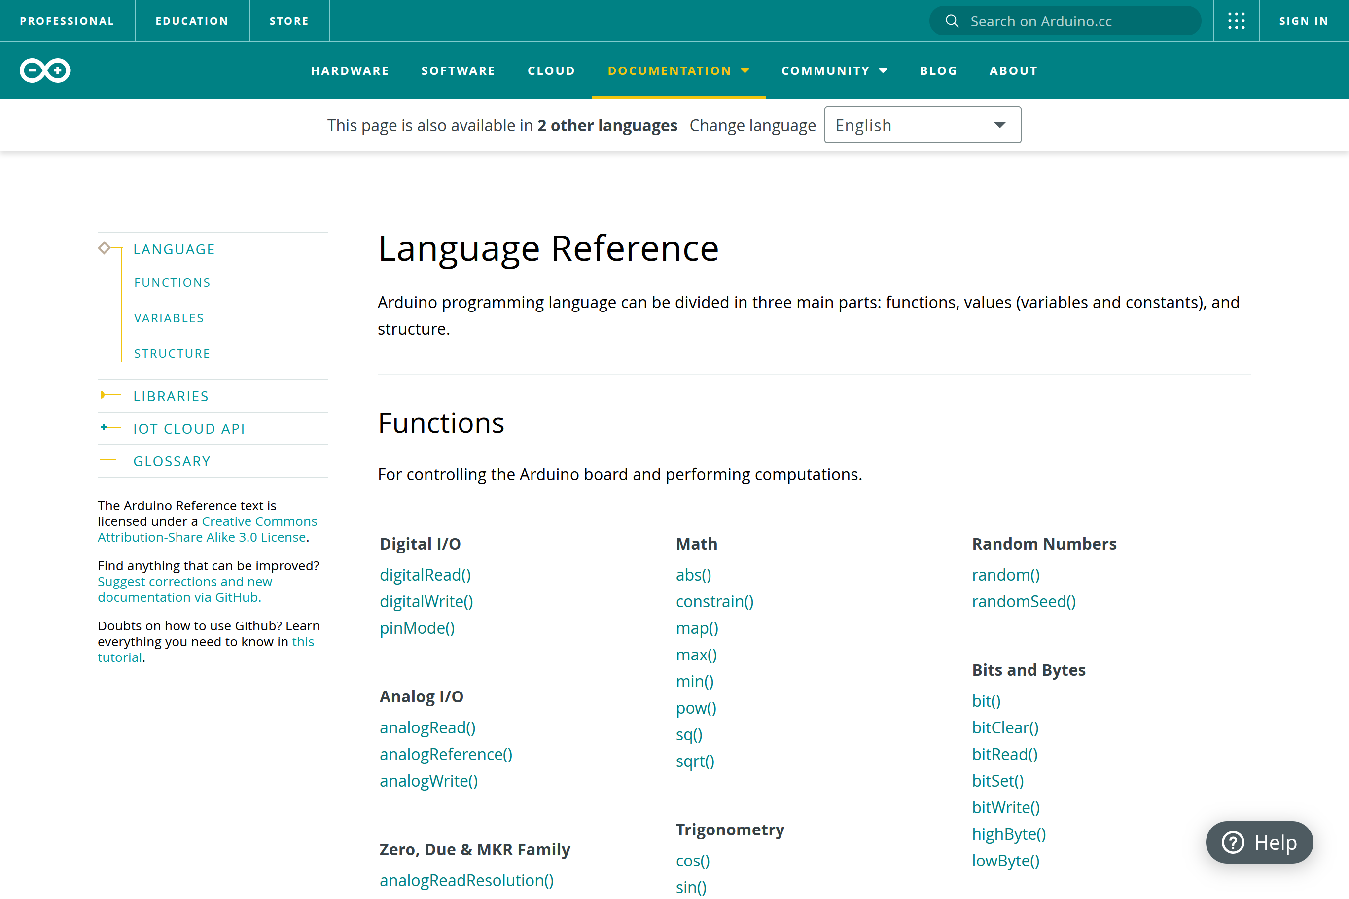
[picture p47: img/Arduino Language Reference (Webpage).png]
|  |

| [analogRead() -- Arduino Language Reference](https://www.arduino.cc/reference/en/language/functions/analog-io/analogread/) |
|:--|
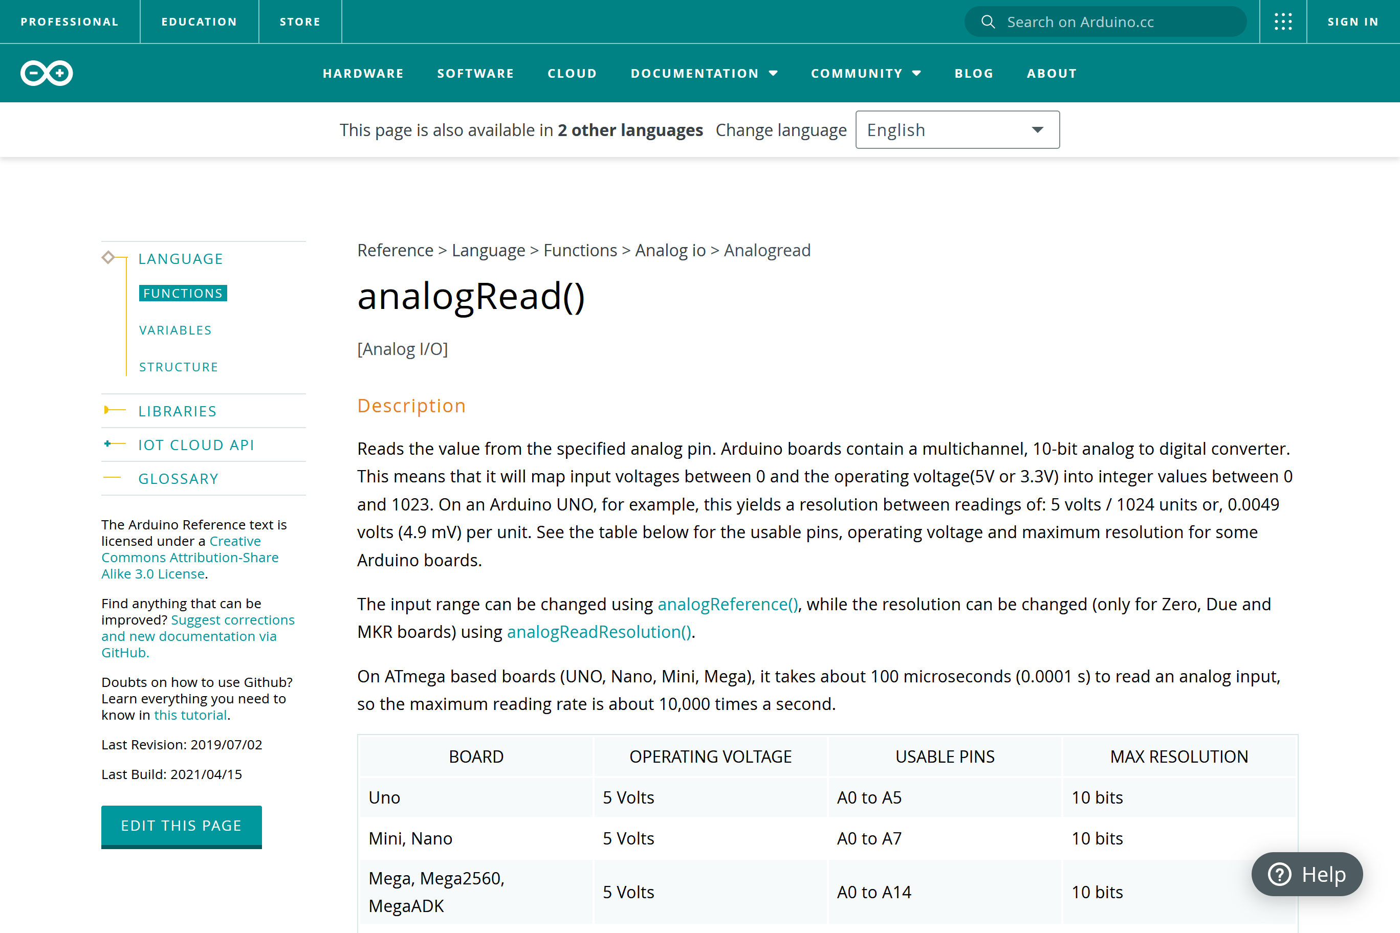
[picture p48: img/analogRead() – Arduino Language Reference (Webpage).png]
|  |

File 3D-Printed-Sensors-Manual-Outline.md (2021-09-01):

This page is no longer pertinent but remains searchable.

----

# 3D Printed Sensors Manual Outline

----

-  Title page
     -  Working title: "Monti Pithon Platform for 3D Printed Sensors: Technical/User Documentation"
     -  Version number: vX.X
     -  Year: 2021
 -  Header and footer including page numbers from unnumbered title page
 -  *Legal Disclaimer*
     -  Intended use
 -  *Glossary*
 -  Compliance note
 -  Copyright notice
 -  *Table of Contents* (including previous *Legal Disclaimer*) with both links and page numbers but without chapter or section numbers
 -  New-section pages with intros
 -  *Preface*
 -  *Certifications* (if applicable)
     -  Certification logos
     -  For the latest version of the [CE](https://ec.europa.eu/growth/single-market/ce-marking/) document go to \[web address\]"
 -  *1. Safety and Compliance*
     -  *1.1 Safety Messages*
         -  Admonitions: information, warnings, etc.?
         -  *General Safety Information*
         -  ...
     -  *1.2 Hazards*
         -  ISO 7010 safety signs (resources: [Wikipedia](https://en.wikipedia.org/wiki/ISO_7010), [Wikimedia Commons](https://commons.wikimedia.org/wiki/Category:ISO_7010_safety_signs_(vector_drawings)))
         -  ...
         -  *Electrical Safety*
         -  ...
         -  *Health and Safety*
 -  *2. Introduction*
     -  *2.1 Main Components*
         -  Labeled diagram
     -  *2.2 Specifications*
         -  Specs tabulated under respective headings
         -  ...
         -  *Physical Dimensions*
         -  *Power Requirements*
         -  *Ambient Conditions*
         -  *Software*
 -  *3. Hardware Installation*
 -  *4. Initial Setup / Quick Start Guide*
 -  *5. Operation*
     -  *5.1 Control*
     -  *5.2 Materials*
         -  Material compatibility **tables** with legends?
     -  *5.3 Print Preparation*(*s*?)
     -  *5.4 Calibration*
     -  *Calibration*
 -  *6. Maintenance*
     -  *6.1 Maintaining your Printer (refers to printer manual)*
     -  *6.2 Sensor Verification Tests*
     -  *6.3 Updating the Software*
 -  *7. Troubleshooting*
     -  *7.1 Error Messages and Their Meanings*
         -  Links to online reference?
     -  *7.2 Frequently Asked Questions*
     -  ...
 -  Inline with text: GUI **screenshots**
 -  Inline with text: Numerous **photo graphics**
 -  Plenty of whitespace
 -  Subtle aesthetics
 -  Back cover page

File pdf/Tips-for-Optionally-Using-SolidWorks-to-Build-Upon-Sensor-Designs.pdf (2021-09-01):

# Tips for Optionally Using SolidWorks to Build Upon Sensor Designs

Use our sensor designs in SolidWorks at least as a starting point.

Use one SolidWorks part file ( .SLDPRT filename extension) for the body of the sensor(s) and one for each sensing element – except, of course, for sensing elements that are the same. For example:

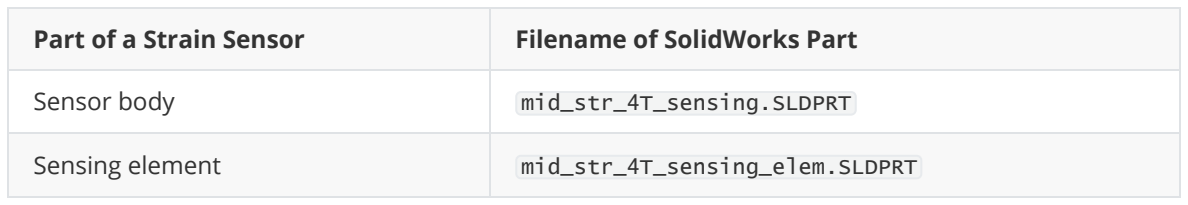
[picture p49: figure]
Part of a Strain Sensor; Filename of SolidWorks Part; Sensor body; mid_str_4T_sensing.SLDPRT; Sensing element; mid_str_4T_sensing_elem.SLDPRT

Multibody parts or assemblies do not need to be created.

Under Tools > Options > Document Properties > Units > Unit system, select MMGS (millimeter, gram, second). We used millimeters in our project development. Furthermore, 3D printer slicing software such as Ultimaker Cura uses grams.
Units and Dimension Standard — SolidWorks Help (http://help.solidworks.com/2021/English/SolidWorks/sldworks/HIDD_UNITS_DIM_STD.htm)


Under Tools > Options > Document Properties > Grid/Snap > Grid, enable the Display grid and Dash options. Set the Major grid spacing to 1 mm, Minor-lines per major to 2 if deemed necessary (1 otherwise), and Snap points per minor to 1. Creating and modifying SolidWorks sketches will be easier and faster.
Document Properties - Grid/Snap — SolidWorks Help (https://help.solidworks.com/2021/English/SolidWorks/sldworks/HIDD_OPTIONS_GRID.htm)
Grid and Snap — SolidWorks Help (http://help.solidworks.com/2021/English/SolidWorks/acadhelp/c_Grid_and_Snap.htm)


Optionally, insert a ‘mask layout’ raster image to trace in a SolidWorks sketch using Tools > Sketch Tools > Sketch Picture. (http://help.solidworks.com/2021/English/SolidWorks/sldworks/c_Sketch_Picture.htm) Ensure that the pixel grid lines up with the sketch grid.
Inserting Sketch Picture in Drawings — SolidWorks Help (https://help.solidworks.com/2021/english/SolidWorks/sldworks/t_insert_sketch_picture_in_drawings.htm)

As odd as it sounds, do not dimension or constrain sketches where snapping to the grid will suffice. Creating and modifying them will be easier and faster, and they will be simpler and less ‘busy’. There are many other ways to set and measure lengths. To delete all constraints in a sketch, whether they are automatically-created or not, select Sketch > Display/Delete Relations > Relations > Delete All.

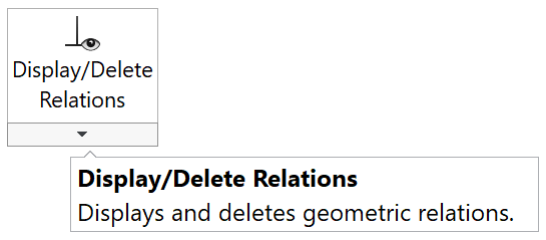
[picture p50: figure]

Use linear sketch patterns, as under Sketch.

Creating Linear Sketch Patterns — SolidWorks Help (http://help.solidworks.com/2021/English/SolidWorks/sldworks/t_Creating_Linear_Sketch_Patterns.htm)

Properly name each SolidWorks sketch and feature (e.g., each extruded boss/base or extruded cut, (https://help.solidworks.com/2021/english/solidworks/sldworks/t_creating_an_extrude_feature.htm) fillet, (https://help.solidworks.com/2021/english/SolidWorks/sldworks/t_create_fillets.htm) chamfer, (https://help.solidworks.com/2021/English/SolidWorks/sldworks/t_creating_chamfer_feature.htm) pattern, (http://help.solidworks.com/2021/English/SolidWorks/sldworks/c_Types_of_Patterns_Folder.htm) etc.). For example:

Create parts right-side-up even if they are designed to be printed upside-down against the build plate.

Create design features from the ‘perspective’ of a 3D printer. For example: Create SolidWorks sketches (http://help.solidworks.com/2021/English/SolidWorks/sldworks/c_Sketch.htm) on the Top Plane and extrude them away from it. Note that SolidWorks uses an engineering coordinate system in which the -axis points up and the -axis is normal to the vertical -plane. Whereas, 3D printing software such as Ultimaker Cura uses a more conventional coordinate system, in which the -axis points up, normal to the build plate, whose surface is the horizontal -plane.

Note: SolidWorks is not forward compatible. Files cannot be opened or edited using a version of SolidWorks that is older than that with which they were originally created. The reverse works, albeit by converting them to the newer version.

# Resources

SolidWorks Help (https://help.solidworks.com/2021/English/SolidWorks/sldworks/r_welcome_sw_online_help.htm)

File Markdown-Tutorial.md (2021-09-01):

This page is no longer pertinent but remains searchable.

----

# Markdown Tutorial #

This page is a compilation of resources for learning the Markdown language.

1. [Markdown Cheat Sheet](https://www.markdownguide.org/cheat-sheet/)
2. [Syntax Quick Reference](https://www.markdownguide.org/basic-syntax/)
3. [Comprehensive Markdown Guide](https://www.markdownguide.org/getting-started/)

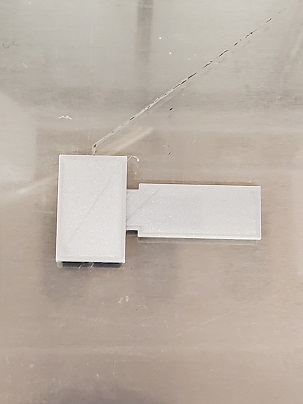
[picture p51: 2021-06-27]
img/Preparing-Electrical-Contacts/CantileverOnPrintBed.jpg

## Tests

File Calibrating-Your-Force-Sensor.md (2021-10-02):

[Download as PDF](https://raw.githubusercontent.com/keeganmjgreen/3D-Printed-Sensors-Development-Platform/main/pdf/Calibrating-Your-Force-Sensor.pdf)

----

<iframe width="560" height="315" src="https://www.youtube.com/embed/dds3cxvsOXw" title="YouTube video player" frameborder="0" allow="accelerometer; autoplay; clipboard-write; encrypted-media; gyroscope; picture-in-picture" allowfullscreen></iframe>

# Calibrating Your Force Sensor

The Pithon strain gauge / force sensor is calibrated for use by applying known weights to it and measuring its response in order to work backward from it. The weights are applied in an incremental, random, and/or cyclic loading profile over calibration time. A cyclic loading profile characterizes sensor behavior in terms of loading/unloading hysteresis, and a random loading profile minimizes the resulting effects.

## Materials and Preparation

 -  An untested force sensor with the following defaults from `mid_str_4T_sensing_and_elem.SLDPRT`.
    
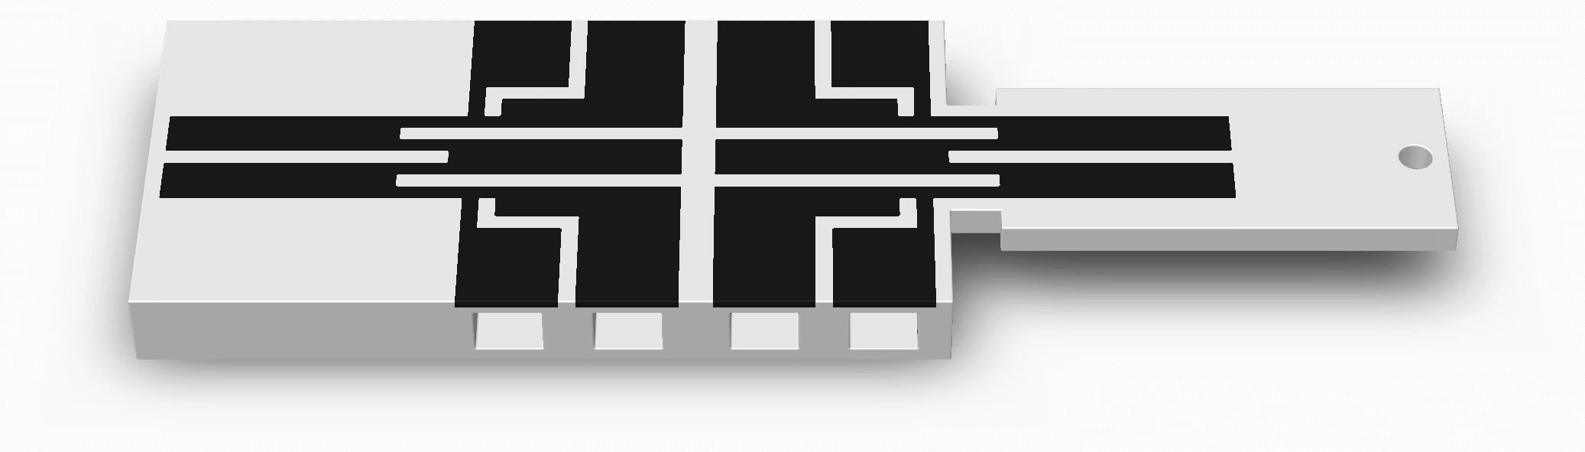
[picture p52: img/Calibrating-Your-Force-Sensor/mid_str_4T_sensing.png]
     
    
     -  A hole close to the end of the cantilever beam ("Free End Hole" in the SolidWorks part) from which to suspend known weights
        
        If you would like to use a force sensor that you have already printed without a free end hole, you can drill or punch a hole in the same place.
        
     -  A similarly thick cantilever base to avoid unwanted deflection, emulating being embedded into your comparably large parent 3D printed structure
        
        If you do not need spaces for the lower jaws of crocodile clips in a thick cantilever base, and would prefer it to lessen your print time, you can glue a thinner cantilever base to a piece of wood to be used as the cantilever base.
        
     -  A reference set of conductive traces to correct for changes in temperature and humidity (recommended)
        
     -  4-terminal sensing in each set of conductive traces (recommended)
        
     -  Large electrical contact pads
        
     -  Spaces for lower jaws of crocodile clips (optional) \

 -  An insulated double-ended crocodile clip jumper (or conductive paint/epoxy and lengths of thin wire stripped of their insulation on both ends) for *each* electrical contact
    
 -  A table clamp/vice
    
 -  Some string or more thin wire
    
 -  A laboratory weight set or similar \

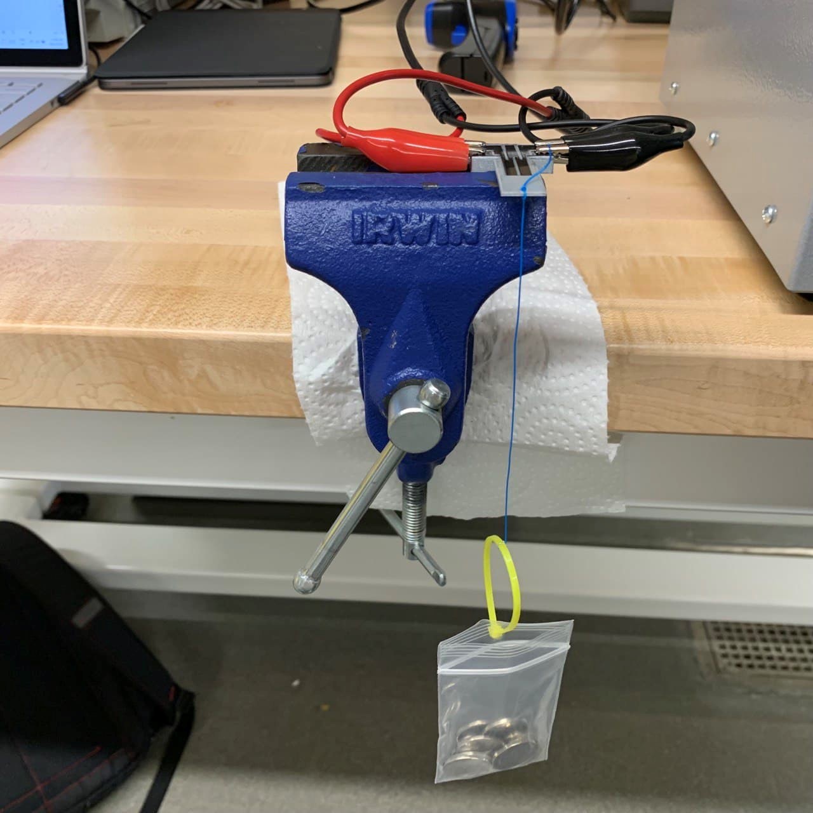
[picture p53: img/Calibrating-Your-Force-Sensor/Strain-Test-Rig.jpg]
 

$\uparrow$ A test rig of a force sensor that has a 1-mm cantilever beam and no reference set of conductive traces. Also shown are its crocodile clips, table clamp, and known weights in a pouch suspended by a wire from the cantilever beam's free end hole.

## Instructions

| Note |
|:-|
| Many of the following tasks are no longer necessary or now semi-automated using the [Pithon software](https://3d-printed-sensors-development-platform.readthedocs.io/en/latest/Pithon-Software.html) for calibration data collection, preparation, and processing. |

 1. Mount your clamp/vice on a table as shown above.
    
 2. Clamp onto your force sensor's cantilever base without the conductive traces being touched as shown above. Leave room for your crocodile clips if you are using them, room for the cantilever beam to bend downward, and room to suspend your weights from the cantilever beam's free end.
    
 3. Tie your string or spare wire securely to the free end hole as shown above. Ensure that its mass is nearly 0 grams beforehand.
    
 4. Tie a loop at the other end of your string or spare wire.
    
 5. If you are not using weights with hooks, hang a lightweight clear plastic pouch from the loop to hold them as shown above but without its weights. Ensure that its mass is nearly 0 grams beforehand.
    
 6. Clip one end of your crocodile clip jumpers into the terminal slots, onto the surfaces of the electrical terminals as shown above (or follow the instructions in **Preparing Electrical Contacts**).
    
 7. Now, assuming that you are using an Arduino microcontroller, open its IDE on your computer.
    
 8. Follow **2-Terminal Sensing for Real-Time Data Logging Using a Microcontroller** or **4-Terminal Sensing for Real-Time Data Logging Using a Microcontroller** as applicable per set of conductive traces. Use the Arduino Serial Monitor, and make the following changes to the code under **Instructions – Programming**.
    
     1. Immediately after `Serial.begin(9600)`, append `Serial.setTimeout(100);`. This strikes a balance between a good sampling frequency (almost 10 per second) and stability over serial communication.
        
     2. Immediately before the end of the `loop()` function, append `Serial.print(Serial.readStringUntil("\r\n"));`. This will loop-back text that you enter in your serial monitor to log it for reasons that will become apparent.
    
 9. Plug in your Arduino using its USB cable.
    
10. Upload your modified code to the board using the Arduino IDE, after which it will begin running onboard.
    
11. In your Arduino IDE, open the serial monitor. You should see lines of electrical resistance values (in ohms) updated in real time from your sensor using your Arduino.
    
12. Wait momentarily while recording data -- say, roughly 100 samples. Be careful not to touch your sensor or its load.
    
13. Type "0 grams" into your serial monitor and *Send* this message to your Arduino and back (to record it conveniently in the same place) for the purpose of marking an upcoming change to the applied load. For example...
    
    ```
    ⁞
    3833.33
    0 grams
    3877.55
    ⁞
    ```
    
14. Gently suspend the smallest weight -- say, 4 grams -- from the cantilever beam's free end hole and wait briefly for your cantilever beam to settle under its new load.
    
15. Then, enter "4 grams" into your serial monitor. For example...
    
    ```
    ⁞
    3884.76
    4 grams
    3877.55
    ⁞
    ```
    
15. Repeat the last 4 steps for further incremental sums of masses.
    
16. Unplug your Arduino. Your serial monitor will 'freeze'.
    
17. Copy the partitioned runs of resistance data and save them into a text file, Excel workbook, etc. For example...
    
    | Column 1 |
    |---------:|
    |        ⁞ |
    |  3833.33 |
    |  0 grams |
    |  3877.55 |
    |        ⁞ |
    |  3884.76 |
    |  4 grams |
    |  3877.55 |
    |        ⁞ |
    
18. Discard the resistance values *between* framed weight increments as being subject to the impulses of suddenly loading and unloading weights. For example...
    
    | Number of weights | Mass in grams | Resistance in ohms |
    |------------------:|--------------:|-------------------:|
    |                 ⁞ |             ⁞ |                  ⁞ |
    |                 0 |             0 |            3870.37 |
    |                 0 |             0 |            3851.85 |
    |                 0 |             0 |            3833.33 |
    |                 1 |             4 |            3877.55 |
    |                 1 |             4 |            3870.37 |
    |                 1 |             4 |            3851.85 |
    |                 ⁞ |             ⁞ |                  ⁞ |
    
19. Average the resistance values *within* framed weight increments as only being subject to measurement noise. For example...
    
    | Number of weights | Mass in grams | Resistance in ohms | Number of samples |
    |------------------:|--------------:|-------------------:|------------------:|
    |                 0 |             0 |            3860.91 |              200  |
    |                 1 |             4 |            3866.34 |               54  |
    |                 2 |             8 |            3874.94 |              192  |
    |                 3 |            12 |            3877.61 |              165  |
    |                 4 |            16 |            3883.74 |              127  |
    |                 5 |            20 |            3889.58 |             3491  |
    |                 6 |            24 |            3896.26 |              127  |
    |                 7 |            28 |            3903.50 |              101  |
    |                 8 |            32 |            3912.05 |              138  |
    |                 9 |            36 |            3919.69 |              153  |
    |                10 |            40 |            3931.75 |              272  |
    
20. Convert the masses (in units of grams) to force values (in units of Newtons) by multiplying them by 10 ≈ 9.81 m/s². For example...
    
    | Force in Newtons | Resistance in ohms |
    |-----------------:|-------------------:|
    |             0.00 |            3860.91 |
    |             0.04 |            3866.34 |
    |             0.08 |            3874.94 |
    |             0.12 |            3877.61 |
    |             0.16 |            3883.74 |
    |             0.20 |            3889.58 |
    |             0.24 |            3896.26 |
    |             0.28 |            3903.50 |
    |             0.32 |            3912.05 |
    |             0.36 |            3919.69 |
    |             0.40 |            3931.75 |
    
20. Plot resistance against force. For example... \
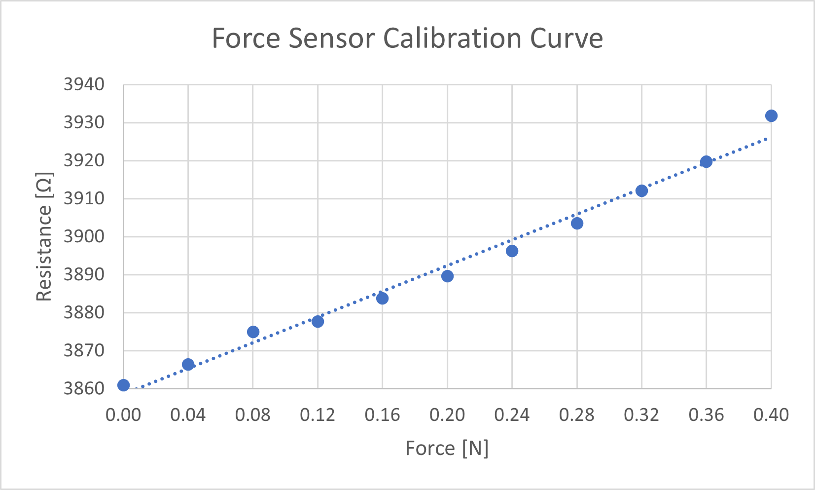
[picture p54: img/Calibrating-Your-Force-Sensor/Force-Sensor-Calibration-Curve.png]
Force Sensor Calibration Curve in Resistance [Ω] vs. Force [N]
     

----

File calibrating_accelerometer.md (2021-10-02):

# Calibrating Your Accelerometer
From the force gauge, an accelerometer can be constructed by adding a proof mass to the end of the cantilever. In this guide we will be instructing how to print and calibrate a functional accelerometer. This accelerometer will have the ability to measure the proportion of gravity experienced as it is rotated.

## Materials and Preparation
-  An accelerometer of the following design characteristics. An untested accelerometer with these defaults can be found from `mid_str_4T_sensing_and_elem.SLDPRT`.
    
     
    
    - A known proof mass at to the end of the cantilever beam. A metal ball can be mounted in the proof mass slot to increase the sensitivity of the sensor.
    - A relatively thick cantilever base to avoid unwanted deflection, emulating being embedded into your comparably large parent 3D printed structure. If you would prefer to lessen your print time, the cantilever can be glued to a piece of wood to act as the base.
    - A reference set of conductive traces to correct for changes in temperature and humidity
    - 4-terminal sensing in each set of conductive traces
    - Large electrical contact pads
    - Spaces for the lower jaws of the crocodile clips (optional)
        
 -  An insulated double-ended crocodile clip jumper (or conductive paint/epoxy and lengths of thin wire stripped of their insulation on both ends) for *each* electrical contact- A computer with the Arduino IDE (recommended) installed
- A computer with the Arduino IDE (recommended) installed
- A microcontroller with at least 1 analog input pin, such as an Arduino (recommended) Uno or Nano, and its USB cable
- A sensor with conductive traces for 2-terminal sensing
- Three potentiometers of magnitudes containing the range of your sensing element
- A test station that can perform a tumble test. See here for instructions on preparing a suitable test station.
- 2 lengths of solid core hook-up wire stripped of its insulation on both ends
- 2 insulated crocodile clip jumpers (double-ended)
- A dividing head to perform the tumble test, please see **Performing the Tumbling Test** for more information. A sample model and additional instructions can be found in **Printing the Tumbling Test Rig**
- A mounting method to affix the accelerometer to the dividing head

## Instructions

 1. Mount your clamp/vice on a table as shown above.
    
 2. Clamp onto your force sensor's cantilever base without the conductive traces being touched as shown above. Leave room for your crocodile clips if you are using them, room for the cantilever beam to bend downward, and room to suspend your weights from the cantilever beam's free end.
    
 3. Tie your string or spare wire securely to the free end hole as shown above. Ensure that its mass is nearly 0 grams beforehand.
    
 4. Tie a loop at the other end of your string or spare wire.
    
 5. If you are not using weights with hooks, hang a lightweight clear plastic pouch from the loop to hold them as shown above but without its weights. Ensure that its mass is nearly 0 grams beforehand.
    
 6. Clip one end of your crocodile clip jumpers into the terminal slots, onto the surfaces of the electrical terminals as shown above (or follow the instructions in **Preparing Electrical Contacts**).
 7. Prepare the mount for the accelerometer, the accelerometer should be mounted to the dividing head such that the sensing direction be perpendicular to the axis of rotation.

## Performing the Tumbling Test
This guide is intended to assist in printing the tumble test. As per **IEEE Std 1293-2018 12.3.12**, a *4-point tumbling test* is performed to measure temperature hysteresis. From this test the accelerometer characteristics can be determined at varying temperatures.

Note: Accelerometer performance is commonly influenced by temperature, including 3D printed sensors.

The procedure for a tumbling test is as following:
1.  Record the temperature of the test environment
2. 	Rotate the dividing head to the 90° position (input reference axis up).
Record resistance output by the accelerometer output as E90.
3. 	Rotate the dividing head to the 270° position (input reference axis down).
Record resistance output by the accelerometer the accelerometer output as E270.
4.	Rotate the dividing head to the 0° position (input reference axis horizontal).
Record the resistance output by the accelerometer the accelerometer output as E0.
5.	Rotate the dividing head to the 180° position (input reference axis horizontal).
Record the resistance output by the accelerometer the accelerometer output as E180.
6. Plot the resistance against the angle to generate the characteristics of your accelerometer as it is rotated
7. Plot the normalized resistance against the angle.

----

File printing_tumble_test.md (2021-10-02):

# Printing the Tumbling Test Rig
The *4-point tumbling test* is performed using a dividing head to rotate the accelerometer through set angles. In testing our sensors, our team utilized the following [dividing head](https://www.thingiverse.com/thing:1377544) found on **Thingiverse** created by user *Rimesy*. The model was rescaled for our printer using Cura. The parts were printed in several sets, using PLA and utilizing PVA supports.
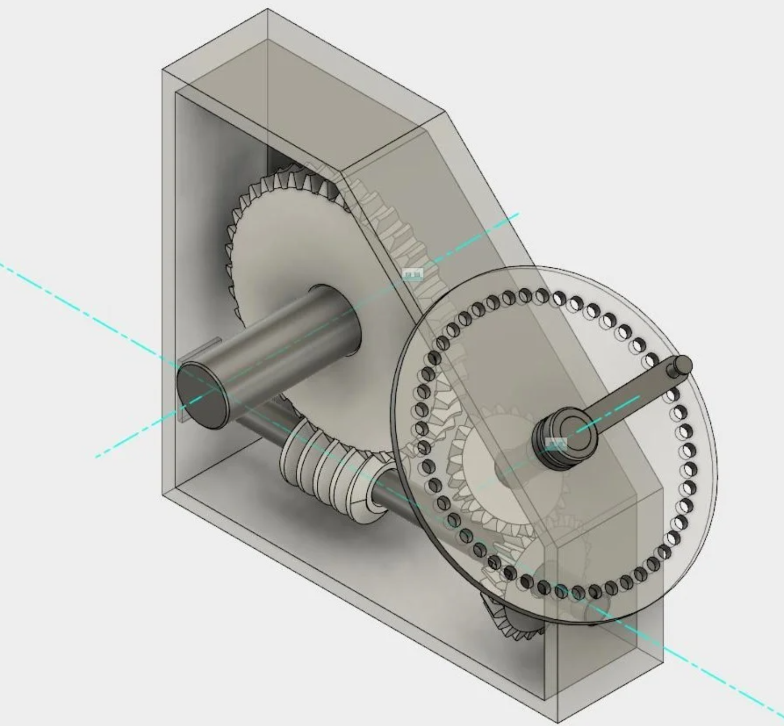
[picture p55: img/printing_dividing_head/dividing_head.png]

## Tips
- If your printer is dual extrusion capable, printing supports, especially out of PVA, will increase the quality of your prints. There are a number of overhangs, such as with the bevel gears, and long rods that benefit significantly from support.
- Divide the parts into parts that require a low printing resolution, such as the housing, rods, and ends; and high resolution parts such as the gears, and threaded rods. Printing at the respective qualities will decrease the total print time. Another sorting method would involve splitting the assembly into parts that require additional support, and those that do not.
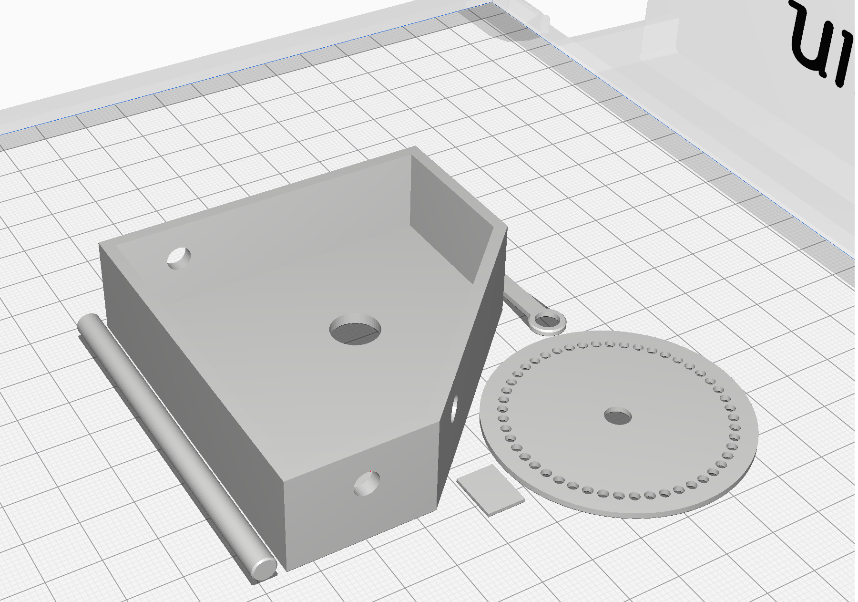
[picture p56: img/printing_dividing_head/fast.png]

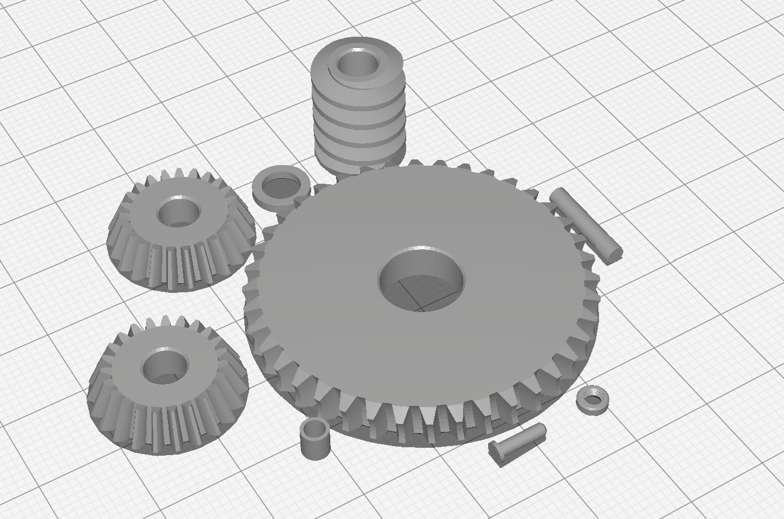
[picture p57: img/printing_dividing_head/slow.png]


- The rods should be printed on their side and are otherwise prone to following over during the print.
- The print requires two threaded bolts, scaled to the size of the inner diameter of the largest bevel gear, and the dial.

----

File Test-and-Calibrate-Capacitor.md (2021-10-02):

# How To Test and Calibrate a Capacitive Humidity Sensor
Not everyone has access to their own environmental chambers to measure humidity. Luckily, a simple calibration can be performed with a simple wet salt test.

## Materials
- 1/2 cup of table salt
- 1/4 cup of water
- An open top container to hold the solution
- A resealable bag

This test takes no less than 8 hours so be sure to give yourself time to calibrate.

**Step 1**
Prepare your capacitor so that it is able to be connected to the Pithon board. Take an initial measurement for a baseline value.

**Step 2**
Pour 1/2 cup of table salt into the container previously gathered.

**Step 3**
Pour the 1/4 cup of water into the cup on top of the salt. There shouldn't be any standing water at this point. Mix the water into the salt and pour any excess water out. The salt should have the appearance of a paste at this point.

**Step 4**
Place the container with the solution into the resealable bag. Also place your sensor in the bag at this point, but leave the board outside of the bag. 



NOTICE: High humidity could potentially damage the Pithon board.

**Step 5**
Seal the bag so that no air can enter or exit the bag. This can be assisted by taping down the entrance after the seal for added sealability. Leave the setup for at least 8 hours to give the environment a chance to reach its new relative humidity.

**Step 6**
Measure the reading from the sensor once again. This new measurement should be at 75% RH where as the original was at around 40% RH (depending on your room's climate). Using these two points, the values can be cross-referenced with the calibration curve and create its own personal calibration curve to use.

At this point, the calibration settings can be input into the software to have your measurements return data with respect to the sensor.

----

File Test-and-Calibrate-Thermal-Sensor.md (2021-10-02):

# How To Test and Calibrate a Thermal Sensor
In order to calibrate a thermal sensor with the Pithon package, it depends on how modified the original sensor is. If the original Monti sensor is used, the sensor can be calibrated with one simple measurement. If you've made modifications from the original, it's characteristic curve must be found.

## Calibrating Monti Provided Sensor
With Monti's initial design, the characteristic curve from sensor to sensor is nearly identical. To save the user the time and challenge of taking the data points for a calibration curve, with Monti's sensor only a baseline value must be input. To accomplish this, follow the steps below.

**Step 1**
Connect your 4-point temperature sensor to the Arduino microcontroller as described in [4-Terminal Sensing For Real Time Data Logging](https://github.com/keeganmjgreen/3D-Printed-Sensors-Development-Platform/blob/main/4-Terminal-Sensing-for-Real-Time-Data-Logging-Using-a-Microcontroller.md). If you are using a source/measurement unit (SMU) rather than an Arduino, apply force and sense connections as shown.
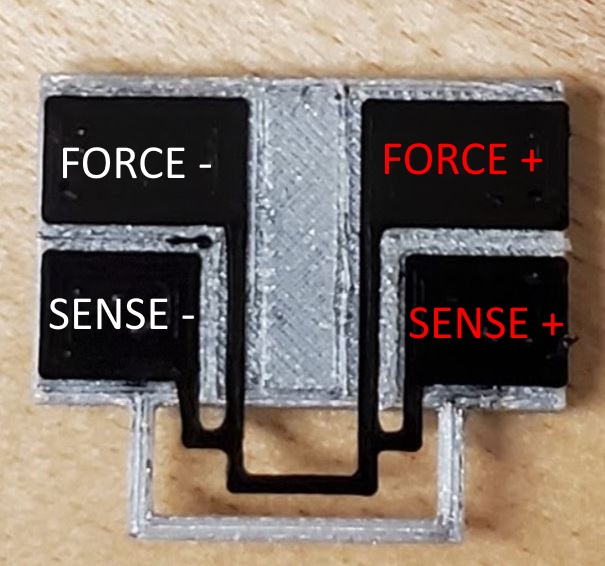
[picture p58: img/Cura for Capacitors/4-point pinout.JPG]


**Step 2**
Open the Monti signal processing and calibration software.

**Step 3**
Gather a temperature measuring device (thermometer or others). Take note of the current temperature and input that into the software when prompted.

**Step 4**
With the Monti software, the software will automatically calculate the calibration curve at this point. If using an external device, take note of the resistance given by the device. Enter this value into the Arduino program when ready.

At this point, the original Monti thermal sensor is calibrated and ready for use.

## Calibrating Custom Thermal Sensor
When creating a brand new thermal sensor design, the sensor's distinct calibration curve. In order to do this, an oven or environmental chamber will be required to calibrate the best curve.

**Step 1**
Follow the same step as you would when calibrating the original Monti sensor. With a 2-pont sensor, follow the setup described at [2-Terminal Sensing for Real-Time Data Logging Using a Microcontroller](https://github.com/keeganmjgreen/3D-Printed-Sensors-Development-Platform/blob/main/2-Terminal-Sensing-for-Real-Time-Data-Logging-Using-a-Microcontroller.md).

**Step 2**
Place the sensor in the oven or environmental chamber. At this point, make sure that there is some way to monitor temperatuer in the chamber.

**Step 3**
Begin logging data and increase the temperature of the chamber.



*Caution*: Your heating chamber can become very hot. Exercise caution when dealing with hot devices.

If your heating chamber does not log temperature over time, make sure to make note of the temperature at every minute with the help of a timing device. If your measurement device doesn't log resistance over time, also take note of the resistances every minute. Continue the test until the temperature stabilizes at 50 degrees Celsius. 



NOTICE: Increasing the temperature higher than 50 degrees Celsius may cause permanent damage to the sensor

**Step 4**
Export both data and correspond temperature and resistances with respect to time. Input these values into the software. If you measured temperature by hand, only enter values in at every 60 second mark. If you measured resistance by hand, do the same for that. The software will then create the calibration curve.

At this point, the custom sensor you have designed has been calibrated and is ready for use.

----

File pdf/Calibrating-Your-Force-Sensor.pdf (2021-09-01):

# Calibrating Your Force Sensor

# Materials and Preparation

An untested force sensor with the following defaults from mid_str_4T_sensing_and_elem.SLDPRT .

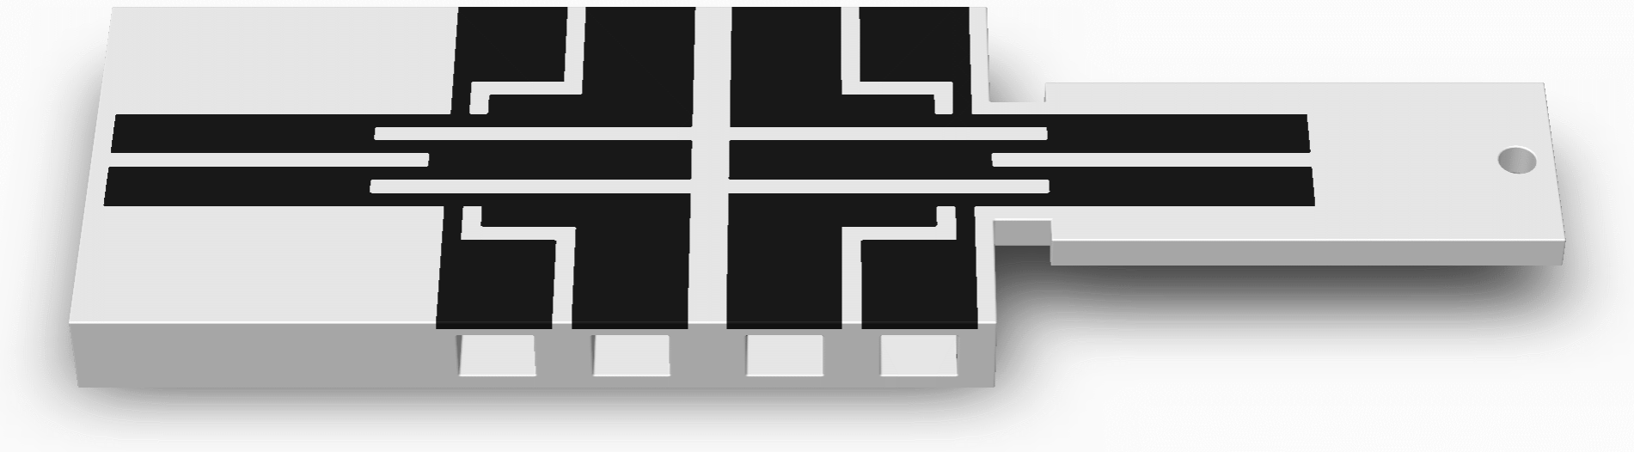
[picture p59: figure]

A hole close to the end of the cantilever beam (“Free End Hole” in the SolidWorks part) from which to suspend known weights
If you would like to use a force sensor that you have already printed without a free end hole, you can drill or punch a hole in the same place.
A similarly thick cantilever base to avoid unwanted deflection, emulating being embedded into your comparably large parent 3D printed structure
If you do not need spaces for the lower jaws of crocodile clips in a thick cantilever base, and would prefer it to lessen your print time, you can glue a thinner cantilever base to a piece of wood to be used as the cantilever base.
A reference set of conductive traces to correct for changes in temperature and humidity (recommended)
4-terminal sensing in each set of conductive traces (recommended)
Large electrical contact pads
Spaces for lower jaws of crocodile clips (optional)

An insulated double-ended crocodile clip jumper (or conductive paint/epoxy and lengths of thin wire stripped of their insulation on both ends) for each electrical contact
A table clamp/vice
Some string or more thin wire
A laboratory weight set or similar


A test rig of a force sensor that has a 1-mm cantilever beam and no reference set of conductive traces. Also shown are its crocodile clips, table clamp, and known weights in a pouch suspended by a wire from the cantilever beam’s free end hole.

# Instructions

1. Mount your clamp/vice on a table as shown above.
2. Clamp onto your force sensor’s cantilever base without the conductive traces being touched as shown above. Leave room for your crocodile clips if you are using them, room for the cantilever beam to bend downward, and room to suspend your weights from the cantilever beam’s free end.
3. Tie your string or spare wire securely to the free end hole as shown above. Ensure that its mass is nearly 0 grams beforehand.
4. Tie a loop at the other end of your string or spare wire.
5. If you are not using weights with hooks, hang a lightweight clear plastic pouch from the loop to hold them as shown above but without its weights. Ensure that its mass is nearly 0 grams beforehand.
6. Clip one end of your crocodile clip jumpers into the terminal slots, onto the surfaces of the electrical terminals as shown above (or follow the instructions in Preparing Electrical Contacts).
7. Now, assuming that you are using an Arduino microcontroller, open its IDE on your computer.

8. Follow 2-Terminal Sensing for Real-Time Data Logging Using a Microcontroller or 4-Terminal Sensing for Real-Time Data Logging Using a Microcontroller as applicable per set of conductive traces. Use the Arduino Serial Monitor, and make the following changes to the code under Instructions – Programming.
1. Immediately after Serial.begin(9600) , append Serial.setTimeout(100); . This strikes a
balance between a good sampling frequency (almost 10 per second) and stability over serial communication.
2. Immediately before the end of the loop() function, append

Serial.print(Serial.readStringUntil("\r\n")); . This will loop-back text that you enter in
your serial monitor to log it for reasons that will become apparent.
9. Plug in your Arduino using its USB cable.
10. Upload your modified code to the board using the Arduino IDE, after which it will begin running onboard.
11. In your Arduino IDE, open the serial monitor. You should see lines of electrical resistance values (in ohms) updated in real time from your sensor using your Arduino.
12. Wait momentarily while recording data – say, roughly 100 samples. Be careful not to touch your sensor or its load.
13. Type “0 grams” into your serial monitor and Send this message to your Arduino and back (to record it conveniently in the same place) for the purpose of marking an upcoming change to the applied load.

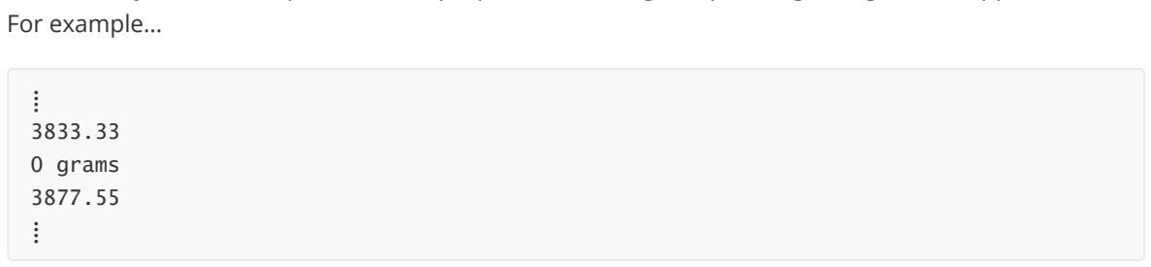
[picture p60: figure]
For example…; 0 grams

14. Gently suspend the smallest weight – say, 4 grams – from the cantilever beam’s free end hole and wait briefly for your cantilever beam to settle under its new load.
15. Then, enter “4 grams” into your serial monitor. For example…
16. Repeat the last 4 steps for further incremental sums of masses.
17. Unplug your Arduino. Your serial monitor will ‘freeze’.
18. Copy the partitioned runs of resistance data and save them into a text file, Excel workbook, etc. For example…

Column 1

⁞

3833.33

0 grams

3877.55

⁞

3884.76

4 grams

3877.55

⁞

Number of weights | Mass in grams | Resistance in ohms
⁞ | ⁞ | ⁞
0 | 0 | 3870.37
0 | 0 | 3851.85
0 | 0 | 3833.33
1 | 4 | 3877.55
1 | 4 | 3870.37
1 | 4 | 3851.85
⁞ | ⁞ | ⁞
19. Discard the resistance values between framed weight increments as being subject to the impulses of suddenly loading and unloading weights. For example…
20. Average the resistance values within framed weight increments as only being subject to measurement noise. For example…

Number of weights | Mass in grams | Resistance in ohms | Number of samples
0 | 0 | 3860.91 | 200
1 | 4 | 3866.34 | 54
2 | 8 | 3874.94 | 192
3 | 12 | 3877.61 | 165
4 | 16 | 3883.74 | 127
5 | 20 | 3889.58 | 3491
6 | 24 | 3896.26 | 127
7 | 28 | 3903.50 | 101
8 | 32 | 3912.05 | 138
9 | 36 | 3919.69 | 153
10 | 40 | 3931.75 | 272
Force in Newtons | Resistance in ohms
0.00 | 3860.91
0.04 | 3866.34
0.08 | 3874.94
0.12 | 3877.61
0.16 | 3883.74
0.20 | 3889.58
0.24 | 3896.26
0.28 | 3903.50
0.32 | 3912.05
0.36 | 3919.69
0.40 | 3931.75
21. Convert the masses (in units of grams) to force values (in units of Newtons) by multiplying them by 10 ≈ 9.81 m/s². For example…

22. Plot resistance against force. For example…

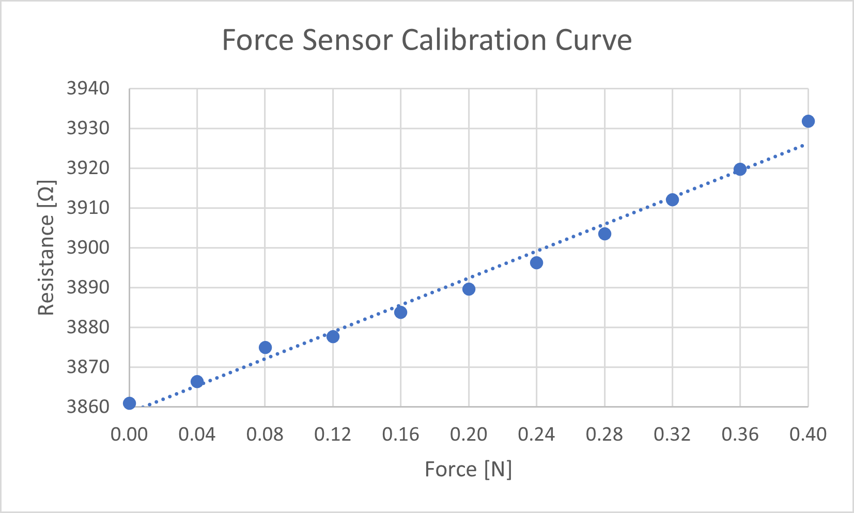
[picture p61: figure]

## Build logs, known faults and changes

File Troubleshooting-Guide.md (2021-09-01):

[Download as PDF](https://raw.githubusercontent.com/keeganmjgreen/3D-Printed-Sensors-Development-Platform/main/pdf/Troubleshooting-Guide.pdf)

----

# Troubleshooting Guide #

**Conductive filament is not extruding.**

Conductive filament is typically quite brittle; the 3D printer's feeder can wear down the filament causing debris or dust to build up in the feeder. If not routinely cleaned, this debris can build up and cause the feeder to jam. Additionally, if the 3D printer's feeder has too high of a tension, it can cause the conductive filament to crack or split, preventing the feeder from functioning. Start by manually removing and the conductive filament. Observe the filament for obvious defects such as fractures. Using a pair of scissors, remove any visibly damaged region of filament. Reload the conductive filament into the 3D printer. If the problem persists, disassemble and clean your 3D printer's feeder mechanism. Finally, if the problem is still occurring, try reducing the tension of the feeder. Perform the above actions as per your 3D printer's User Manual.

**The sensor is not sticking to the print bed during printing.**

Separation from the print bed can occur if there is insufficient friction between the print bed and the print, or if there is any debris on the print bed. Start by thoroughly cleaning the print bed as per your printer's user manual. If the problem persists, try applying a layer of painter's tape to the print bed. Painter's tape will increase the friction between the print bed and the print, reducing risk of separation.

**I cannot remove the conductive filament from the printer.**

If care is not taken to routinely clean the printer's feeder when using conductive filament, debris can build up in the printer's feeder and nozzle. In extreme cases this can cause the filament to jam, making it very difficult to remove. If this occurs, follow your 3D printer's User Manual's Troubleshooting Guide. It should contain a section on how to manually remove jammed filament. After removing the filament, thoroughly clean the 3D printer's feeder and nozzle before reloading the material.

**The print quality of my sensor is poor.**

The most common cause of poor print quality when working with conductive filament is an insufficiently cleaned printer. Following your 3D printer's User Manual, try the following actions. Either complete the entire list, or complete each item separately and test printer performance after every step.

- Manually unload the conductive filament. Observe the conductive filament for obvious defects such as splits or fractures. Using a pair of scissors, remove all areas that have visible defects. Reload the conductive filament.
- Thoroughly clean the print bed.
- Disassemble the 3D printer's feeder. Using a compressed air canister, thoroughly clean any debris build up. Reassemble the feeder and reload the conductive filament.
- Manually unload the conductive filament. Load a generic PLA filament (non-conductive) and print a structure. Printing with an easier-to-print filament may dislodge any plastic stuck in the nozzle, resulting in higher quality prints.

**My capacitor has no measurable capacitance.**

The most likely issue is that the capacitor is shorted. Using a standard multimeter, measure the resistance across the capacitor. The measured resistance should be 'OL' for overload or in the megaohm (MΩ) range. If the resistance is lower, the capacitor is shorted. Try improving the print quality of your 3D printer by following the suggestion provided above in Troubleshooting Guide: 'The print quality of my sensor is poor'. Attempt to print the capacitor again. A properly functioning 3D printer should not produce shorted capacitors.

----

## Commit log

2021-05-26 Update Product-Manual-Elements-Ultimaker-3D-Printer.md
    Linked to *Ultimaker* website from title and to the *Ultimaker 3 Extended* PDF manual.
2021-05-26 Update Product-Manual-Elements-Ultimaker-3D-Printer.md
    Removed last file line (despite convention).
2021-05-27 Update Product-Manual-Elements-Ultimaker-3D-Printer.md
    Prefixed page with link to *Ultimaker 3* -- Ultimaker Support.
2021-05-27 Update Product-Manual-Elements-Ultimaker-3D-Printer.md
    Linked to Error Messages -- Ultimaker Support, under *7. Troubleshooting*.
2021-05-27 Update index.rst
    Included *Product Manual Elements: Arduino Language Reference* under TOC tree.
2021-06-15 Update 3D-Printed-Sensors-Manual-Outline.md
    Removed "Preliminary" from title.
2021-07-18 Add files via upload
    Added Preparing-Capacitor-In-Cura.md
    Still needs images but base text is present
2021-07-18 Add files via upload
    Added pictures for the Preparing-Capacitors-In-Cura.md page, more to come
2021-07-20 Add files via upload
    Added Preparing-Thermal-Sensor-In-Cura.md and updated Preparing-Capacitor-In-Cura.md
2021-07-20 Add files via upload
    Added Test-and-Calibrate-Capacitor.md
2021-07-20 Add files via upload
    Added Test-and-Calibrate-Thermal-Sensor.md
2021-07-23 Update and rename Creating-and-Modifying-Mask-Layouts-for-Sensor-Designs.md to Creating-and-Modifying-Mask-Layouts-for-Sensor-Designs
2021-07-24 Update and rename Example-Process-Flow.md to Example-Process-Flow
2021-10-02 Uploaded selected force sensor calibration data collection, preparation, and processing scripts. Linked from headings under `Pithon-Software.md`.
2021-10-02 Organized force sensor calibration scripts. Replaced "manual-demo" with "development-platform".
2021-10-11 Uploaded Pithon device sample images (formerly "Photos on White Background") and established `Sample-Images.md`.
2021-10-11 Added `Sample-Images.md` to `index.rst`.
2021-10-11 Compressed Sample-Images.
2021-10-11 Better-organized `Sample-Images.md`.
2021-10-11 Scaled-down Sample-Images.
2021-10-12 Fixed HTML image syntax in `Sample-Images.md`.
2021-10-12 Revert "Fixed HTML image syntax in `Sample-Images.md`."
    This reverts commit b4322d4673b7414b5cf718e3083e95a68408d4ed.
2021-10-12 Completed image paths in `Sample-Images.md`.
2021-10-12 Reverted repo name "3D-Printed-Sensors-Development-Kit" to "3D-Printed-Sensors-Manual-Demo" where applicable to redirect anyway.
2021-10-12 Fixed image padding in `Sample-Images.md`.
2021-11-16 Fixed typo in `Example-Process-Flow.md`.
